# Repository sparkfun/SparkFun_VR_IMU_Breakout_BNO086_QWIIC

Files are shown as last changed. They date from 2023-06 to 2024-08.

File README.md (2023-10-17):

SparkFun VR IMU Breakout - BNO086 (Qwiic)
========================================

SparkFun VR IMU Breakout - BNO086 (Qwiic) (https://www.sparkfun.com/products/22857)

[*SparkFun VR IMU Breakout - BNO086 (Qwiic)(SEN-22857)*](https://www.sparkfun.com/products/22857)

The BNO086 IMU has a combination triple axis accelerometer/gyro/magnetometer packaged with an ARM Cortex M0+ running powerful algorithms.

Repository Contents
-------------------

* **/Documentation** - Datasheets, additional product information
* **/Hardware** - Eagle design files (.brd, .sch)
  * **/Production** - Production panel files (.brd)

Documentation
--------------
* **[Library](https://github.com/sparkfun/SparkFun_BNO08x_Arduino_Library)** - Arduino library for the BNO086 and variants BNO08X.
* **[Fritzing Part](https://github.com/sparkfun/Fritzing_Parts/blob/main/products/22857-sfe_vr_imu_breakout_bno086_9dof_accelerometer_gyro_magnetometer.fzpz)**
* **[Hookup Guide](https://docs.sparkfun.com/SparkFun_VR_IMU_Breakout_BNO086_QWIIC/introduction/)** - Basic hookup guide for the SparkFun VR IMU Breakout - BNO086.

Product Versions
----------------
* [SEN-22857](https://www.sparkfun.com/products/22857) - Initial release, v1.0

Version History
---------------
* v1.0 - Initial release

License Information
-------------------

This product is _**open source**_!

Please review the LICENSE.md file for license information.

If you have any questions or concerns on licensing, please contact technical support on our [SparkFun forums](https://forum.sparkfun.com/viewforum.php?f=152).

Distributed as-is; no warranty is given.

- Your friends at SparkFun.

_<COLLABORATION CREDIT>_

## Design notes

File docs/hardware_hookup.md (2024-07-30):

!!! note
    Unfortunately, users are not able to use an Arduino Uno or RedBoard with an ATmega328P due the demands of the BNO086 IC. We recommend using the ESP32.

    The Arduino Library was also tested to work with the SAMD51 as well! The pin connections between the microcontroller and sensor are the same, just make sure to reference the port name rather than the specific Arduino pin number. Make sure to also install the Arduino SAMD core and select the correct board definition.

### Connecting via Qwiic Port, Reset, & Interrupt Pins

!!! note
    As of v1.0.3, you will need to wire up the reset and interrupt pins. Using only the I<sup>2</sup>C port was not sufficient enough to get the BNO086 to work reliably with a microcontroller.  

    The I/O pins have also been changed for the reset and interrupt pins! Make sure to adjust your connections accordingly.

You will need a powerful microcontroller to process the data when using the BNO086. In this case, we used an ESP32 (we specifically tested the Arduino Library with the SparkFun IoT RedBoard - ESP32). Besides connecting a Qwiic cable, you also need to wire up the reset and interrupt pins. This is a more reliable connection and is recommended.

The table and image below shows the connections between the SparkFun IoT RedBoard - ESP32 and the BNO086. While you can use IC hooks for a temporary connection, we recommending soldering for a secure connection. You can choose between a combination of [header pins and jumper wires](https://learn.sparkfun.com/tutorials/how-to-solder-through-hole-soldering/all), or [stripping wire and soldering the wire](https://learn.sparkfun.com/tutorials/working-with-wire/all) directly to the board.

<div class="grid cards col-4" markdown>

-   <a href="https://learn.sparkfun.com/tutorials/how-to-solder-through-hole-soldering/all">
      <figure markdown>
        How to Solder: Through Hole Soldering
      </figure>
    </a>

    ---

    <a href="https://learn.sparkfun.com/tutorials/how-to-solder-through-hole-soldering/all">
      <b>How to Solder: Through Hole Soldering</b>
    </a>
<!-- ----------WHITE SPACE BETWEEN GRID CARDS---------- -->
-   <a href="https://learn.sparkfun.com/tutorials/working-with-wire/all">
      <figure markdown>
        Working with Wire
      </figure>
    </a>

    ---

    <a href="https://learn.sparkfun.com/tutorials/working-with-wire/all">
      <b>Working with Wire</b>
    </a>
<!-- ----------WHITE SPACE BETWEEN GRID CARDS---------- -->
</div>

<div style="text-align: center;">
    <table>
        <tr>
            <th style="text-align: center; border: solid 1px #cccccc;">RedBoard IoT - ESP32
            </th>
            <th style="text-align: center; border: solid 1px #cccccc;">VR IMU Breakout - BNO086
            </th>
        </tr>
        <tr>
            <td style="text-align: center; border: solid 1px #cccccc;" bgcolor="#f2dede"><font color="#000000">3.3V (3.3V, Qwiic Port)</font>
            </td>
            <td style="text-align: center; border: solid 1px #cccccc;" bgcolor="#f2dede"><font color="#000000">3.3V</font>
            </td>
        </tr>
        <tr>
            <td style="text-align: center; border: solid 1px #cccccc;" bgcolor="#DDDDDD"><font color="#000000">GND (GND, Qwiic Port)</font>
            </td>
            <td style="text-align: center; border: solid 1px #cccccc;" bgcolor="#DDDDDD"><font color="#000000">GND</font>
            </td>
        </tr>
        <tr>
            <td style="text-align: center; border: solid 1px #cccccc;" bgcolor="#fff3cd"><font color="#000000">SCL (D22, Qwiic Port)</font>
            </td>
            <td style="text-align: center; border: solid 1px #cccccc;" bgcolor="#fff3cd"><font color="#000000">SCL</font>
            </td>
        </tr>
        <tr>
            <td style="text-align: center; border: solid 1px #cccccc;" bgcolor="#cce5ff"><font color="#000000">SDA (D21, Qwiic Port)</font>
            </td>
            <td style="text-align: center; border: solid 1px #cccccc;" bgcolor="#cce5ff"><font color="#000000">SDA</font>
            </td>
        </tr>    
        <tr>
            <td style="text-align: center; border: solid 1px #cccccc;" bgcolor="#cce5ff"><font color="#000000">A4</font>
            </td>
            <td style="text-align: center; border: solid 1px #cccccc;" bgcolor="#cce5ff"><font color="#000000">INT</font>
            </td>
        </tr>
        <tr>
            <td style="text-align: center; border: solid 1px #cccccc;" bgcolor="#d4edda"><font color="#000000">A5</font>
            </td>
            <td style="text-align: center; border: solid 1px #cccccc;" bgcolor="#d4edda"><font color="#000000">RST</font>
            </td>
        </tr>
    </table>
</div>

<div style="text-align: center;">
  <table>
    <tr style="vertical-align:middle;">
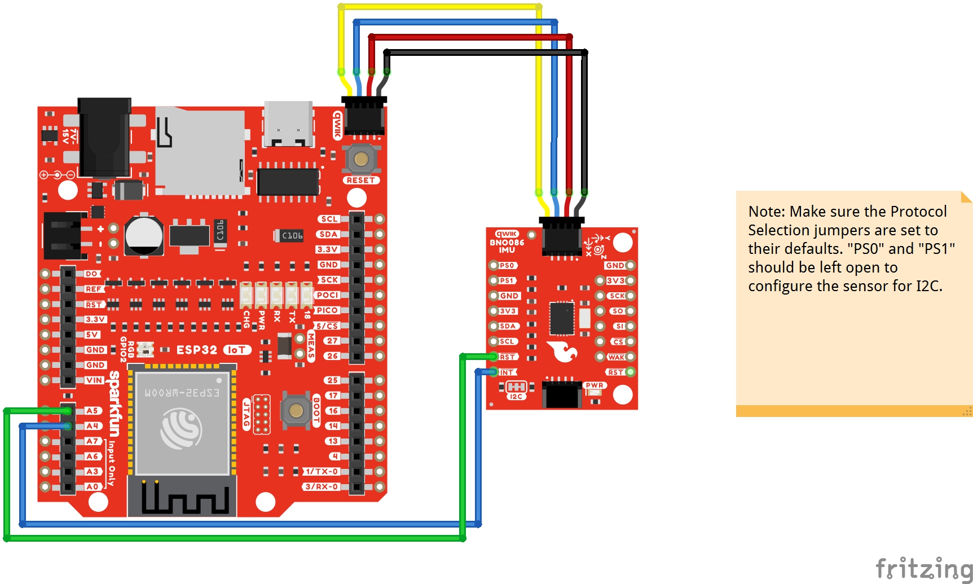
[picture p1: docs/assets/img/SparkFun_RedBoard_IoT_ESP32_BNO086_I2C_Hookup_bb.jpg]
Hookup with ESP32 between the BNO086 using the Qwiic Port, Interrupt, and Reset Pins
     <td style="text-align: center; vertical-align: middle;"></td>
    </tr>
  </table>
</div>

!!!note
    For users using a different communication protocol, make sure to adjust the solder joints for PS0 and PS1 before connecting to a UART or SPI port.

### Connecting via UART

For users interested in using the serial UART protocol to communicate with the sensor through a computer's USB port, you can connect a serial-to-USB connector directly to the board.

Before connecting, make sure to add a solder jumper on PS1 to configure the board for UART protocol as stated earlier in the Hardware Overview.

<div style="text-align: center;">
    <table>
        <tr>
            <th style="text-align: center; border: solid 1px #cccccc;">PS0
            </th>
            <th style="text-align: center; border: solid 1px #cccccc;">PS1
            </th>
            <th style="text-align: center; border: solid 1px #cccccc;">Interface
            </th>
            <th style="text-align: center; border: solid 1px #cccccc;">Note
            </th>
        </tr>
        <tr>
            <td style="text-align: center; border: solid 1px #cccccc;">0
            </td>
            <td style="text-align: center; border: solid 1px #cccccc;">0
            </td>
            <td style="text-align: center; border: solid 1px #cccccc;">I<sup>2</sup>C
            </td>
            <td style="text-align: center; border: solid 1px #cccccc;">
            </td>
        </tr>
        <tr>
            <td style="text-align: center; border: solid 1px #cccccc;">1
            </td>
            <td style="text-align: center; border: solid 1px #cccccc;">0
            </td>
            <td style="text-align: center; border: solid 1px #cccccc;">UART-RVC
            </td>
            <td style="text-align: center; border: solid 1px #cccccc;">
            </td>
        </tr>
        <tr>
            <td style="text-align: center; border: solid 1px #cccccc;" bgcolor="#f2dede"><font color="#000000">0</font>
            </td>
            <td style="text-align: center; border: solid 1px #cccccc;" bgcolor="#f2dede"><font color="#000000">1</font>
            </td>
            <td style="text-align: center; border: solid 1px #cccccc;" bgcolor="#f2dede"><font color="#000000">UART</font>
            </td>
            <td style="text-align: center; border: solid 1px #cccccc;" bgcolor="#f2dede"><font color="#000000">Add solder blob to the jumper to set to 1.</font>
            </td>
        </tr>
        <tr>
            <td style="text-align: center; border: solid 1px #cccccc;">1
            </td>
            <td style="text-align: center; border: solid 1px #cccccc;">1
            </td>
            <td style="text-align: center; border: solid 1px #cccccc;"">SPI
            </td>
            <td style="text-align: center; border: solid 1px #cccccc;">
            </td>
        </tr>
    </table>
</div>

The table below shows how to connect the VR IMU Breakout BNO086's UART port to a Serial Basic. You can angle header pins against the PTHs and hold the boards together with one hand for a temporary connection. However, we recommending soldering to the connection for a reliable and secure connection. You can choose between a combination of [header pins and jumper wires](https://learn.sparkfun.com/tutorials/how-to-solder-through-hole-soldering/all), or [stripping wire and soldering the wire](https://learn.sparkfun.com/tutorials/working-with-wire/all) directly to the board.

<div style="text-align: center;">
    <table>
        <tr>
            <th style="text-align: center; border: solid 1px #cccccc;">VR IMU Breakout - BNO086
            </th>
            <th style="text-align: center; border: solid 1px #cccccc;">3.3V Serial Basic
            </th>
            <th style="text-align: center; border: solid 1px #cccccc;">Wire Color
            </th>
        </tr>
        <tr>
            <td style="text-align: center; border: solid 1px #cccccc;" bgcolor="#DDDDDD"><font color="#000000">GND</font>
            </td>
            <td style="text-align: center; border: solid 1px #cccccc;" bgcolor="#DDDDDD"><font color="#000000">GND</font>
            </td>
            <td style="text-align: center; border: solid 1px #cccccc;" bgcolor="#DDDDDD"><font color="#000000">BLK</font>
            </td>
        </tr>
        <tr>
            <td style="text-align: center; border: solid 1px #cccccc;" bgcolor="#C4A484"><font color="#ffffff"></font>
            </td>
            <td style="text-align: center; border: solid 1px #cccccc;" bgcolor="#C4A484"><font color="#ffffff">CTS</font>
            </td>
            <td style="text-align: center; border: solid 1px #cccccc;" bgcolor="#C4A484"><font color="#ffffff"></font>
            </td>
        </tr>
        <tr>
            <td style="text-align: center; border: solid 1px #cccccc;" bgcolor="#f2dede"><font color="#000000">3V3</font>
            </td>
            <td style="text-align: center; border: solid 1px #cccccc;" bgcolor="#f2dede"><font color="#000000">3.3V</font>
            </td>
            <td style="text-align: center; border: solid 1px #cccccc;" bgcolor="#f2dede"><font color="#000000"></font>
            </td>
        </tr>
        <tr>
            <td style="text-align: center; border: solid 1px #cccccc;" bgcolor="#ffdaaf"><font color="#000000">RXI</font>
            </td>
            <td style="text-align: center; border: solid 1px #cccccc;" bgcolor="#ffdaaf"><font color="#000000">TXO</font>
            </td>
            <td style="text-align: center; border: solid 1px #cccccc;" bgcolor="#ffdaaf"><font color="#000000"></font>
            </td>
        </tr>
        <tr>
            <td style="text-align: center; border: solid 1px #cccccc;" bgcolor="#fff3cd"><font color="#000000">TXO</font>
            </td>
            <td style="text-align: center; border: solid 1px #cccccc;" bgcolor="#fff3cd"><font color="#000000">RXI</font>
            </td>
            <td style="text-align: center; border: solid 1px #cccccc;" bgcolor="#fff3cd"><font color="#000000"></font>
            </td>
        </tr><tr>
            <td style="text-align: center; border: solid 1px #cccccc;" bgcolor="#d4edda"><font color="#000000"></font>
            </td>
            <td style="text-align: center; border: solid 1px #cccccc;" bgcolor="#d4edda"><font color="#000000">DTR</font>
            </td>
            <td style="text-align: center; border: solid 1px #cccccc;" bgcolor="#d4edda"><font color="#000000">GRN</font>
            </td>
        </tr>
    </table>
</div>

!!!note
    You will need to be careful when soldering header pins to the edge pins and the UART located at the center of the board. For users that solder header pins to the edge of the board to mate with a breadboard, you will need to solder header pins facing the other way for the UART header so that the center pins do not connect to the same rails. The same goes with users that are using right angle header pins as well.

    Of course, you can cut a [six wire jumper wire cable](https://www.sparkfun.com/products/10371) and wire strip them before connecting to the 1x6 header as well.

The UART interface is in the middle of the board, with the black and green pins labeled as BLK and GRN. As stated earlier, these serial pins have been arranged to work with our [Serial Basic](https://www.sparkfun.com/products/15096) board to make interfacing to a computer simple and fast. Once the header pins are soldered, align the GRN and BLK labels so that the serial connection is properly connected and slide the male header pins into the female header sockets.

<div style="text-align: center;">
  <table>
    <tr style="vertical-align:middle;">
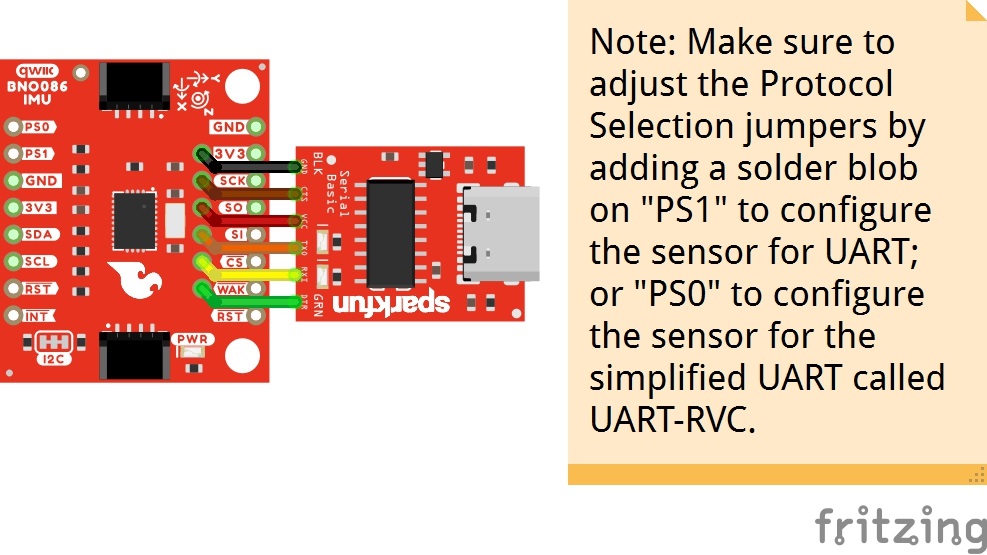
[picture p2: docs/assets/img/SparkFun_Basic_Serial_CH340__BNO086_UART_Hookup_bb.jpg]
Fritzing Diagram with FTDI Connected to BNO086 Breakout via UART Port
     <td style="text-align: center; vertical-align: middle;"></td>
    </tr>
  </table>
</div>

### Connecting via SPI

For users interested in using the [SPI protocol](https://learn.sparkfun.com/tutorials/serial-peripheral-interface-spi) to communicate with the sensor, there are few examples in the Arduino Library. You can use those examples as a basis to adjust the I<sup>2</sup>C examples to use it with SPI.

Before connecting, make sure to add a solder jumper on PS0 and PS1 to configure the board for SPI protocol as stated earlier in the Hardware Overview.

!!! note
    As of v1.0.3, the I/O pins have also been changed for the CS, reset, interrupt pins! Make sure to adjust your connections accordingly.

<div style="text-align: center;">
    <table>
        <tr>
            <th style="text-align: center; border: solid 1px #cccccc;">PS0
            </th>
            <th style="text-align: center; border: solid 1px #cccccc;">PS1
            </th>
            <th style="text-align: center; border: solid 1px #cccccc;">Interface
            </th>
            <th style="text-align: center; border: solid 1px #cccccc;">Note
            </th>
        </tr>
        <tr>
            <td style="text-align: center; border: solid 1px #cccccc;">0
            </td>
            <td style="text-align: center; border: solid 1px #cccccc;">0
            </td>
            <td style="text-align: center; border: solid 1px #cccccc;">I<sup>2</sup>C
            </td>
            <td style="text-align: center; border: solid 1px #cccccc;">
            </td>
        </tr>
        <tr>
            <td style="text-align: center; border: solid 1px #cccccc;">1
            </td>
            <td style="text-align: center; border: solid 1px #cccccc;">0
            </td>
            <td style="text-align: center; border: solid 1px #cccccc;">UART-RVC
            </td>
            <td style="text-align: center; border: solid 1px #cccccc;">
            </td>
        </tr>
        <tr>
            <td style="text-align: center; border: solid 1px #cccccc;">0
            </td>
            <td style="text-align: center; border: solid 1px #cccccc;">1
            </td>
            <td style="text-align: center; border: solid 1px #cccccc;">UART
            </td>
            <td style="text-align: center; border: solid 1px #cccccc;">
            </td>
        </tr>
        <tr>
            <td style="text-align: center; border: solid 1px #cccccc;" bgcolor="#f2dede"><font color="#000000">1</font>
            </td>
            <td style="text-align: center; border: solid 1px #cccccc;" bgcolor="#f2dede"><font color="#000000">1</font>
            </td>
            <td style="text-align: center; border: solid 1px #cccccc; "bgcolor="#f2dede"><font color="#000000">SPI</font>
            </td>
            <td style="text-align: center; border: solid 1px #cccccc;" bgcolor="#f2dede"><font color="#000000">Add solder blob to the jumpers to set to 1.</font>
            </td>
        </tr>
    </table>
</div>

The table below shows how to connect the SparkFun IoT RedBoard - ESP32 to the VR IMU Breakout BNO086's SPI port. As stated earlier for the I<sup>2</sup>C, you could use IC hooks for initial testing. However, we recommending soldering to the connection for a reliable and secure connection. You can choose between a combination of [header pins and jumper wires](https://learn.sparkfun.com/tutorials/how-to-solder-through-hole-soldering/all), or [stripping wire and soldering the wire](https://learn.sparkfun.com/tutorials/working-with-wire/all) directly to the board.

<div style="text-align: center;">
    <table>
        <tr>
            <th style="text-align: center; border: solid 1px #cccccc;">RedBoard IoT - ESP32
            </th>
            <th style="text-align: center; border: solid 1px #cccccc;">VR IMU Breakout - BNO086
            </th>
        </tr>
        <tr>
            <td style="text-align: center; border: solid 1px #cccccc;" bgcolor="#f2dede"><font color="#000000">3.3V</font>
            </td>
            <td style="text-align: center; border: solid 1px #cccccc;" bgcolor="#f2dede"><font color="#000000">3.3V</font>
            </td>
        </tr>
        <tr>
            <td style="text-align: center; border: solid 1px #cccccc;" bgcolor="#DDDDDD"><font color="#000000">GND</font>
            </td>
            <td style="text-align: center; border: solid 1px #cccccc;" bgcolor="#DDDDDD"><font color="#000000">GND</font>
            </td>
        </tr>
        <tr>
            <td style="text-align: center; border: solid 1px #cccccc;" bgcolor="#cce5ff"><font color="#000000">D5</font>
            </td>
            <td style="text-align: center; border: solid 1px #cccccc;" bgcolor="#cce5ff"><font color="#000000">CS</font>
            </td>
        </tr>
        <tr>
            <td style="text-align: center; border: solid 1px #cccccc;" bgcolor="#ffdaaf"><font color="#000000">PICO (D23)</font>
            </td>
            <td style="text-align: center; border: solid 1px #cccccc;" bgcolor="#ffdaaf"><font color="#000000">SI</font>
            </td>
        </tr>
        <tr>
            <td style="text-align: center; border: solid 1px #cccccc;" bgcolor="#ffffff"><font color="#000000">POCI (D19)</font>
            </td>
            <td style="text-align: center; border: solid 1px #cccccc;" bgcolor="#ffffff"><font color="#000000">SO</font>
            </td>
        </tr>
        <tr>
            <td style="text-align: center; border: solid 1px #cccccc;" bgcolor="#fff3cd"><font color="#000000">SCK (D18)</font>
            </td>
            <td style="text-align: center; border: solid 1px #cccccc;" bgcolor="#fff3cd"><font color="#000000">SCK</font>
            </td>
        </tr>    
        <tr>
            <td style="text-align: center; border: solid 1px #cccccc;" bgcolor="#cce5ff"><font color="#000000">A4</font>
            </td>
            <td style="text-align: center; border: solid 1px #cccccc;" bgcolor="#cce5ff"><font color="#000000">INT</font>
            </td>
        </tr>
        <tr>
            <td style="text-align: center; border: solid 1px #cccccc;" bgcolor="#d4edda"><font color="#000000">A5</font>
            </td>
            <td style="text-align: center; border: solid 1px #cccccc;" bgcolor="#d4edda"><font color="#000000">RST</font>
            </td>
        </tr>
    </table>
</div>

<div style="text-align: center;">
  <table>
    <tr style="vertical-align:middle;">
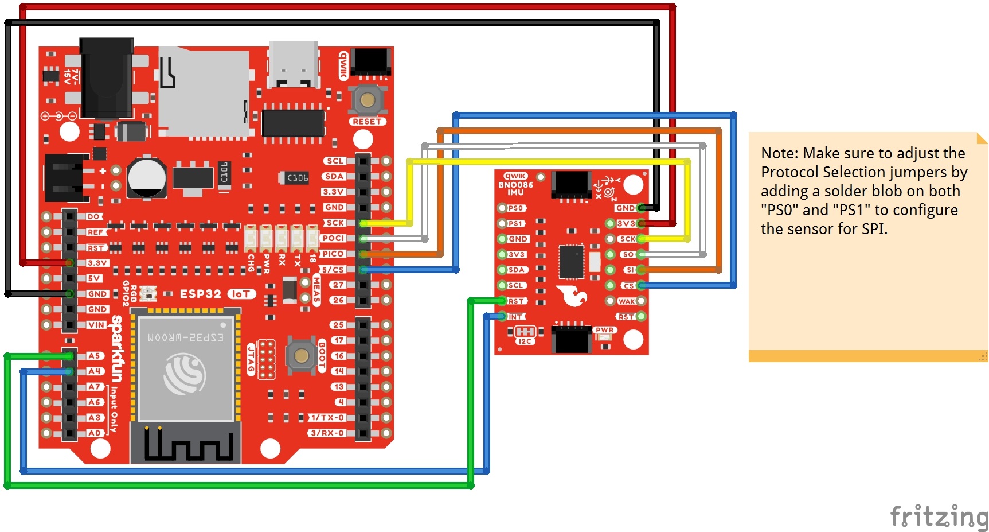
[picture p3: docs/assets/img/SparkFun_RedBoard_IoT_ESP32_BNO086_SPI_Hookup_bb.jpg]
Fritzing Diagram with ESP32 Connected to BNO086 Breakout via SPI Port
     <td style="text-align: center; vertical-align: middle;"></td>
    </tr>
  </table>
</div>

!!! note
    For users that are connecting the BNO086 to a MicroMod Machine Learning Board and MicroMod Artemis Processor, you will need to redefine a few pins. We recommend redefining the following pins in the example code.

    ``` c++
    #define BNO08X_CS   PWM0
    #define BNO08X_INT  D0
    #define BNO08X_RST  D1
    ```

    Note that SPI_CS on the MicroMod Machine Learning Board is only routed to the CS pin for the microSD card. D0 is also used as the CS pin for the on-board camera via SPI. D0 will work but if you are using a camera, then this would cause a conflict. A good alternative pin to use in this case would be PWM1.

    ``` c++
    #define BNO08X_CS   PWM0
    #define BNO08X_INT  PWM1
    #define BNO08X_RST  D1
    ```

    Additionally, A0 and A1 are meant to be only used as input pins and for ADC. The MicroMod Artemis Processor has op amps and scaling from 3.3V to 3V on both of those analog pins.

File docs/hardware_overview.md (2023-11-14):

Let's look over a few characteristics of the BNO086 sensor so we know a bit more about how it behaves. These characteristics were taken from the datasheet. For more information, make sure to check out the datasheet that is linked in the Resources section.

<div style="text-align: center;">
  <table>
    <tr style="vertical-align:middle;">
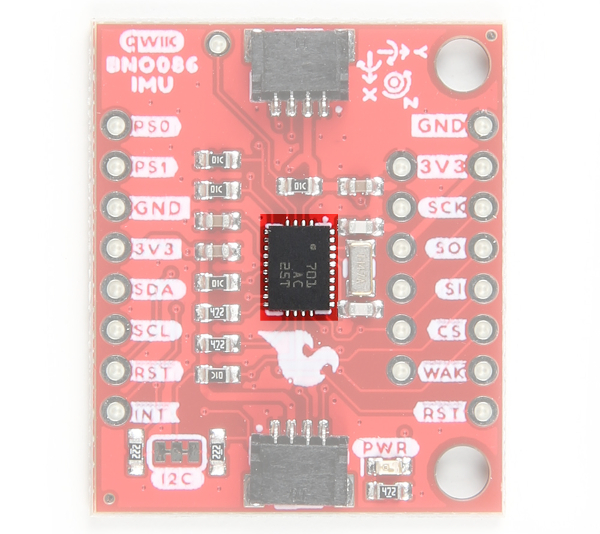
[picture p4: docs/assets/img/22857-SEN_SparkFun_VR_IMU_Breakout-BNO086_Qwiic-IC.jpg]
BNO086 Highlighted
     <td style="text-align: center; vertical-align: middle;"></td>
    </tr>
  </table>
</div>

* I<sup>2</sup>C (Default): Up to 400kHz
* SPI: Up to 3MHz
* UART: 3Mbps
* Rotation Vector
    * Dynamic Error: 3.5°
    * Static Error: 2.0°
* Gaming Rotation Vector
    * Dynamic Error: 2.5°
    * Static Error: 1.5°
    * Dynamic Heading Drift: 0.5° / min
* Geomagnetic Rotation Vector
    * Dynamic Rotation Error: 4.5°
    * Static Rotation Error: 3.0°
* Gravity Angle Error: 1.5°
* Linear Acceleration Accuracy: 0.35m/s<sup>2</sup>
* Accelerometer Accuracy: 0.3m/s<sup>2</sup>
* Gyroscope Accuracy: 3.1° / sec
* Magnetometer Accuracy: 1.4µT

!!!note
    Keep in mind the location of the labels on the top and bottom of the board. When rotating the board about the x-axis to view the bottom labels, you will notice that the letters are not right side up. You will need to rotate the board about the y-axis to view the letters.
    <div style="text-align: center;">
      <table>
        <tr style="vertical-align:middle;">
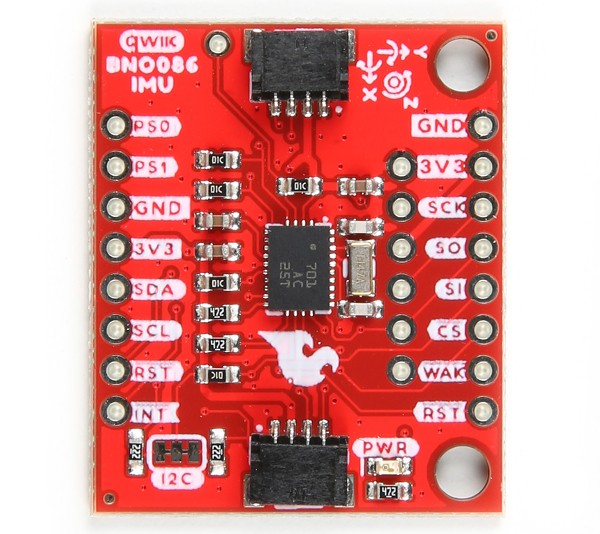
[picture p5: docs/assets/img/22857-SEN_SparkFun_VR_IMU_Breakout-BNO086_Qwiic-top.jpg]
         <td style="text-align: center; vertical-align: middle;"></td>
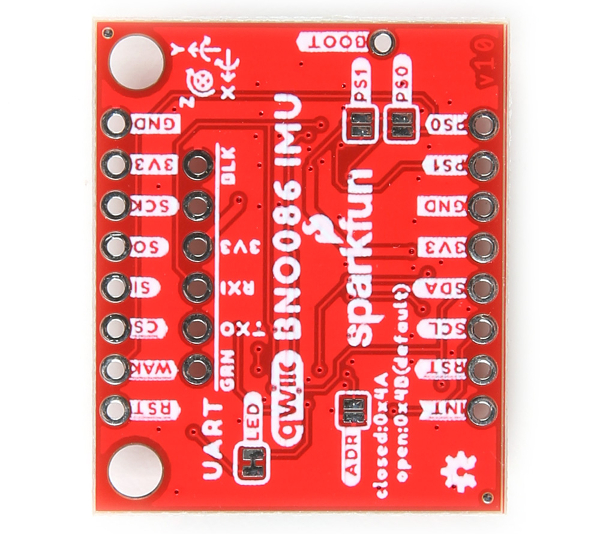
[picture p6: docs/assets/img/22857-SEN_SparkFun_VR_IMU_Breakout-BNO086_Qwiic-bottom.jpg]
         <td style="text-align: center; vertical-align: middle;"></td>
        </tr>
      </table>
    </div>

### Power

The operating voltage is between 2.4V-3.6V (note that V<sub>DDIO</sub> and V<sub>DD</sub> are tied together on the breakout board). We will assume that users will be using this with the Qwiic Connect System and a 3.3V microcontroller, which is typically **3.3V**. We recommend matching the logic levels so that they are the same as the operating voltage (e.g. _3.3V_).  You can apply 3.3V to the board from the 3V3 pin on either edge of the board, in the middle of the board, or either of the Qwiic connectors. There are also a few GND pins located throughout the board and via the Qwiic connectors.

<div style="text-align: center;">
  <table>
    <tr style="vertical-align:middle;">
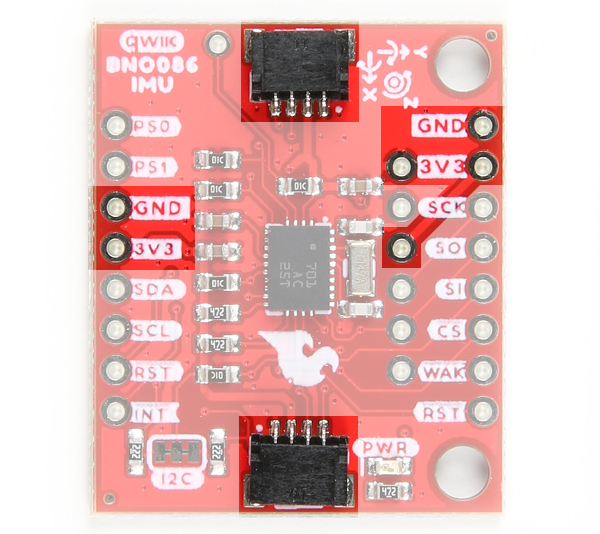
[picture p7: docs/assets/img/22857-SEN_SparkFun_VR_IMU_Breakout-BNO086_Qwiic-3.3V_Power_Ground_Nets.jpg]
3.3V Power and Ground Nets
     <td style="text-align: center; vertical-align: middle;"></td>
    </tr>
  </table>
</div>

### I<sup>2</sup>C and Qwiic Connectors

The board includes two Qwiic connectors on each side of the board. For users that need to solder directly to the board, the pins are also broken out on the edge PTH. The I<sup>2</sup>C data and clock lines are also tied to 2.2k&ohm; pull-up resistors. The BNO086 supports standard fast mode and can communicate over this interface at up to 400kHz.

<div style="text-align: center;">
  <table>
    <tr style="vertical-align:middle;">
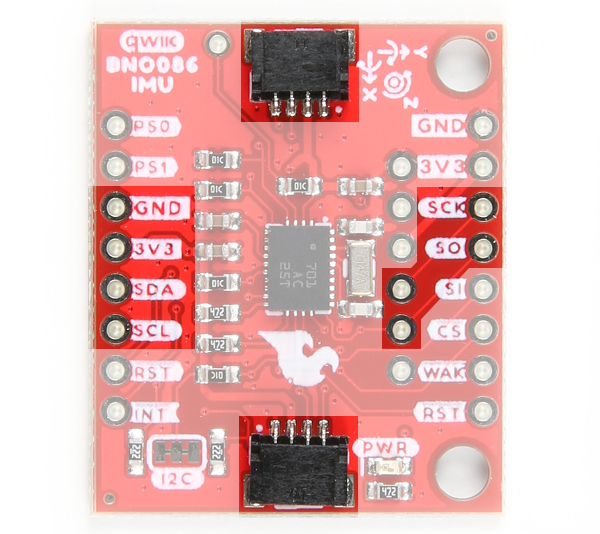
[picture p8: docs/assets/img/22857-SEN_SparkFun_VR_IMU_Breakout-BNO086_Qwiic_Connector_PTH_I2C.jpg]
I2C Qwiic Connectors and PTH
     <td style="text-align: center; vertical-align: middle;"></td>
    </tr>
  </table>
</div>

The default address of the board is set to **0x4B**. The alternative address is _0x4A_. The protocol selection is also set for I<sup>2</sup>C by default. These can be adjusted based on the jumpers on the back of the board. For more information, check out the section about the jumpers.

!!!note
    The timing for the BNO086 is finicky on the I<sup>2</sup>C port and the Arduino Library v1.0 does not currently support more than one BNO086 on the same line. We also do not recommend using a Qwiic Mux between the microcontroller and BNO086 to ensure that the packets are sent reliably.

### SPI

A few of the SPI pins have more than one function. We'll focus on the four SPI pins below. The image will also highlight the pins that are tied together.

* **SO** &mdash; This is an output pin for POCI (Peripheral Out, Controller In). The device sends data to the controller on this line. This is also connected to the I<sup>2</sup>C's SDA and UART's TXO pin.
* **SI** &mdash; This is an input pin for the PICO (Peripheral In, Controller Out). Device receives data from the microcontroller on this line. This is also connected to the address jumper. Tie to 3.3V to change I<sup>2</sup>C address from **0x4A** to _0x4B_.
* **SCK** &mdash; This is an input for the SPI clock. This is also connected to the I<sup>2</sup>C's SCL and UART's RXI pin.
* <b><span style="text-decoration:overline">CS</span></b> &mdash; This is an input for the SPI chip select pin and active low. It is used to as a clock signal to synchronize controller and peripheral.

<div style="text-align: center;">
  <table>
    <tr style="vertical-align:middle;">
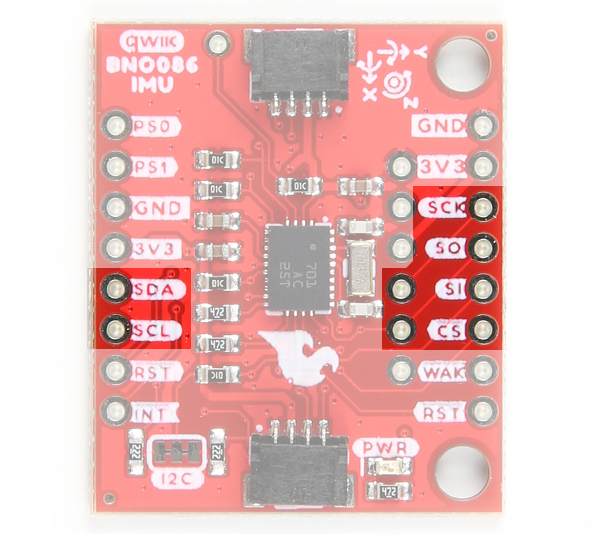
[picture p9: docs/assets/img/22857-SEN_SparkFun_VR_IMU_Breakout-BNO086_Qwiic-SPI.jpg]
SPI
     <td style="text-align: center; vertical-align: middle;"></td>
    </tr>
  </table>
</div>

The protocol selection is set for I<sup>2</sup>C by default. You will need to adjust the jumpers on the back of the board for SPI. For more information, check out the section about the jumpers.

!!!note
    You may not recognize the PICO/POCI labels for SPI pins. SparkFun has joined with other members of OSHWA in a resolution to move away from using "Master" and "Slave" to describe signals between the controller and the peripheral. Check out [this page](https://www.sparkfun.com/spi_signal_names)for more on our reasoning behind this change. You can also see OSHWA's resolution [here](https://www.oshwa.org/a-resolution-to-redefine-spi-signal-names).

!!!note
    The Arduino Library is focused more on I<sup>2</sup>C compared to the SPI protocol. To browse a few of the examples that are available, make sure to [check out the SPI folder](https://github.com/sparkfun/SparkFun_BNO08x_Arduino_Library/tree/main/examples/SPI) after installing the Arduino Library.

### UART

In the middle of the board, are the serial UART pins. You can also use the UART interface at up to 3 Mbps or a simplified UART called UART-RVC (Used for Robotic Vacuum Cleaners) which can run at a data rate of 115200 kbps. These serial pins have been arranged to work with our Serial Basic board to make interfacing to a computer simple and fast.  This is for users that want to connect to a 3.3V UART-to-Serial converter (such as the [Serial Basic Breakouts](https://www.sparkfun.com/products/15096)). The GRN and BLK labels help align the serial connection properly. The UART pins have more than one function. We'll focus on the two UART pins below. The image will also highlight the pins that are tied together.

* **TXO** &mdash; This is an output pin for serial UART transmit pin. Data is sent out to the microcontroller to this pin. This is also connected to the I<sup>2</sup>C's SDA and SPI's POCI pin.
* **RXI** &mdash; This is an input pin for the serial UART receive pin. Data is received from the microcontroller to this pin. This is also connected to the I<sup>2</sup>C's SCL and SPI's SCK pin.

<div style="text-align: center;">
  <table>
    <tr style="vertical-align:middle;">
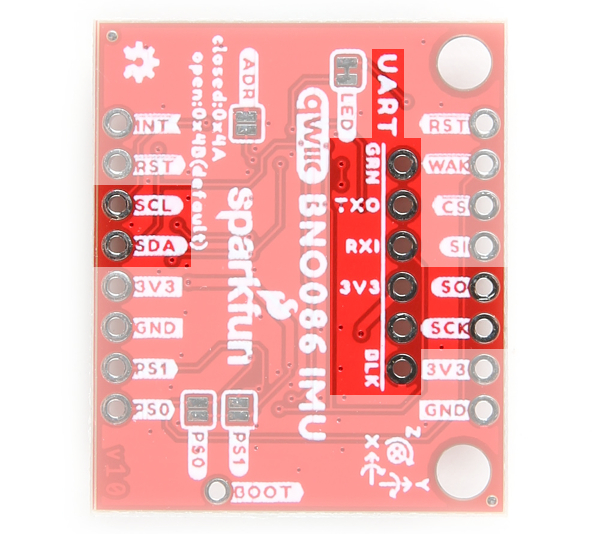
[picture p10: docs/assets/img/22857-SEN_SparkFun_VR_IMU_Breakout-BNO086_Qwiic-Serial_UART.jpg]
Serial UART
     <td style="text-align: center; vertical-align: middle;"></td>
    </tr>
  </table>
</div>

The protocol selection is set for I<sup>2</sup>C by default. You will need to adjust the jumpers on the back of the board for the serial UART. For more information, check out the section about the jumpers.

### Reference Axis

For easy reference, we've documented the IMU's vectors with 3D Cartesian coordinate axes on the top and bottom side of the board. Make sure to orient and mount the board correctly so you know which way the BNO086's data is pointing. Remember, it's all relative.

<div style="text-align: center;">
  <table>
    <tr style="vertical-align:middle;">
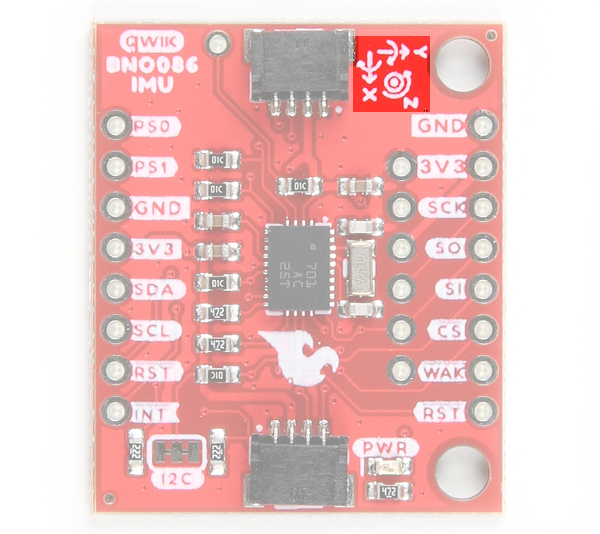
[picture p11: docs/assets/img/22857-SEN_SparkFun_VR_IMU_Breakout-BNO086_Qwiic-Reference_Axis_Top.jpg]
Reference Axis on the Top Side
     <td style="text-align: center; vertical-align: middle;"></td>
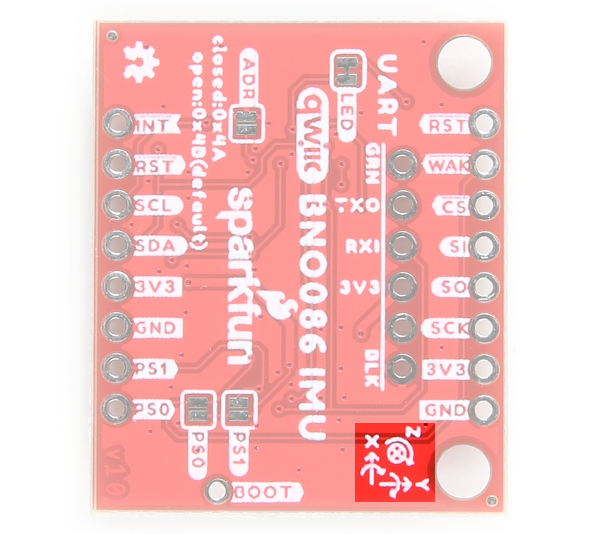
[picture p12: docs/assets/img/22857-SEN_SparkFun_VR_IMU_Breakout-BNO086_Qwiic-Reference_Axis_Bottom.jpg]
Reference Axis on the Bottom Side
     <td style="text-align: center; vertical-align: middle;"></td>
    </tr>
  </table>
</div>

### LED

There is one LED on the board. The LED lights up when the board is powered with 3.3V. There is a jumper on the back if you decide to disable the LED.

<div style="text-align: center;">
  <table>
    <tr style="vertical-align:middle;">
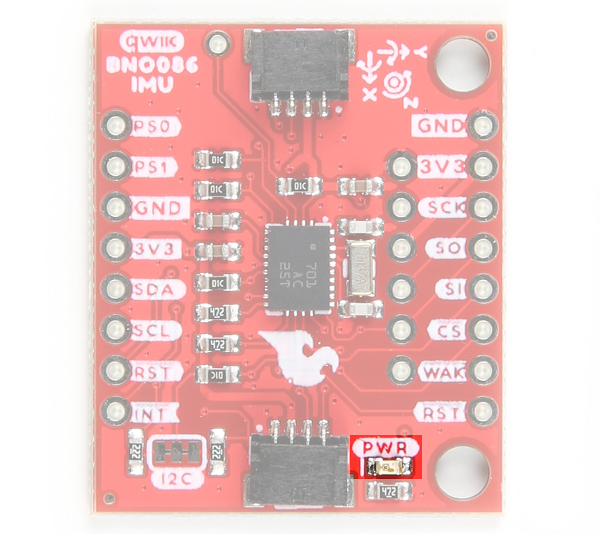
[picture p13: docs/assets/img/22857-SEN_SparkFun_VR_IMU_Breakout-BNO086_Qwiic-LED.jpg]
LED
     <td style="text-align: center; vertical-align: middle;"></td>
    </tr>
  </table>
</div>

### Miscellaneous Pins

Below are some additional pins that are broken out for the BNO086.

* <b><span style="text-decoration:overline">RST</span></b> &mdash; The reset signal pin is an input pin and it is active low. Pull it low to reset the IC. You can find this on both sides of the board.
* <b><span style="text-decoration:overline">INT</span></b> &mdash; The interrupt pin is an output pin and active low. When BNO080 is ready for communication, it will pull this pin low.
* <b><span style="text-decoration:overline">WAK</span></b> &mdash; The wake signal pin is an input pin and it is active low. Pull it low to wake the BNO086's processor from sleep mode.
* **BOOT** &mdash; The BOOT pin next to the Qwiic connector is necessary for configuration of the communication mode. If the BOOT pin is low upon reset or power up, the chip will go into bootloader mode to allow for programming of new firmware.

<div style="text-align: center;">
  <table>
    <tr style="vertical-align:middle;">
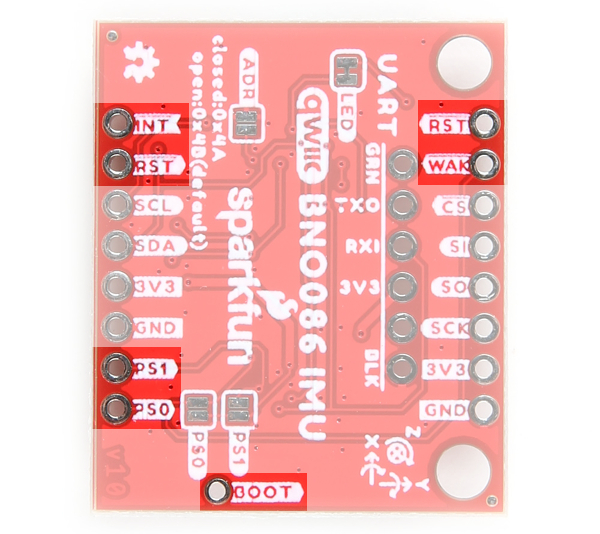
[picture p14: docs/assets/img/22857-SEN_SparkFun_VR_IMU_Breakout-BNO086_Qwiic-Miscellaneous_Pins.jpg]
Miscellaneous Pins
     <td style="text-align: center; vertical-align: middle;"></td>
    </tr>
  </table>
</div>

### Jumpers

There are a few jumper pads available on the top and bottom of the board. Most of the jumpers are on the bottom. For more information on modifying the jumpers, check out our [tutorial on working with jumper pads and PCB traces](https://learn.sparkfun.com/tutorials/how-to-work-with-jumper-pads-and-pcb-traces).

* **I2C** &mdash; On the top side of the board, the I<sup>2</sup>C jumpers are closed by default. By cutting the traces between the jumper pads, it will disconnect to the 2.2kΩ pull-up resistors for the I<sup>2</sup>C bus. Most of the time you can leave these alone unless your project requires you to [connect the pull-up resistors](https://learn.sparkfun.com/tutorials/i2c/all#i2c-at-the-hardware-level).
* **LED** &mdash; On the bottom side of the board, the LED jumper is closed by default. Cut this trace to disable the power LED that is connected to 3.3V.
* **ADR** &mdash; On the bottom side of the board, the address pin selects the I<sup>2</sup>C address of the BNO086 and it is open by default. As indicated by the silkscreen, the address is currently `0x48`. To change the address to the alternative value of `0x4A`, simply add a solder blob between the two pads. Make sure to also modify your code to adjust for the alternative address.
* **PS0** &mdash; On the bottom side of the board, the PS0 is used with PS1. The acronym stands for Protocol Selection and it is used for the configuration of the communication interface. It is open by default (i.e. 0). Adding a solder blob on either will change the configuration from I<sup>2</sup>C to UART-RVC, UART, or SPI. Check out the table below to configure the jumpers.
* **PS1** &mdash; On the bottom side of the board, the PS is used with PS0. The acronym stands for Protocol Selection and it is used for the configuration of the communication interface. It is open by default (i.e. 0). Adding a solder blob on either will change the configuration from I<sup>2</sup>C to UART-RVC, UART, or SPI. Check out the table below to configure the jumpers.

<div style="text-align: center;">
  <table>
    <tr style="vertical-align:middle;">
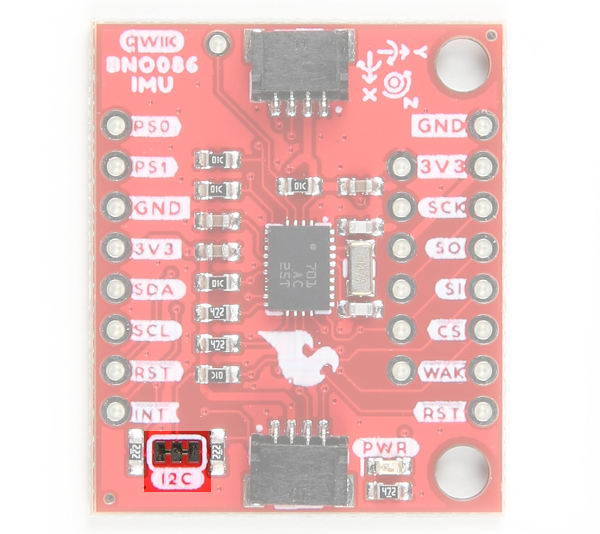
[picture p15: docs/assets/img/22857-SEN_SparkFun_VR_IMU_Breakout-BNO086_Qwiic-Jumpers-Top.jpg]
Jumpers on Top Side
     <td style="text-align: center; vertical-align: middle;"></td>
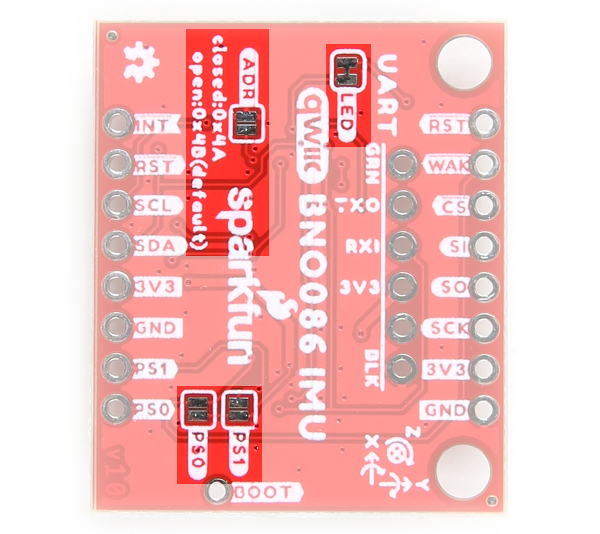
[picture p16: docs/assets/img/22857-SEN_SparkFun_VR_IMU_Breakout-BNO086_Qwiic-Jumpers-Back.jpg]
Jumpers on Bottom Side
     <td style="text-align: center; vertical-align: middle;"></td>
    </tr>
  </table>
</div>

You can use the **PS0** and **PS1** jumpers to change the communication protocol that the BNO080 is using. The jumpers are left open (0) by default, and the following configurations will allow for their corresponding communications protocols.

<div style="text-align: center;">
    <table>
        <tr>
            <th style="text-align: center; border: solid 1px #cccccc;">PS0
            </th>
            <th style="text-align: center; border: solid 1px #cccccc;">PS1
            </th>
            <th style="text-align: center; border: solid 1px #cccccc;">Interface
            </th>
        </tr>
        <tr>
            <td style="text-align: center; border: solid 1px #cccccc;">0
            </td>
            <td style="text-align: center; border: solid 1px #cccccc;">0
            </td>
            <td style="text-align: center; border: solid 1px #cccccc;">I<sup>2</sup>C

            </td>
        </tr>
        <tr>
            <td style="text-align: center; border: solid 1px #cccccc;">1
            </td>
            <td style="text-align: center; border: solid 1px #cccccc;">0
            </td>
            <td style="text-align: center; border: solid 1px #cccccc;">UART-RVC
            </td>
        </tr>
        <tr>
            <td style="text-align: center; border: solid 1px #cccccc;">0
            </td>
            <td style="text-align: center; border: solid 1px #cccccc;">1
            </td>
            <td style="text-align: center; border: solid 1px #cccccc;">UART
            </td>
        </tr>
        <tr>
            <td style="text-align: center; border: solid 1px #cccccc;">1
            </td>
            <td style="text-align: center; border: solid 1px #cccccc;">1
            </td>
            <td style="text-align: center; border: solid 1px #cccccc;">SPI
            </td>
        </tr>
    </table>
</div>

### Board Dimensions

The board is 1.0" x 1.2" (25.4mm x 30.48mm), which is slightly longer than a typical 1.0"x1.0" Qwiic sized board. There are 2x mounting holes on one side of the board.

<div style="text-align: center;">
  <table>
    <tr style="vertical-align:middle;">
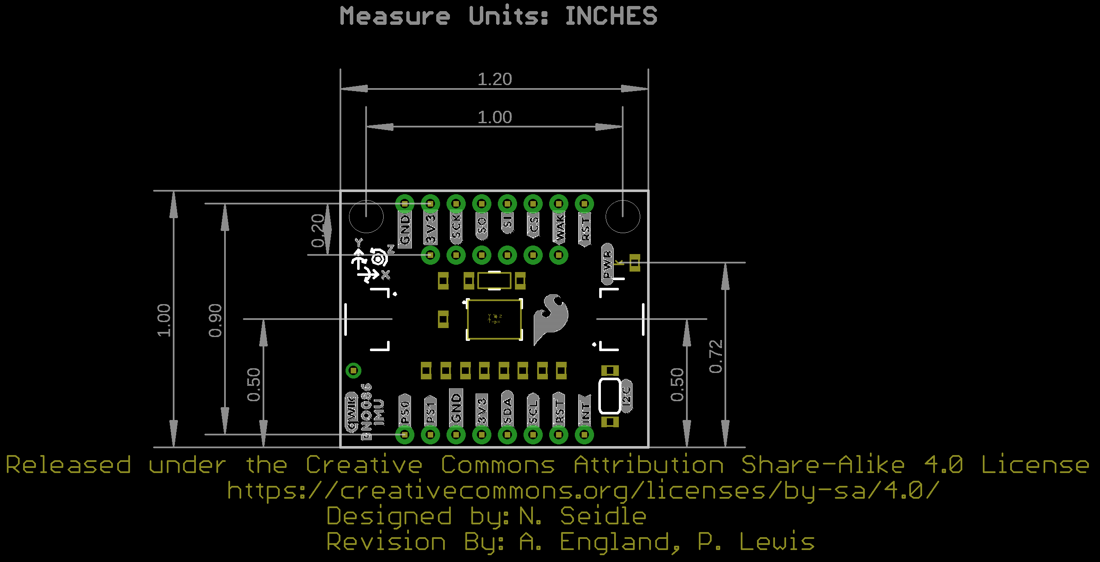
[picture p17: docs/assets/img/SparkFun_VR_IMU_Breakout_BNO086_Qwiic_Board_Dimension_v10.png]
Board Dimensions
     <td style="text-align: center; vertical-align: middle;"></td>
    </tr>
  </table>
</div>

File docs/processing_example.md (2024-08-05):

This section is a fun bonus example that rotates a cube in Processing based on the BNO086's sensor rotation vector's readings. This extra example is not included in the SparkFun VR IMU BNO08X Arduino Library as it requires Processing. To grab it, go ahead and download or clone the [SparkFun VR IMU Breakout BNO086 QWIIC hardware repo](https://github.com/sparkfun/SparkFun_VR_IMU_Breakout_BNO086_QWIIC).

<div style="text-align: center"><a href="https://github.com/sparkfun/SparkFun_VR_IMU_Breakout_BNO086_QWIIC/archive/refs/heads/main.zip" target="download_BNO086_hardware_repo" class="md-button">Download SparkFun VR IMU Breakout - BNO086 Qwiic GitHub Hardware Repo (ZIP)</a></div>

!!! note
    The modified Arduino example has been updated to reflect the changes in Arduino Library v1.0.3.

### Upload Modified Arduino Example 1's Rotation Vector

Processing listens for serial data, so we'll need to get our Arduino (i.e. RedBoard IoT - ESP32) to produce serial data that makes sense to Processing. For this case, we will be using the example 1's rotation vector. However, we will be modifying it by sending only the comma separated values to the serial port.

After unzipping the compressed files, navigate to the hardware repo's folder and open the example: ... **SparkFun_VR_IMU_Breakout_BNO086_QWIIC** > **Software** > **Arduino** > **Example_01_RotationVector_MOD** > **Example_01_RotationVector_MOD.ino**. This modified sketch simply prints a list of our quaternions separated by a comma over serial for Processing to listen to. You will also notice that the sequence of values is adjusted slightly for the Processing by moving the Real before the real value before i, j, and k. We also adjusted the baud rate to allow Processing some time to process the data.

Select your board in the Tools menu (in our case **SparkFun ESP32 IoT RedBoard**) and the correct Port it enumerated on. Then click "Upload". After uploading the code, open the [Serial Monitor](https://learn.sparkfun.com/tutorials/terminal-basics) or terminal emulator of your choice with the baud rate set to **9600**.

<div style="text-align: center;">
  <table>
    <tr style="vertical-align:middle;">
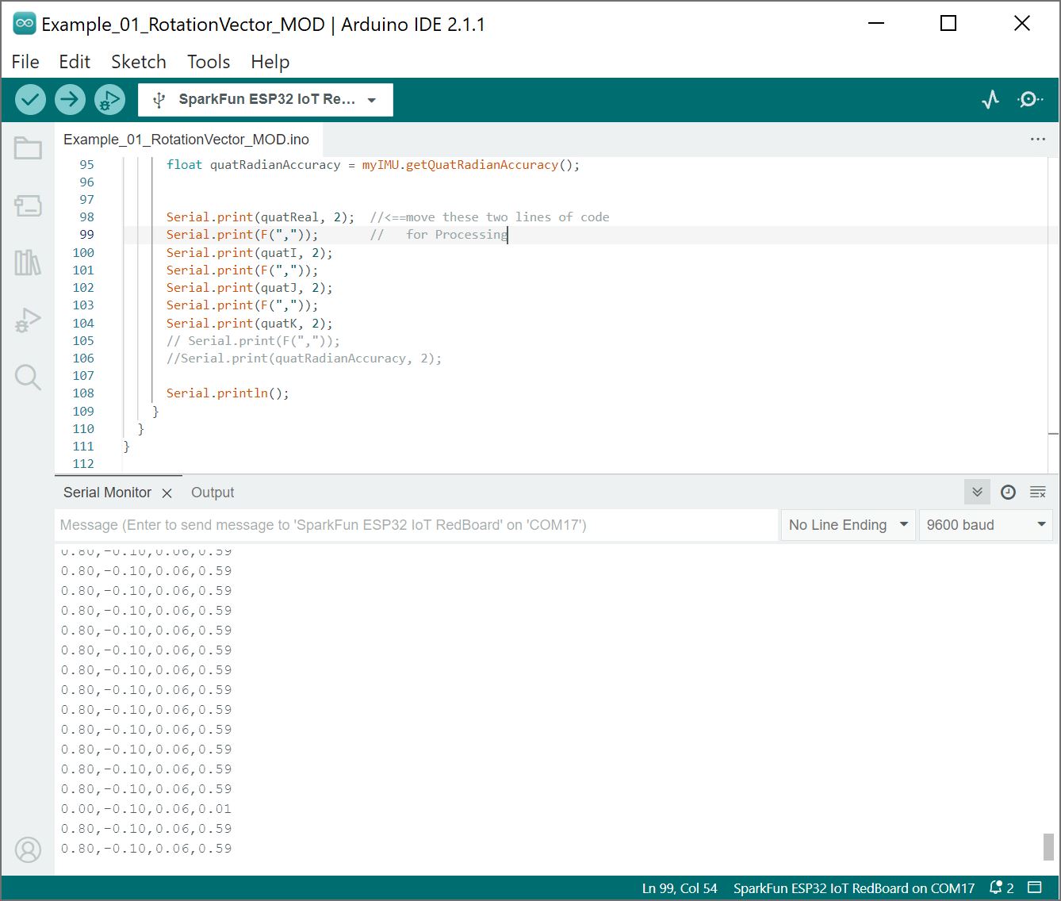
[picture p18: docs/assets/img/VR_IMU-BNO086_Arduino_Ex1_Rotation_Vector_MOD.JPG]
Output Modified Example 1 - Rotation Vector for Processing Example
     <td style="text-align: center; vertical-align: middle;"></td>
    </tr>
  </table>
</div>

### Run the "Serial Cube Rotate" Processing Demo

Once this sketch is uploaded, we need to tell Processing how to turn this data into a visualization. The Processing sketch to do this is located one folder above the Arduino sketch: ... **SparkFun_VR_IMU_Breakout_BNO086_QWIIC** > **Software** > **Processing** > **Serial_Cube_Rotate.pde**. Open the **Serial_Cube_Rotate.pde** file in Processing.

Attempting to run the Processing sketch will show us available serial ports in the debug window from this line of code:

```bash
myPort = new Serial(this, Serial.list()[0], 9600);
```

Identify which serial port your Arduino is on. For instance, my RedBoard IoT - ESP32 is on COM17, which corresponds to `[6]` in the image below, so I will need to change `0` to `6` in the following line to ensure Processing is listening to the correct serial port.

<div style="text-align: center;">
  <table>
    <tr style="vertical-align:middle;">
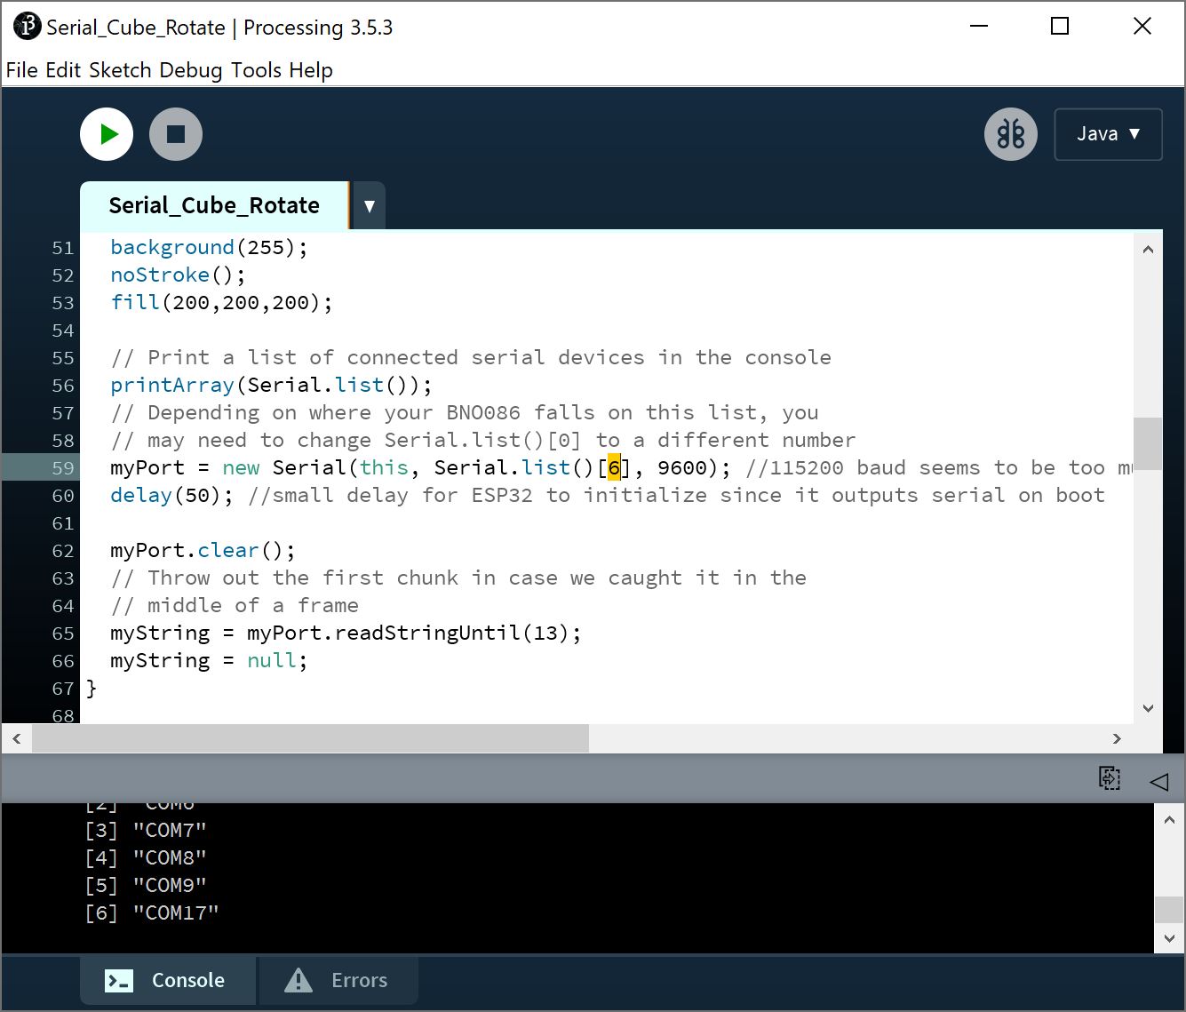
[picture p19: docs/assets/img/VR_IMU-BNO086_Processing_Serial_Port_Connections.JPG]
Adjusting Processing Example's Serial Port
     <td style="text-align: center; vertical-align: middle;"></td>
    </tr>
  </table>
</div>

Once we've done this, we should be able to run the Processing sketch and it will give us a nice visualization of how our IMU is oriented in 3D space as a cube. Try rotating the IMU to see how it responds. You should get a neat little output like the one in the below GIF with Nick Poole's hand.

<div style="text-align: center;">
  <table>
    <tr style="vertical-align:middle;">
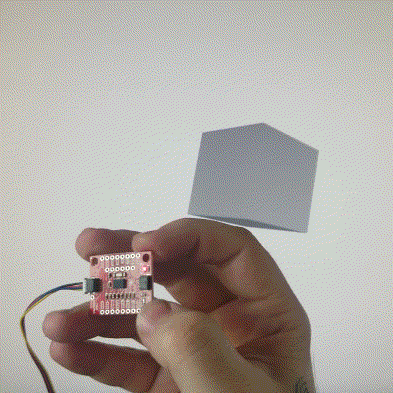
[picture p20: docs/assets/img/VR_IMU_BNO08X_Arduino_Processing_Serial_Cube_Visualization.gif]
Processing Example with Nick Poole Rotating the VR IMU
     <td style="text-align: center; vertical-align: middle;"></td>
    </tr>
  </table>
</div>

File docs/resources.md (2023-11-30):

Now that you've successfully got your SparkFun Qwiic VR IMU Breakout (BNO086) up and running, it's time to incorporate it into your own project! For more information, check out the resources below:

* [Schematic (PDF)](../assets/board_files/SparkFun_VR_IMU_Breakout_BNO086_QWIIC_Schematic_v10.pdf)
* [Eagle Files (ZIP)](../assets/board_files/SparkFun_VR_IMU_Breakout_BNO086_QWIIC_v10.zip)
* [Board Dimensions (PNG)](../assets/img/SparkFun_VR_IMU_Breakout_BNO086_Qwiic_Board_Dimension_v10.png)
* BNO086
    * [Datasheet (PDF)](../assets/component_documentation/BNO080_085-Datasheet_v1.16.pdf)
    * [Migration Guide (PDF)](../assets/component_documentation/BNO080-BNO085-Migration-Guide.pdf)
    * [Tare Function Usage Guide (PDF)](../assets/component_documentation/BNO080-BNO085-Tare-Function-Usage-Guide.pdf)
    * [Sensor Hub Transport Protocol (PDF)](../assets/component_documentation/Sensor-Hub-Transport-Protocol.pdf)
    * [Sensor Calibration Procedure (PDF)](../assets/component_documentation/BNO080-BNO085-Sesnor-Calibration-Procedure.pdf)
* [Fritzing Part](https://github.com/sparkfun/Fritzing_Parts/blob/main/products/22857-sfe_vr_imu_breakout_bno086_9dof_accelerometer_gyro_magnetometer.fzpz)
* [Arduino Library](https://github.com/sparkfun/SparkFun_BNO08x_Arduino_Library) - SparkFun's Arduino Library for the BNO08X
* [Processing Library](https://github.com/postspectacular/toxiclibs/releases/tag/0021) - ToxicLibs v0021
* [GitHub Hardware Repo](https://github.com/sparkfun/SparkFun_VR_IMU_Breakout_BNO086_QWIIC)
* [SFE Product Showcase](https://www.youtube.com/embed/30WDbm8smP8)

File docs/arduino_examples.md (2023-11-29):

Now that we have our library installed, we can get started playing around with our examples to learn more about how the IMU behaves. From there we'll be able to build our own custom code to integrate the sensor into a project.

!!! note
    As of Arduino Library v1.0.3, the following line of code has been included for microcontrollers with built-in native USB (i.e. the SAMD51). This can be commented out when using the BNO086 in projects that are not using a Serial Terminal.

    <pre><code class="language-c">while(!Serial) delay(10); // Wait for Serial to become available.
    // Necessary for boards with native USB (like the SAMD51 Thing+).
    // For a final version of a project that does not need serial debug (or a USB cable plugged in),
    // Comment out this while loop, or it will prevent the remaining code from running.</code></pre>

### Example 1 - Rotation Vector

This first example gets us started taking a reading of our [complex valued rotation vector, or quaternion,](https://en.wikipedia.org/wiki/Quaternions_and_spatial_rotation) which tells us how we are oriented. Open the example by navigating to **File** > **Examples** > **SparkFun BNO08X Cortex Based IMU** > **Example_01_RotationVector**.

Select your board in the Tools menu (in our case **SparkFun ESP32 IoT RedBoard**) and the correct Port it enumerated on and click "Upload". After uploading the code, open the [Serial Monitor](https://learn.sparkfun.com/tutorials/terminal-basics) or terminal emulator of your choice with the baud rate set to **115200**.

You should see an output of the quaternion values (i.e. i, j, k, and real) and the accuracy in radians.

<div style="text-align: center;">
  <table>
    <tr style="vertical-align:middle;">
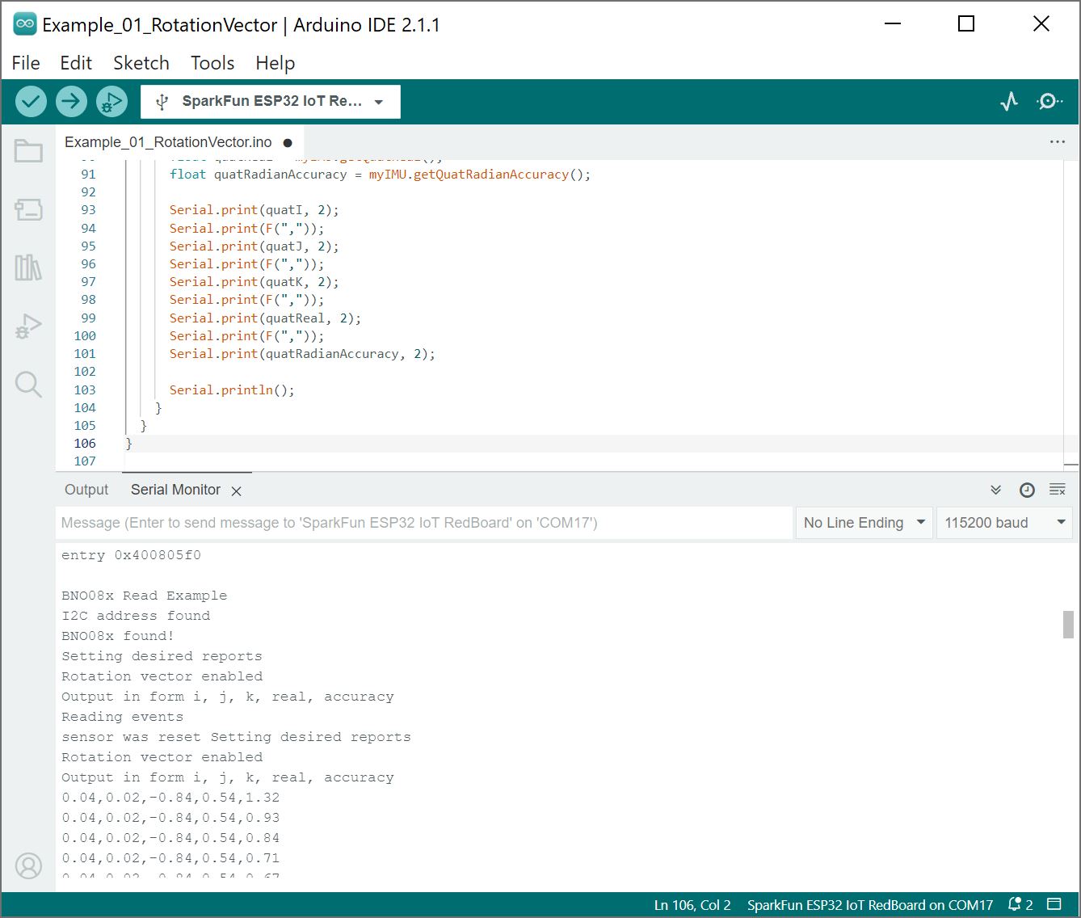
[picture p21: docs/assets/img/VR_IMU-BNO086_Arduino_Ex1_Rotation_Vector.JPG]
Output Example 1 - Rotation Vector
     <td style="text-align: center; vertical-align: middle;"></td>
    </tr>
  </table>
</div>

<div style="text-align: center;">
  <i>Having a hard time seeing output? Click on the image for a closer look.</i>
</div>

### Example 2 - Accelerometer

Examples 2 deals with pulling the accelerometer values from our sensor to figure out how it is moving. Open the example by navigating to **File** > **Examples** > **SparkFun BNO08X Cortex Based IMU** > **Example_02_Accelerometer**.

Select your board in the Tools menu (in our case **SparkFun ESP32 IoT RedBoard**) and the correct Port it enumerated on and click "Upload". After uploading the code, open the [Serial Monitor](https://learn.sparkfun.com/tutorials/terminal-basics) or terminal emulator of your choice with the baud rate set to **115200**.

You should see an output of the accelerometer values for x, y, and z in m/s<sup>2</sup>. If the breakout board is on the table with the z-axis pointed up to the ceiling, you should see a value close to the value of about +9.81 m/s. Of course, that value can vary depending on where you are on Earth](https://en.wikipedia.org/wiki/Gravity_of_Earth) or if the board is not fully rested on a flat table.

<div style="text-align: center;">
  <table>
    <tr style="vertical-align:middle;">
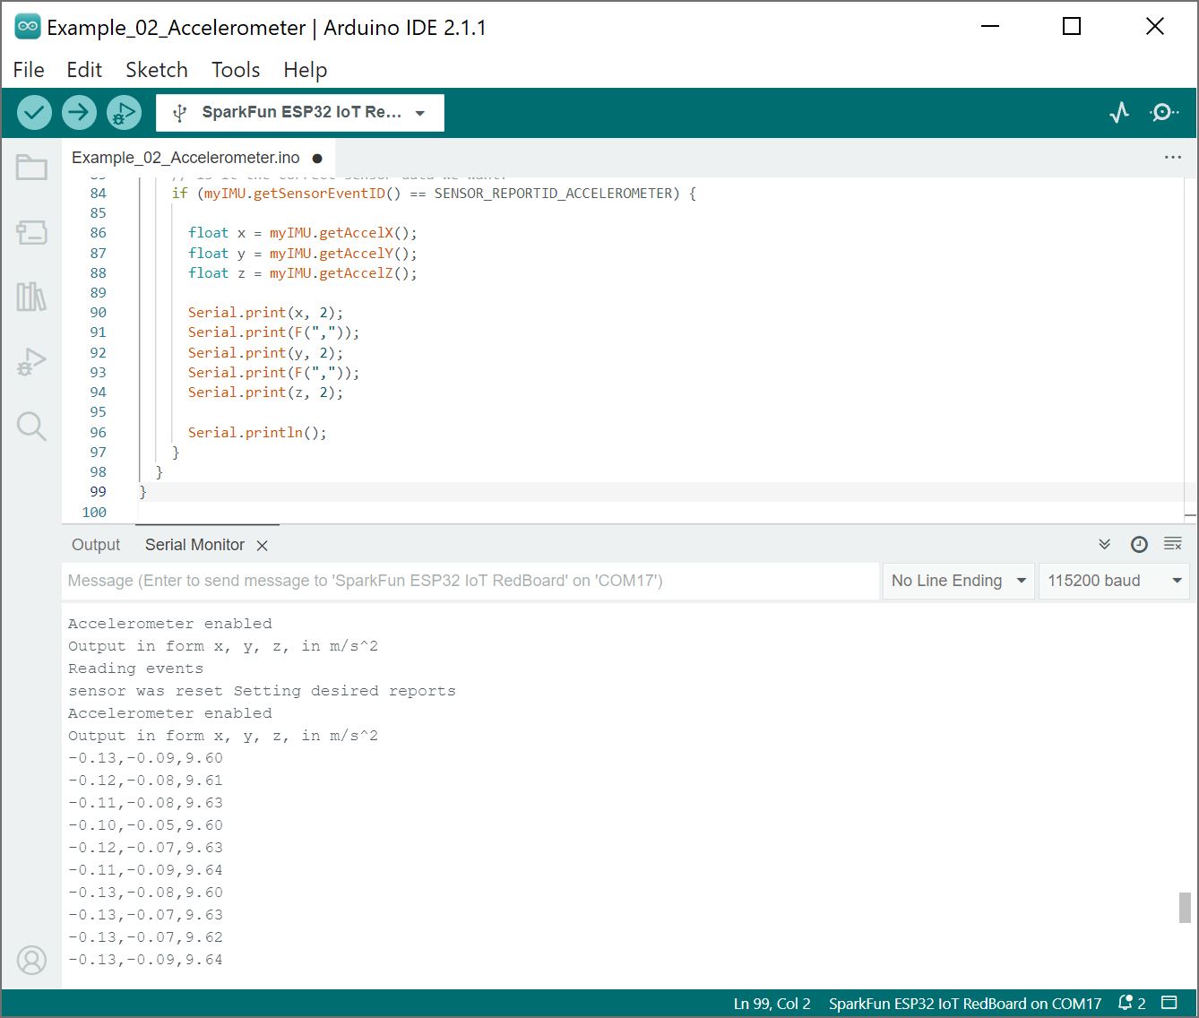
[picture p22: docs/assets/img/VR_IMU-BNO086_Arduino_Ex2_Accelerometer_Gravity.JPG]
Output Example 2 - Accelerometer
     <td style="text-align: center; vertical-align: middle;"></td>
    </tr>
  </table>
</div>

<div style="text-align: center;">
  <i>Having a hard time seeing output? Click on the image for a closer look.</i>
</div>

### Example 3 - Gyro

In example 3, we'll pull values from the IMU's gyroscope to get a vector for our angular velocity. Open the example by navigating to **File** > **Examples** > **SparkFun BNO08X Cortex Based IMU** > **Example_03_Gyro**.

Select your board in the Tools menu (in our case **SparkFun ESP32 IoT RedBoard**) and the correct Port it enumerated on and click "Upload". After uploading the code, open the [Serial Monitor](https://learn.sparkfun.com/tutorials/terminal-basics) or terminal emulator of your choice with the baud rate set to **115200**.

You should see the angular velocity for x, y, and z in radians/s. Try rotating the board about each axis. You should see the values change depending on the direction that you rotate the board.

<div style="text-align: center;">
  <table>
    <tr style="vertical-align:middle;">
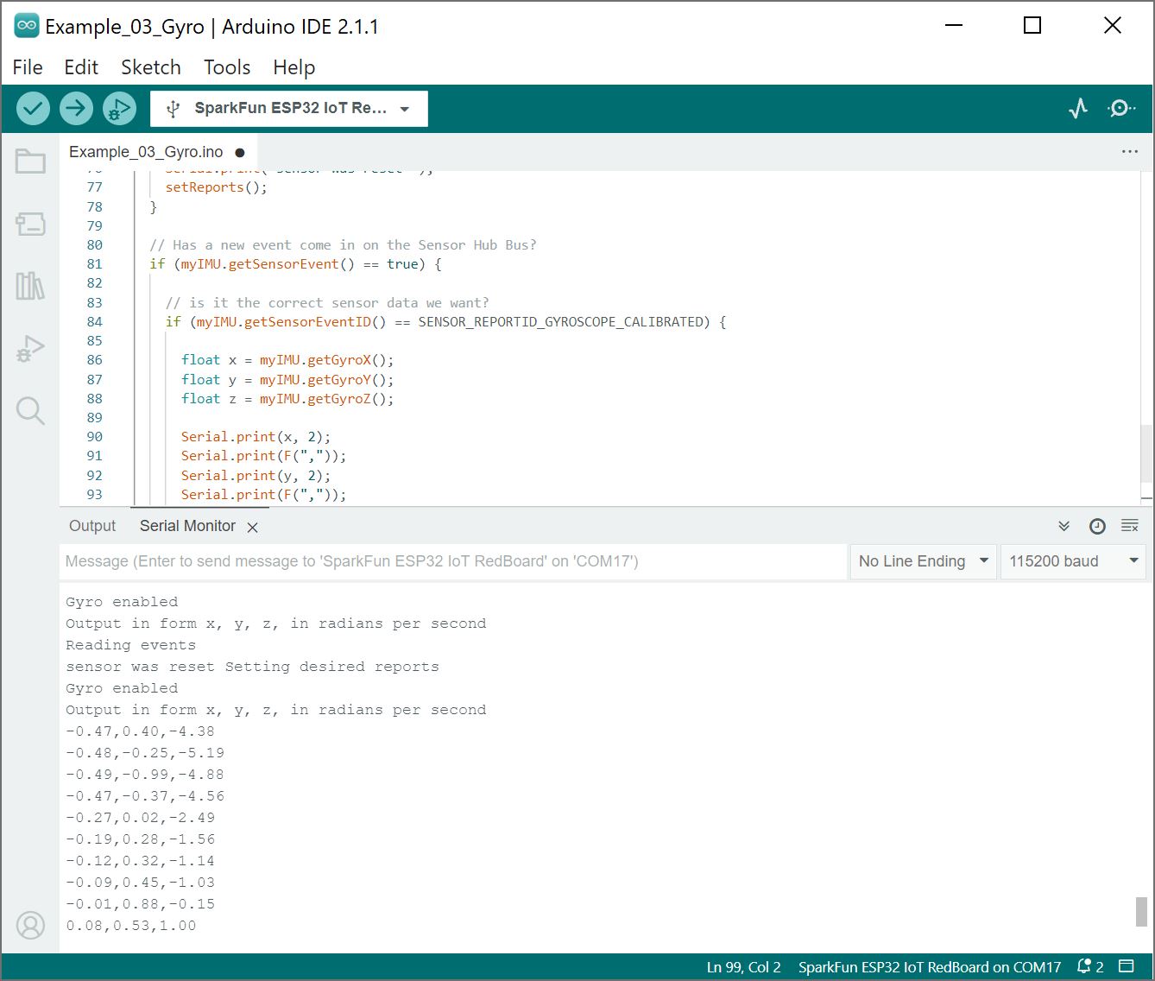
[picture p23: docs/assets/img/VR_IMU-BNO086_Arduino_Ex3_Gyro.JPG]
Output Example 3 - Gyro
     <td style="text-align: center; vertical-align: middle;"></td>
    </tr>
  </table>
</div>

Also, check out the values in a graph by opening the Serial Plotter to the same baud rate to see the readings from each gyroscope channel plotted against each other. Rotate the IMU and see how the values respond, I got the following output just letting the IMU swing on its cable.

<div style="text-align: center;">
  <table>
    <tr style="vertical-align:middle;">
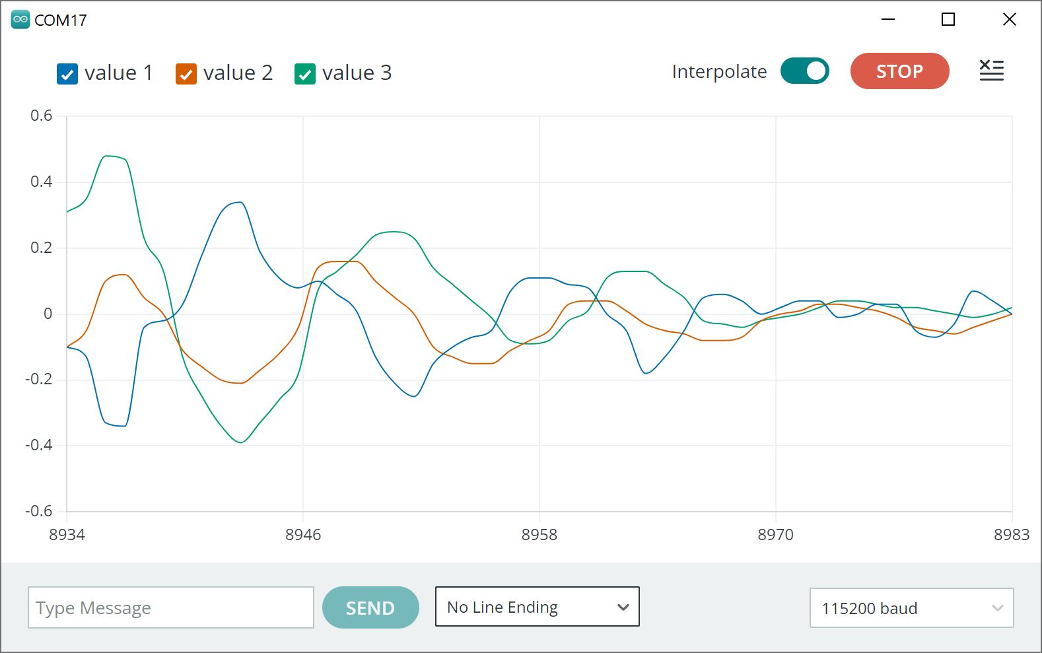
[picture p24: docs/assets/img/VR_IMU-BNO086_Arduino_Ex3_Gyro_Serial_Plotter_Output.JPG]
Output Example 3 - Gyro through Serial Plotter
     <td style="text-align: center; vertical-align: middle;"></td>
    </tr>
  </table>
</div>

!!!note
    The range for the Arduino Serial Plotter along x-axis is a bit limited in Arduino IDE v2+ as opposed to previous versions like Arduino v1.8.19. There is a [feature request relating to the Arduino Serial Plotter in the GitHub repo for the Arduino IDE](https://github.com/arduino/arduino-ide/issues/803). If you would like a bigger range, try opening the Arduino Serial Plotter in an older Arduino IDE like Arduino v1.8.19. Just make sure to adjust the baud rate to 115200.

    <div style="text-align: center;">
      <table>
        <tr style="vertical-align:middle;">
         <td style="text-align: center; vertical-align: middle;"><a href="../assets/img/VR_IMU-BNO086_Arduino_Ex3_Gyro_Serial_Plotter_Output_Older_Arduino_IDE_v1p8p19.JPG">Output Example 3 - Gyro through Serial Plotter using old Arduino IDE v1.8.3</a></td>
        </tr>
      </table>
    </div>

### Example 4 - Magnetometer

The following example will get us reading the component vectors for the magnetic field. Open the example by navigating to **File** > **Examples** > **SparkFun BNO08X Cortex Based IMU** > **Example_04_Magnetometer**.

Select your board in the Tools menu (in our case **SparkFun ESP32 IoT RedBoard**) and the correct Port it enumerated on and click "Upload". After uploading the code, open the [Serial Monitor](https://learn.sparkfun.com/tutorials/terminal-basics) or terminal emulator of your choice with the baud rate set to **115200**.

You should see the magnetometer values for x, y, and z in &micro;Tesla and the accuracy. Try moving the magnetometer around aligning the sensor with the North Pole. You can also try placing a weak magnet near the sensor to see the values increase. In this case, I placed a weak magnet which increased the magnitude of the field along the z-axis.

<div style="text-align: center;">
  <table>
    <tr style="vertical-align:middle;">
     <td style="text-align: center; vertical-align: middle;"><a href="../assets/img/VR_IMU-BNO086_Arduino_Ex4_Magnetometer.JPG">Output Example 4 - Magnetometer</a></td>
    </tr>
  </table>
</div>

<div style="text-align: center;">
  <i>Having a hard time seeing output? Click on the image for a closer look.</i>
</div>

!!!warning
    Note that you will want to be careful about placing the sensor too close to a magnet (especially a strong magnet) as this can potentially damage the sensor.

### Example 5 - Step Counter

The BNO080 has some really neat built-in features due to its built in Cortex. One of these is a built in step counter. Open the example by navigating to **File** > **Examples** > **SparkFun BNO08X Cortex Based IMU** > **Example_05_StepCounter**.

Select your board in the Tools menu (in our case **SparkFun ESP32 IoT RedBoard**) and the correct Port it enumerated on and click "Upload". After uploading the code, open the [Serial Monitor](https://learn.sparkfun.com/tutorials/terminal-basics) or terminal emulator of your choice with the baud rate set to **115200**.

Try holding the sensor or attaching to your body while connect to a laptop and walk around. You should see a value close to the number of steps that you have taken. In this case, I just walked away from my table and back.

<div style="text-align: center;">
  <table>
    <tr style="vertical-align:middle;">
     <td style="text-align: center; vertical-align: middle;"><a href="../assets/img/VR_IMU-BNO086_Arduino_Ex5_StepCounter.JPG">Output Example 5 - Step Counter</a></td>
    </tr>
  </table>
</div>

<div style="text-align: center;">
  <i>Having a hard time seeing output? Click on the image for a closer look.</i>
</div>

### Example 6 - Stability Classifier

This example sketch allows us to use the built-in stability classifier to figure out how stable the IMU is. Open the example by navigating to **File** > **Examples** > **SparkFun BNO08X Cortex Based IMU** > **Example_06-StabilityClassifier**.

Select your board in the Tools menu (in our case **SparkFun ESP32 IoT RedBoard**) and the correct Port it enumerated on and click "Upload". After uploading the code, open the [Serial Monitor](https://learn.sparkfun.com/tutorials/terminal-basics) or terminal emulator of your choice with the baud rate set to **115200**.

Give the BNO086 a second to measure and process the sensor values. The sensor will provide an output classifying an activity. In the output below, the sensor determined that the board was resting on a table... which it was! Amazing!

<div style="text-align: center;">
  <table>
    <tr style="vertical-align:middle;">
     <td style="text-align: center; vertical-align: middle;"><a href="../assets/img/VR_IMU-BNO086_Arduino_Ex6_StabilityClassifier.JPG">Output Example 6 - Stability Classifier</a></td>
    </tr>
  </table>
</div>

<div style="text-align: center;">
  <i>Having a hard time seeing output? Click on the image for a closer look.</i>
</div>

As stated in the datasheet, the sensor uses both the accelerometer and gyroscope to determine the sensor's stability: on table, stationary, stable, motion. If the sensor does not know what is happening, the output will tell you that it was an "unknown classification."

### Example 7 - Activity Classifier

The activity classifier is somewhat similar to the stability classifier in that it uses the on-board Cortex to determine what activity the IMU is doing. Open the example by navigating to **File** > **Examples** > **SparkFun BNO08X Cortex Based IMU** > **Example_07_ActivityClassifier**.

Select your board in the Tools menu (in our case **SparkFun ESP32 IoT RedBoard**) and the correct Port it enumerated on and click "Upload". After uploading the code, open the [Serial Monitor](https://learn.sparkfun.com/tutorials/terminal-basics) or terminal emulator of your choice with the baud rate set to **115200**.

Give the BNO086 a second to measure and process the sensor values. The sensor will provide an output classifying an activity and how confident it was. In the output below, the sensor determined that I was on the move and walking around my desk, which I was!

<div style="text-align: center;">
  <table>
    <tr style="vertical-align:middle;">
     <td style="text-align: center; vertical-align: middle;"><a href="../assets/img/VR_IMU-BNO086_Arduino_Ex7_ActivityClassifier.JPG">Output Example 7 - Activity Classifier</a></td>
    </tr>
  </table>
</div>

<div style="text-align: center;">
  <i>Having a hard time seeing output? Click on the image for a closer look.</i>
</div>

The BNO086 can determine the following activities:

  * In vehicle
  * On bicycle
  * On foot
  * Still
  * Tilting
  * Walking
  * Running
  * On stairs

If the sensor is not able to determine what is happening, the output will tell you that it was an "Unknown."

### Example 8 - Advanced Configuration

This example shows us how to configure the sensor on different addresses and I<sup>2</sup>C buses. Make sure to close the ADR jumper by adding a solder blob. You will also need to manually connect the I<sup>2</sup>C data and clock pins to the alternative port. For a quick test, you could use the [Qwiic cable with breadboard jumpers](https://www.sparkfun.com/products/14425) to connect the breakout board to the RedBoard IoT - ESP32's header sockets. Of course, soldering wire directly to the PTH is better for a more secure connection.

<div style="text-align: center;">
    <table>
        <tr>
            <th style="text-align: center; border: solid 1px #cccccc;">RedBoard IoT - ESP32
            </th>
            <th style="text-align: center; border: solid 1px #cccccc;">VR IMU Breakout - BNO086
            </th>
        </tr>
        <tr>
            <td style="text-align: center; border: solid 1px #cccccc;" bgcolor="#f2dede"><font color="#000000">3.3V</font>
            </td>
            <td style="text-align: center; border: solid 1px #cccccc;" bgcolor="#f2dede"><font color="#000000">3.3V</font>
            </td>
        </tr>
        <tr>
            <td style="text-align: center; border: solid 1px #cccccc;" bgcolor="#DDDDDD"><font color="#000000">GND</font>
            </td>
            <td style="text-align: center; border: solid 1px #cccccc;" bgcolor="#DDDDDD"><font color="#000000">GND</font>
            </td>
        </tr>
        <tr>
            <td style="text-align: center; border: solid 1px #cccccc;" bgcolor="#fff3cd"><font color="#000000">SCL1 (D17)</font>
            </td>
            <td style="text-align: center; border: solid 1px #cccccc;" bgcolor="#fff3cd"><font color="#000000">SCL</font>
            </td>
        </tr>
        <tr>
            <td style="text-align: center; border: solid 1px #cccccc;" bgcolor="#cce5ff"><font color="#000000">SDA1 (D25)</font>
            </td>
            <td style="text-align: center; border: solid 1px #cccccc;" bgcolor="#cce5ff"><font color="#000000">SDA</font>
            </td>
        </tr>    
        <tr>
            <td style="text-align: center; border: solid 1px #cccccc;" bgcolor="#cce5ff"><font color="#000000">A4</font>
            </td>
            <td style="text-align: center; border: solid 1px #cccccc;" bgcolor="#cce5ff"><font color="#000000">INT</font>
            </td>
        </tr>
        <tr>
            <td style="text-align: center; border: solid 1px #cccccc;" bgcolor="#d4edda"><font color="#000000">A5</font>
            </td>
            <td style="text-align: center; border: solid 1px #cccccc;" bgcolor="#d4edda"><font color="#000000">RST</font>
            </td>
        </tr>    
    </table>
</div>

<div style="text-align: center;">
  <table>
    <tr style="vertical-align:middle;">
     <td style="text-align: center; vertical-align: middle;"><a href="../assets/img/SparkFun_RedBoard_IoT_ESP32_BNO086_ALT_I2C_Hookup_bb.jpg">Hookup with ESP32 between the BNO086 using the Alternative I2C Port, Interrupt, and Reset Pins</a></td>
    </tr>
  </table>
</div>

Open the example by navigating to **File** > **Examples** > **SparkFun BNO08X Cortex Based IMU** > **Example_08_AdvancedConfig**.

Select your board in the Tools menu (in our case **SparkFun ESP32 IoT RedBoard**) and the correct Port it enumerated on and click "Upload". After uploading the code, open the [Serial Monitor](https://learn.sparkfun.com/tutorials/terminal-basics) or terminal emulator of your choice with the baud rate set to **115200**.

<div style="text-align: center;">
  <table>
    <tr style="vertical-align:middle;">
     <td style="text-align: center; vertical-align: middle;"><a href="../assets/img/VR_IMU-BNO086_Arduino_Ex8_AdvancedConfiguration.JPG">Output Example 8 - Advanced Configuration with Rotation Vector</a></td>
    </tr>
  </table>
</div>

<div style="text-align: center;">
  <i>Having a hard time seeing output? Click on the image for a closer look.</i>
</div>

### Example 9 - Linear Accelerometer

The following example is similar to example 2, however we are reading the linear acceleration. What does this mean? Well, it's acceleration with gravity (~9.8m/s<sup>2</sup>) removed from the data! Open the example by navigating to **File** > **Examples** > **SparkFun BNO08X Cortex Based IMU** > **Example_09_LinearAccelerometer**.

Select your board in the Tools menu (in our case **SparkFun ESP32 IoT RedBoard**) and the correct Port it enumerated on and click "Upload". After uploading the code, open the [Serial Monitor](https://learn.sparkfun.com/tutorials/terminal-basics) or terminal emulator of your choice with the baud rate set to **115200**.

<div style="text-align: center;">
  <table>
    <tr style="vertical-align:middle;">
     <td style="text-align: center; vertical-align: middle;"><a href="../assets/img/VR_IMU-BNO086_Arduino_Ex9_LinearAccelerometer.JPG">Output Example 9 - Linear Accelerometer</a></td>
    </tr>
  </table>
</div>

<div style="text-align: center;">
  <i>Having a hard time seeing output? Click on the image for a closer look.</i>
</div>

### Example 10 - Timestamp

This example is pretty much like example 1. The difference is that we add a timestamp for each rotation vector. Open the example by navigating to **File** > **Examples** > **SparkFun BNO08X Cortex Based IMU** > **Example_10_TimeStamp**.

Select your board in the Tools menu (in our case **SparkFun ESP32 IoT RedBoard**) and the correct Port it enumerated on and click "Upload". After uploading the code, open the [Serial Monitor](https://learn.sparkfun.com/tutorials/terminal-basics) or terminal emulator of your choice with the baud rate set to **115200**.

<div style="text-align: center;">
  <table>
    <tr style="vertical-align:middle;">
     <td style="text-align: center; vertical-align: middle;"><a href="../assets/img/VR_IMU-BNO086_Arduino_Ex10_Timestamp_and_Rotation_Vector.JPG">Output Example 10 - Timestamp</a></td>
    </tr>
  </table>
</div>

<div style="text-align: center;">
  <i>Having a hard time seeing output? Click on the image for a closer look.</i>
</div>

### Example 11 - Raw Readings

This example shows how to output the raw acceleration, gyroscope, and magnetometer values. Open the example by navigating to **File** > **Examples** > **SparkFun BNO08X Cortex Based IMU** > **Example_11_RawReadings**.

Select your board in the Tools menu (in our case **SparkFun ESP32 IoT RedBoard**) and the correct Port it enumerated on and click "Upload". After uploading the code, open the [Serial Monitor](https://learn.sparkfun.com/tutorials/terminal-basics) or terminal emulator of your choice with the baud rate set to **115200**.

<div style="text-align: center;">
  <table>
    <tr style="vertical-align:middle;">
     <td style="text-align: center; vertical-align: middle;"><a href="../assets/img/VR_IMU-BNO086_Arduino_Ex11_Raw_Readings_v2.png">Output Example 11 - Raw Readings</a></td>
    </tr>
  </table>
</div>

<div style="text-align: center;">
  <i>Having a hard time seeing output? Click on the image for a closer look.</i>
</div>

### Example 12 - Gyro Integrated Rotation Vector

This example shows how to use the gyro integrated rotation vector. Open the example by navigating to **File** > **Examples** > **SparkFun BNO08X Cortex Based IMU** > **Example_12-GyroIntegratedRotationVector**.

Select your board in the Tools menu (in our case **SparkFun ESP32 IoT RedBoard**) and the correct Port it enumerated on and click "Upload". After uploading the code, open the [Serial Monitor](https://learn.sparkfun.com/tutorials/terminal-basics) or terminal emulator of your choice with the baud rate set to **115200**.

<div style="text-align: center;">
  <table>
    <tr style="vertical-align:middle;">
     <td style="text-align: center; vertical-align: middle;"><a href="../assets/img/VR_IMU-BNO086_Arduino_Ex12_Gyro_Integrated_Rotation_Vector.JPG">Output Example 12 - Gyro Integrated Rotation Vector</a></td>
    </tr>
  </table>
</div>

<div style="text-align: center;">
  <i>Having a hard time seeing output? Click on the image for a closer look.</i>
</div>

### Example 13 - Euler Angles

Open the example by navigating to **File** > **Examples** > **SparkFun BNO08X Cortex Based IMU** > **Example_13_EulerAngles**.

Select your board in the Tools menu (in our case **SparkFun ESP32 IoT RedBoard**) and the correct Port it enumerated on and click "Upload". After uploading the code, open the [Serial Monitor](https://learn.sparkfun.com/tutorials/terminal-basics) or terminal emulator of your choice with the baud rate set to **115200**.

<div style="text-align: center;">
 <table>
   <tr style="vertical-align:middle;">
    <td style="text-align: center; vertical-align: middle;"><a href="../assets/img/VR_IMU-BNO086_Arduino_Ex13_Euler_Angles_Pitch_Roll_Yaw.JPG">Output Example 13 - Euler Angles</a></td>
   </tr>
 </table>
</div>

<div style="text-align: center;">
  <i>Having a hard time seeing output? Click on the image for a closer look.</i>
</div>

### Example 14 - Tare

Open the example by navigating to **File** > **Examples** > **SparkFun BNO08X Cortex Based IMU** > **Example_14_Tare**.

Select your board in the Tools menu (in our case **SparkFun ESP32 IoT RedBoard**) and the correct Port it enumerated on and click "Upload". After uploading the code, open the [Serial Monitor](https://learn.sparkfun.com/tutorials/terminal-basics) or terminal emulator of your choice with the baud rate set to **115200**.

<div style="text-align: center;">
 <table>
   <tr style="vertical-align:middle;">
    <td style="text-align: center; vertical-align: middle;"><a href="../assets/img/VR_IMU-BNO086_Arduino_Ex14_Tare.JPG">Output Example 14 - Tare</a></td>
   </tr>
 </table>
</div>

<div style="text-align: center;">
  <i>Having a hard time seeing output? Click on the image for a closer look.</i>
</div>

### Example 15 - Gravity

Open the example by navigating to **File** > **Examples** > **SparkFun BNO08X Cortex Based IMU** > **Example_15_Gravity**.

Select your board in the Tools menu (in our case **SparkFun ESP32 IoT RedBoard**) and the correct Port it enumerated on and click "Upload". After uploading the code, open the [Serial Monitor](https://learn.sparkfun.com/tutorials/terminal-basics) or terminal emulator of your choice with the baud rate set to **115200**.

<div style="text-align: center;">
 <table>
   <tr style="vertical-align:middle;">
    <td style="text-align: center; vertical-align: middle;"><a href="../assets/img/VR_IMU-BNO086_Arduino_Ex15_Gravity.JPG">Output Example 15 - Gravity</a></td>
   </tr>
 </table>
</div>

<div style="text-align: center;">
  <i>Having a hard time seeing output? Click on the image for a closer look.</i>
</div>

### Example 16 - Uncalibrated Gyro

Open the example by navigating to **File** > **Examples** > **SparkFun BNO08X Cortex Based IMU** > **Example_16_UncalibratedGyro**.

Select your board in the Tools menu (in our case **SparkFun ESP32 IoT RedBoard**) and the correct Port it enumerated on and click "Upload". After uploading the code, open the [Serial Monitor](https://learn.sparkfun.com/tutorials/terminal-basics) or terminal emulator of your choice with the baud rate set to **115200**.

<div style="text-align: center;">
 <table>
   <tr style="vertical-align:middle;">
    <td style="text-align: center; vertical-align: middle;"><a href="../assets/img/VR_IMU-BNO086_Arduino_Ex16_Uncalibrated_Gyro.JPG">Output Example 16 - Uncalibrated Gyro</a></td>
   </tr>
 </table>
</div>

<div style="text-align: center;">
  <i>Having a hard time seeing output? Click on the image for a closer look.</i>
</div>

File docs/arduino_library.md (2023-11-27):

!!! arduino

    ### Arduino IDE

    This example assumes you are using the latest version of the Arduino IDE on your desktop. If this is your first time using Arduino IDE and an library, please review the following tutorials.

    - [Installing the Arduino IDE](https://learn.sparkfun.com/tutorials/installing-arduino-ide)
    - [Installing an Arduino Library](https://learn.sparkfun.com/tutorials/installing-an-arduino-library)

    ### Board Definitions

    For the scope of this tutorial, we will be using the [SparkFun IoT RedBoard - ESP32 Development Board](https://learn.sparkfun.com/tutorials/iot-redboard-esp32-development-board-hookup-guide). This Library also works with the SAMD51. For users that decide to use the SAMD51, make sure to use the [Arduino SAMD Core and SparkFun SAMD boards](https://learn.sparkfun.com/tutorials/samd51-thing-plus-hookup-guide/setting-up-the-arduino-ide) before selecting the SAMD51 board definition.

    If you have not installed a board definition before, please review the following tutorial as well.

    - [Installing Board Definitions in the Arduino IDE](https://learn.sparkfun.com/tutorials/installing-board-definitions-in-the-arduino-ide)

    ### USB-to-Serial Drivers

    If you've never connected an CH340 device to your computer before, you may need to install drivers for the USB-to-serial converter. Check out our section on "[How to Install CH340 Drivers](https://learn.sparkfun.com/tutorials/sparkfun-serial-basic-ch340c-hookup-guide#drivers-if-you-need-them)" for help with the installation.

The SparkFun VR IMU BNO08X Arduino Library provides a quick way to interact with the interfaces on the SparkFun VR IMU Breakout - BNO086 (Qwiic). Install the library through the Arduino Library Manager tool by searching for "**SparkFun BNO08X**". Users who prefer to manually install the library can get it from the [GitHub Repository](https://github.com/sparkfun/SparkFun_BNO08x_Arduino_Library) or download the .ZIP by clicking the button below:

<div style="text-align: center"><a href="https://github.com/sparkfun/SparkFun_BNO08x_Arduino_Library/archive/refs/heads/main.zip" class="md-button">SparkFun VR IMU BNO08X Arduino Library (ZIP)</a></div>

!!!note
    This library is different from the original [BNO080 Arduino Library](https://github.com/sparkfun/SparkFun_BNO080_Arduino_Library). Most of the examples from the old Arduino Library were ported to the BNO08X Arduino Library. We recommend using this library for the BNO08X as it processes the data better.

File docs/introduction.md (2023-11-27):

!!!info
    This tutorial is an update to the BNO080. If you are looking for the original tutorial for the BNO080, make sure to head to the [Qwiic VR IMU (BNO080) Hookup Guide](https://learn.sparkfun.com/tutorials/qwiic-vr-imu-bno080-hookup-guide). Note that the BNO080 is EOL. Additionally, this tutorial uses a different Arduino Library.

CEVA's [BNO086](https://www.sparkfun.com/products/22857), a combination triple-axis accelerometer/gyro/magnetometer System in Package (SiP), packaged with a 32-bit ARM&copy; Cortex&trade; M0+. The BNO086 Inertial Measurement Unit (IMU) produces accurate rotation vector headings, excellently suited for VR and other heading applications, with a static rotation error of two degrees or less. The VR IMU is exactly what we’ve been waiting for: all the sensor data is combined and drift-corrected into meaningful, accurate IMU information. It’s perfect for any project that needs to sense orientation or motion. We've taken this IMU and stuck it on a Qwiic enabled breakout board, in order to make interfacing with the tiny, QFN package a bit easier to connect.

<center>
<div class="grid cards" style="width:500px;" markdown>

-   <a href="https://www.sparkfun.com/products/22857">
      <figure markdown>
        SparkFun VR IMU Breakout - BNO086 (Qwiic)
      </figure>
    </a>

    ---

    <a href="https://www.sparkfun.com/products/22857">
      <b>SparkFun VR IMU Breakout - BNO086 (Qwiic)</b>
      <br />
      SEN-22857
      <br />
      <center>[Purchase from SparkFun :fontawesome-solid-cart-plus:](https://www.sparkfun.com/products/22857){ .md-button .md-button--primary }</center>
    </a>

</div>
</center>

<div style="text-align: center;">
  <iframe width="560" height="315" src="https://www.youtube.com/embed/30WDbm8smP8" title="YouTube video player" frameborder="0" allow="accelerometer; autoplay; clipboard-write; encrypted-media; gyroscope; picture-in-picture; web-share" allowfullscreen></iframe>
</div>

In this hookup guide, we'll connect our sensor up to our microcontroller of choice and separately read the rotation vectors (which is what we will mainly want), acceleration vectors, gyro values, and magnetometer vectors. We'll check out how to implement the step counter on the BNO086 in order to use it as a pedometer. We'll also read Q values from the sensor. Knowing what activity you're performing is important so we'll learn how to classify what activity the IMU is performing (i.e. Sitting still, moving, biking, walking, running, etc...) and how confident the IMU is that each activity is being performed. Printing out raw packets will also be examined for debugging purposes. Finally, we'll examine how to configure the sensor on different I<sup>2</sup>C ports and addresses. A bonus example is provided in Processing to show us how to use quaternion data to orient a cube.

### Required Materials

To follow along with this tutorial, you will need the following materials. You may not need everything though depending on what you have. Add it to your cart, read through the guide, and adjust the cart as necessary.

* 1x [SparkFun IoT RedBoard - ESP32 Development Board [WRL-19177]](https://www.sparkfun.com/products/19177)
* 1x USB-C cable
    * Our [USB 2.0 A to C Cable [CAB-15092]](https://www.sparkfun.com/products/15092) will do nicely
    * Our [USB 3.1 A to C Cable [CAB-14743]](https://www.sparkfun.com/products/14743) is a good choice too
* 1x [SparkFun VR IMU Breakout - BNO086 (Qwiic) [SEN-22857]](https://www.sparkfun.com/products/22857)
* 1x Qwiic Cable
    * [Flexible Qwiic Cable - 100mm [PRT-17259]](https://www.sparkfun.com/products/17259)
    * [Flexible Qwiic Cable - 500mm [PRT-17257]](https://www.sparkfun.com/products/17257)
* 2x IC Hooks (_optional for advanced configuration_)
    * The pack of 5x [IC Hook with Pigtail [CAB-09741]](https://www.sparkfun.com/products/9741) for a temporary connection

<div class="grid cards col-4" markdown>

-   <a href="https://www.sparkfun.com/products/19177">
      <figure markdown>
        SparkFun IoT RedBoard - ESP32 Development Board
      </figure>
    </a>

    ---

    <a href="https://www.sparkfun.com/products/19177">
      <b>SparkFun IoT RedBoard - ESP32 Development Board</b>
      <br />
      WRL-19177
    </a>
<!-- ----------WHITE SPACE BETWEEN PRODUCTS---------- -->
-   <a href="https://www.sparkfun.com/products/15092">
      <figure markdown>
        Reversible USB A to C Cable - 0.8m
      </figure>
    </a>

    ---

    <a href="https://www.sparkfun.com/products/15092">
      <b>Reversible USB A to C Cable - 0.8m</b>
      <br />
      CAB-15092
    </a>
<!-- ----------WHITE SPACE BETWEEN PRODUCTS---------- -->
-   <a href="https://www.sparkfun.com/products/22857">
      <figure markdown>
        SparkFun VR IMU Breakout - BNO086 (Qwiic)
      </figure>
    </a>

    ---

    <a href="https://www.sparkfun.com/products/22857">
      <b>SparkFun VR IMU Breakout - BNO086 (Qwiic)</b>
      <br />
      SEN-22857
    </a>
<!-- ----------WHITE SPACE BETWEEN PRODUCTS---------- -->
-   <a href="https://www.sparkfun.com/products/17259">
      <figure markdown>
        Flexible Qwiic Cable - 100mm
      </figure>
    </a>

    ---

    <a href="https://www.sparkfun.com/products/17259">
      <b>Flexible Qwiic Cable - 100mm</b>
      <br>
      PRT-17259
    </a>
<!-- ----------WHITE SPACE BETWEEN PRODUCTS---------- -->
-   <a href="https://www.sparkfun.com/products/9741">
      <figure markdown>
       IC Hook with Pigtail
      </figure>
    </a>

    ---

    <a href="https://www.sparkfun.com/products/9741">
      <b>IC Hook with Pigtail</b>
      <br>
      CAB-09741
    </a>
<!-- ----------WHITE SPACE BETWEEN PRODUCTS---------- -->

</div>

!!! note
    As of Arduino Library v1.0.3, the BNO086 has also been tested to work with a SAMD51 (i.e. [SparkFun Thing Plus - SAMD51](https://www.sparkfun.com/products/14713)) as well!

### Tools

For a secure connection when connecting to the reset and interrupt pins, you will need to solder two wires between your microcontroller and the breakout board. This requires some assembly and soldering. You may already have a few of these items but if not, the tools and hardware below help with that assembly.

* [Hook-Up Wire - Assortment (Stranded, 22 AWG) [PRT-11375]](https://www.sparkfun.com/products/11375)
* [Wire Stripper - 20-30 AWG Solid (22-32 AWG Stranded) [TOL-22263]](https://www.sparkfun.com/products/22263)
* [Soldering Iron [TOL-14456]](https://www.sparkfun.com/products/14456)
* [Solder Lead Free - 15-gram Tube [TOL-9163]](https://www.sparkfun.com/products/9163)

<div class="grid cards col-4" markdown>

-   <a href="https://www.sparkfun.com/products/11375">
      <figure markdown>
        Hook-Up Wire - Assortment (Stranded, 22 AWG)
      </figure>
    </a>

    ---

    <a href="https://www.sparkfun.com/products/11375">
      <b>Hook-Up Wire - Assortment (Stranded, 22 AWG)</b>
      <br />
      PRT-11375
    </a>
<!-- ----------WHITE SPACE BETWEEN PRODUCTS---------- -->
-   <a href="https://www.sparkfun.com/products/22263">
      <figure markdown>
        Wire Stripper - 20-30 AWG Solid (22-32 AWG Stranded)
      </figure>
    </a>

    ---

    <a href="https://www.sparkfun.com/products/22263">
      <b>Wire Stripper - 20-30 AWG Solid (22-32 AWG Stranded)</b>
      <br />
      TOL-22263
    </a>
<!-- ----------WHITE SPACE BETWEEN PRODUCTS---------- -->
-   <a href="https://www.sparkfun.com/products/14456">
      <figure markdown>
        Soldering Iron - 60W (Adjustable Temperature)
      </figure>
    </a>

    ---

    <a href="https://www.sparkfun.com/products/14456">
      <b>Soldering Iron - 60W (Adjustable Temperature)</b>
      <br />
      TOL-14456
    </a>
<!-- ----------WHITE SPACE BETWEEN PRODUCTS---------- -->
-   <a href="https://www.sparkfun.com/products/9163">
      <figure markdown>
        Solder Lead Free - 15-gram Tube
      </figure>
    </a>

    ---

    <a href="https://www.sparkfun.com/products/9163">
      <b>Solder Lead Free - 15-gram Tube</b>
      <br>
      TOL-09163
    </a>
<!-- ----------WHITE SPACE BETWEEN PRODUCTS---------- -->
</div>

### Suggested Reading

If you aren't familiar with the Qwiic Connection System, we recommend reading [here for an overview](https://www.sparkfun.com/qwiic).

<div style="text-align: center">
  <table style="border-style:none">
    <tr>
     <td style="text-align: center; vertical-align: middle;">
     <div style="text-align: center"><a href="https://www.sparkfun.com/qwiic">Qwiic Connection System Click to learn more about the Qwiic Connection System!</a>
     </div>
    </td>
    </tr>
    <tr>
      <td style="text-align: center; vertical-align: middle;"><div style="text-align: center"><i><a href="https://www.sparkfun.com/qwiic">Qwiic Connection System</a></i></div></td>
    </tr>
  </table>
</div>

If you aren’t familiar with the following concepts, we also recommend checking out a few of these tutorials before continuing.

<div class="grid cards col-4" markdown>

-   <a href="https://learn.sparkfun.com/tutorials/gyroscope">
      <figure markdown>
        Gyroscope
      </figure>
    </a>

    ---

    <a href="https://learn.sparkfun.com/tutorials/gyroscope">
      <b>Gyroscope</b>
    </a>
<!-- ----------WHITE SPACE BETWEEN GRID CARDS---------- -->
-   <a href="https://learn.sparkfun.com/tutorials/accelerometer-basics">
      <figure markdown>
        Accelerometer Basics
      </figure>
    </a>

    ---

    <a href="https://learn.sparkfun.com/tutorials/accelerometer-basics">
      <b>Accelerometer Basics</b>
    </a>
<!-- ----------WHITE SPACE BETWEEN GRID CARDS---------- -->
-   <a href="https://learn.sparkfun.com/tutorials/serial-communication">
      <figure markdown>
        Serial Communication
      </figure>
    </a>

    ---

    <a href="https://learn.sparkfun.com/tutorials/serial-communication">
      <b>Serial Communication</b>
    </a>
<!-- ----------WHITE SPACE BETWEEN GRID CARDS---------- -->
-   <a href="https://learn.sparkfun.com/tutorials/i2c">
      <figure markdown>
        I2C
      </figure>
    </a>

    ---

    <a href="https://learn.sparkfun.com/tutorials/i2c">
      <b>I2C</b>
    </a>
<!-- ----------WHITE SPACE BETWEEN GRID CARDS---------- -->
-   <a href="https://learn.sparkfun.com/tutorials/terminal-basics">
      <figure markdown>
        Serial Terminal Basics
      </figure>
    </a>

    ---

    <a href="https://learn.sparkfun.com/tutorials/terminal-basics">
      <b>Serial Terminal Basics</b>
    </a>
<!-- ----------WHITE SPACE BETWEEN GRID CARDS---------- -->
-   <a href="https://learn.sparkfun.com/tutorials/installing-an-arduino-library">
      <figure markdown>
        Installing an Arduino Library
      </figure>
    </a>

    ---

    <a href="https://learn.sparkfun.com/tutorials/installing-an-arduino-library">
      <b>Installing an Arduino Library</b>
    </a>
<!-- ----------WHITE SPACE BETWEEN GRID CARDS---------- -->
-   <a href="https://learn.sparkfun.com/tutorials/connecting-arduino-to-processing">
      <figure markdown>
        Connecting Arduino to Processing
      </figure>
    </a>

    ---

    <a href="https://learn.sparkfun.com/tutorials/connecting-arduino-to-processing">
      <b>Connecting Arduino to Processing</b>
    </a>
<!-- ----------WHITE SPACE BETWEEN GRID CARDS---------- -->
-   <a href="https://learn.sparkfun.com/tutorials/how-to-solder-through-hole-soldering/all">
      <figure markdown>
        How to Solder: Through Hole Soldering
      </figure>
    </a>

    ---

    <a href="https://learn.sparkfun.com/tutorials/how-to-solder-through-hole-soldering/all">
      <b>How to Solder: Through Hole Soldering</b>
    </a>
<!-- ----------WHITE SPACE BETWEEN GRID CARDS---------- -->
</div>

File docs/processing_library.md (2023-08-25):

!!!note
    Processing is a software that enables visual representation of data, among other things. If you've never dealt with Processing before, we recommend you also check out the [Arduino to Processing](https://learn.sparkfun.com/tutorials/connecting-arduino-to-processing) tutorial. Follow the below button to download and install Processing.

    <div style="text-align: center"><a href="https://processing.org/download/" target="download_processing_ide" class="md-button">Download Processing IDE</a></div>

!!!note
    At the time of writing this tutorial, we used Arduino IDE v2.1.1 and SparkFun VR IMU BNO08X Arduino Library v1.0. We also used Processing IDE v3.5.3 and toxiclibs Processing Library v0021. We also tested the demo and verified that it works with Processing v4.3.

### Manually Install the toxiclibs Processing Library v0021

!!!note
    We were unable to search for the **toxiclibs** in Processing's Contribution Manager in order to automatically install the library. Instead, we manually installed the Processing Library.

Before running the "Serial Cube Rotate" processing demo, you will also need to manually install the [ToxicLibs Processing Library v0021](https://github.com/postspectacular/toxiclibs/releases/tag/0021) by "Karsten Schmidt". This is a library used for computational design. Head to the v0021 release and download "**toxiclibs-complete-0021.zip**".

<div style="text-align: center"><a href="https://github.com/postspectacular/toxiclibs/releases/tag/0021" target="download_toxiclibs" class="md-button">Download Toxiclibs Processing Library v0021</a></div>

Similar to an Arduino Library, there is a [certain file structure that Processing requires](https://github.com/processing/processing/wiki/How-to-Install-a-Contributed-Library#manual-install) to properly install a Processing Library. After downloading, unzip the files and open the **toxiclibs-complete-0021** folder. For Windows, copy all the contents of the folder (except for _MACOSX) into the Processing's libraries folder (in this case, **C:\Users\...\Documents\Processing\libraries**). Again, we'll assume that you are using Processing IDE v3.5.3.

<div style="text-align: center;">
  <table>
    <tr style="vertical-align:middle;">
     <td style="text-align: center; vertical-align: middle;"><a href="../assets/img/Manual_Install_Processing_Library_toxiclibs.JPG">Manual Install of the toxiclibs Processing Library</a></td>
    </tr>
  </table>
</div>

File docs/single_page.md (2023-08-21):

---
hide:
  - navigation
  - toc
icon: fontawesome/solid/scroll
---

# Introduction
--8<-- "./docs/introduction.md"

# Hardware Overview
--8<-- "./docs/hardware_overview.md"

# Hardware Hookup
--8<-- "./docs/hardware_hookup.md"

# Installing the Arduino Library
--8<-- "./docs/arduino_library.md"

# Arduino Examples
--8<-- "./docs/arduino_examples.md"

# Installing the Processing Library
--8<-- "./docs/processing_library.md"

# Processing Example
--8<-- "./docs/processing_example.md"

# Troubleshooting
--8<-- "./docs/troubleshooting.md"

# Resources
--8<-- "./docs/resources.md"

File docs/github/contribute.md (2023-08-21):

# Contribute: Help Fix our Mistake!
Spot something wrong? Feel free to contribute our open-source design and documentation. 

## Improve our Documentation
All of this documentation can be modified by you! Please help us make it better.

* These pages are contained in the [`docs` folder of the SparkFun VR IMU Breakout - BNO086 (Qwiic) repository](https://github.com/sparkfun/SparkFun_VR_IMU_Breakout_BNO086_QWIIC/tree/main/docs).

### Submit a Correction
1. Fork this repo
2. Add your corrections or improvements to the markdown file
3. File a pull request with your changes, and enjoy making the ~~words~~ ~~worlds~~ world a better place.
    * Once received, the documentation specialist will automatically be notified.
    * We will review your suggested improvements to make sure they are correct and fit within our documentation standards.

## Improve our Hardware Design
All of our designs are open-source! Please help us make it better.

* Our board design files are contained in the [`Hardware` folder of the SparkFun VR IMU Breakout - BNO086 (Qwiic) repository](https://github.com/sparkfun/SparkFun_VR_IMU_Breakout_BNO086_QWIIC/tree/main/Hardware).

### Submit a Design Improvement
1. Fork this repo
2. Add your design improvements
3. File a pull request with your changes, and enjoy making the ~~words~~ ~~worlds~~ world a better place.
    * Once received, the engineer in charge of the original design will automatically be notified.
    * We will review your suggested improvements, if they are within our board design standards and meet our product design requirements, we will flag these changes for our next board revision. *(Please note, that even if your suggestion is accepted, these changes may not be immediate. We may have to cycle through our current product inventory first.)*

## Contributors
Let's provided some recognition to the contributors for this project!

GitHub Contributors Image
<br>


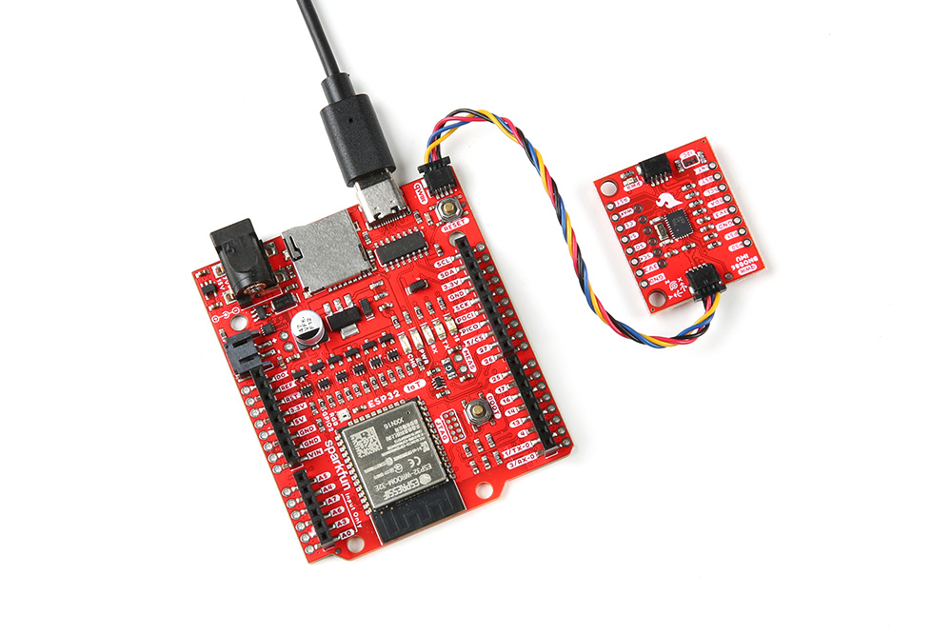
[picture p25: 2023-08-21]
docs/assets/img/22857-SEN_SparkFun_VR_IMU_Breakout-BNO086_Qwiic- 05.jpg

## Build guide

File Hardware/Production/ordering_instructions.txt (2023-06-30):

panel size, 138x169mm
PCB thickness, 1.6mm
number of layers, 2
soldermask color, Red
silkscreen color, White
oz copper, 1oz
finish, HASL lead free
stencils, top
pcs per panel, 24
min trace width, 0.1524mm / 0.0060in
min drill size, 0.3048mm / 0.0120in

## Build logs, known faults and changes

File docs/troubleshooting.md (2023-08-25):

### General Troubleshooting Help

!!! note
    <span class="glyphicon glyphicon-question-sign" aria-hidden="true"></span>
        <strong> Not working as expected and need help? </strong> <br /><br />

    If you need technical assistance and more information on a product that is not working as you expected, we recommend heading on over to the <a href="https://www.sparkfun.com/technical_assistance">SparkFun Technical Assistance</a> page for some initial troubleshooting. <br /><br />

    <div style="text-align: center"><a href="https://www.sparkfun.com/technical_assistance" target="sfe_technical_assistance" class="md-button">SparkFun Technical Assistance Page</a></div>

    If you don't find what you need there, the <a href="https://forum.sparkfun.com/">SparkFun Forums</a> are a great place to find and ask for help. If this is your first visit, you'll need to <a href="https://forum.sparkfun.com/ucp.php?mode=register">create a Forum Account</a> to search product forums and post questions.<br /><br />

    <div style="text-align: center"><a href="https://forum.sparkfun.com/ucp.php?mode=register" class="md-button">Create New Forum Account</a>&nbsp;&nbsp;&nbsp;<a href="https://forum.sparkfun.com/viewforum.php?f=180" class="md-button md-button--primary">Log Into SparkFun Forums</a></div>

If you are having problems connecting to the BNO086 and you see the following output after resetting the RedBoard IoT - ESP32 in the Serial Monitor, there could be a few reasons why.

<div style="text-align: center;">
  <table>
    <tr style="vertical-align:middle;">
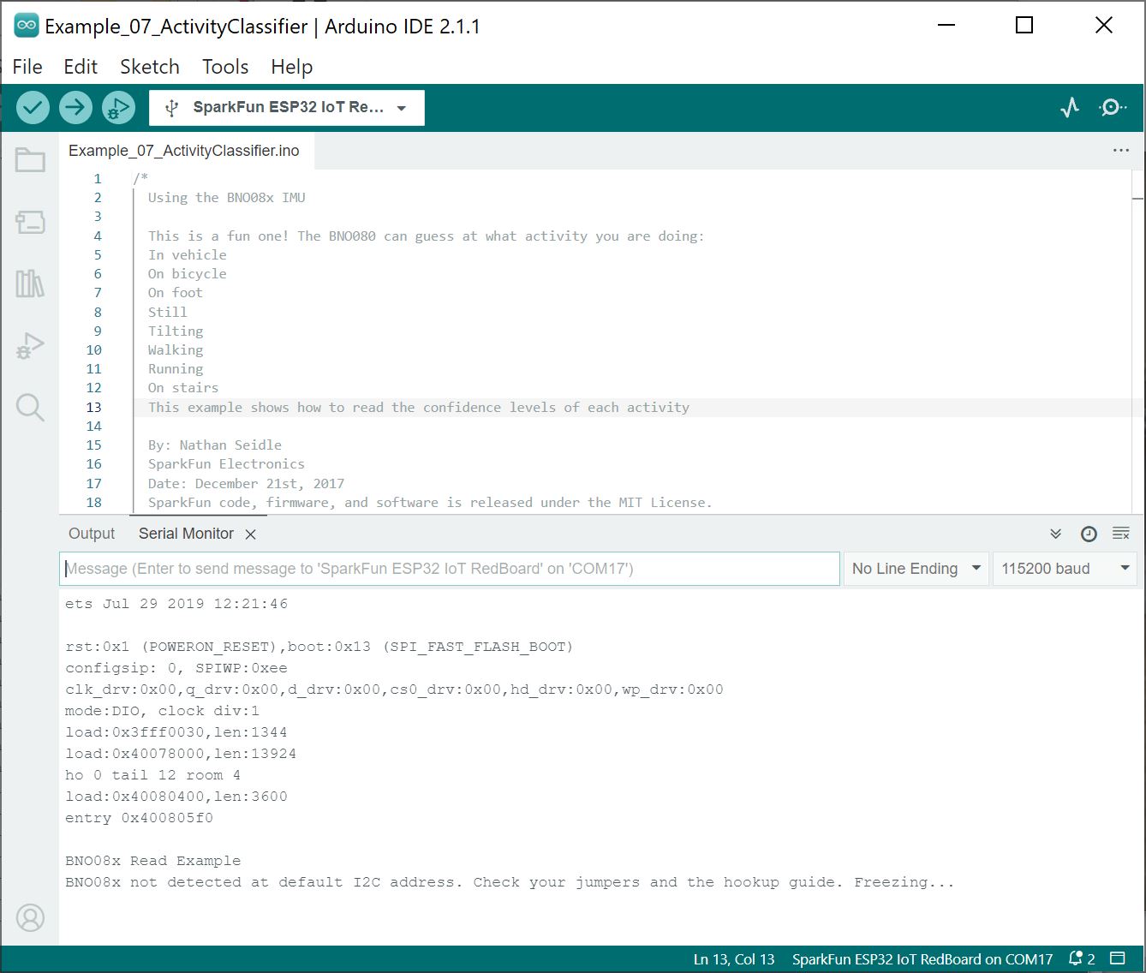
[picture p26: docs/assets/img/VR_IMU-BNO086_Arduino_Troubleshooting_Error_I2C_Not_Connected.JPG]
Error Not Connected
     <td style="text-align: center; vertical-align: middle;"></td>
    </tr>
  </table>
</div>

If you are using the I<sup>2</sup>C examples, try checking your connections and the Qwiic cable for loose connections. Also, ensure that the correct I<sup>2</sup>C's address jumper is selected as well as the jumpers for the protocol selection. The communication may also be out of sync with the BNO086. You may need to power cycle the board by removing the cable from the connector and reconnecting it.

You may also want to try connecting the interrupt and reset pins to the board for a hardware reset. Make sure to check example 17 for more information about modifying the example to include the hardware reset.

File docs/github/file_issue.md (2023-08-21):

# Did we make a mistake?

Spot something wrong? Please let us know. 

!!! attention
    This is not where customers should seek assistance on a product. If you require technical assistance or have questions about a product that is not working as expected, please head over to the [SparkFun Technical Assistance](https://www.sparkfun.com/technical_assistance) page for some initial troubleshooting.
    <center>
    [SparkFun Technical Assistance Page](https://www.sparkfun.com/technical_assistance){ .md-button .md-button--primary }
    </center>

    If you can't find what you need there, you'll need a [Forum Account](https://forum.sparkfun.com/ucp.php?mode=register) to search product forums and post questions.

## Discrepancies in the Documentation

All of this documentation can be modified by you! Please help us make it better.

* The documentation files for these pages are contained in the [`docs` folder of the SparkFun VR IMU Breakout - BNO086 (Qwiic) repository](https://github.com/sparkfun/SparkFun_VR_IMU_Breakout_BNO086_QWIIC/tree/main/docs).

### Spot something wrong?
If a section of the documentation is incorrect, please [open an issue](https://github.com/sparkfun/SparkFun_VR_IMU_Breakout_BNO086_QWIIC/issues) and let us know.

### Do you have a suggested correction?
1. With a GitHub account, fork this repo
2. Add your correction(s) or improvement(s) to the markdown file(s)
3. File a pull request with your changes, and enjoy making the ~~words~~ ~~worlds~~ world a better place.
    * Once received, the documentation specialist will automatically be notified.
    * We will review your suggested improvement(s) to make sure they are correct and fit within our documentation standards.

## Problems in the Hardware Design

All of our designs are open-source! Please help us make it better.

* Our board design files are contained in the [`Hardware` folder of the SparkFun VR IMU Breakout - BNO086 (Qwiic) repository](https://github.com/sparkfun/SparkFun_VR_IMU_Breakout_BNO086_QWIIC/tree/main/Hardware).

### Does something not make sense?
If part of the design is confusing, please [open an issue](https://github.com/sparkfun/SparkFun_VR_IMU_Breakout_BNO086_QWIIC/issues) and let us know.

### Did we forget to include an important function of the board?
* Please keep in mind that we may intentionally exclude certain functions of the board to meet our product design requirements. *(For example, our Qwiic Micro boards are intended to fit on a small board layout and only use I<sup>2</sup>C communication; therefore, we may not have the SPI and interrupt pins available for users.)*
* If part of the board's functionality is missing, please [open an issue](https://github.com/sparkfun/SparkFun_VR_IMU_Breakout_BNO086_QWIIC/issues) and file a feature request.

### Do you wish to contribute directly to improving the board design?
1. With a GitHub account, Fork this repo
2. Add your design improvement(s)
3. File a pull request with your changes, and enjoy making the ~~words~~ ~~worlds~~ world a better place.
    * Once received, the engineer in charge of the original design will automatically be notified.
    * We will review your suggested improvement(s), if they are within our board design standards and meet our product design requirements, we will flag these changes for our next board revision. *(Please note, that even if your suggestion is accepted, these changes may not be immediate. We may have to cycle through our current product inventory first.)*

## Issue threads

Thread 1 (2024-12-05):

Example 13

AlanTJohnstone, 2024-12-05:
Because the axis of the sensor are Z up and Y facing north
( see Figure 4-2: BNO08X mounted in a device in the datasheet) Example 13 Euler Angles gives the wrong output. So pitch and roll have to be swapped and yaw (or heading) is 360 - yaw.

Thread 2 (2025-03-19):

Numerous build warnings with compiler warnings to All

PhiJu5, 2025-03-19:
Hello
Usually it's good to have a look...
Regards

`
:\Arduino\libraries\SparkFun_BNO08x_Arduino_Library-main\src\shtp.c: In function 'shtpAdvertHdlr':
e:\Arduino\libraries\SparkFun_BNO08x_Arduino_Library-main\src\shtp.c:331:63: warning: unused parameter 'len' [-Wunused-parameter]
 static void shtpAdvertHdlr(void *cookie, uint8_t tag, uint8_t len, uint8_t *val)
                                                               ^~~
e:\Arduino\libraries\SparkFun_BNO08x_Arduino_Library-main\src\shtp.c: In function 'shtpCmdListener':
e:\Arduino\libraries\SparkFun_BNO08x_Arduino_Library-main\src\shtp.c:526:84: warning: unused parameter 'timestamp' [-Wunused-parameter]
 static void shtpCmdListener(void *cookie, uint8_t *payload, uint16_t len, uint32_t timestamp)
                                                                                    ^~~~~~~~~
e:\Arduino\libraries\SparkFun_BNO08x_Arduino_Library-main\src\sh2.c: In function 'sensorhubControlHdlr':
e:\Arduino\libraries\SparkFun_BNO08x_Arduino_Library-main\src\sh2.c:398:89: warning: unused parameter 'timestamp' [-Wunused-parameter]
 static void sensorhubControlHdlr(void *cookie, uint8_t *payload, uint16_t len, uint32_t timestamp)
                                                                                         ^~~~~~~~~
e:\Arduino\libraries\SparkFun_BNO08x_Arduino_Library-main\src\sh2.c: In function 'executableAdvertHdlr':
e:\Arduino\libraries\SparkFun_BNO08x_Arduino_Library-main\src\sh2.c:631:40: warning: unused parameter 'cookie' [-Wunused-parameter]
 static void executableAdvertHdlr(void *cookie, uint8_t tag, uint8_t len, uint8_t *value)
                                        ^~~~~~
e:\Arduino\libraries\SparkFun_BNO08x_Arduino_Library-main\src\sh2.c:631:56: warning: unused parameter 'tag' [-Wunused-parameter]
 static void executableAdvertHdlr(void *cookie, uint8_t tag, uint8_t len, uint8_t *value)
                                                        ^~~
e:\Arduino\libraries\SparkFun_BNO08x_Arduino_Library-main\src\sh2.c:631:69: warning: unused parameter 'len' [-Wunused-parameter]
 static void executableAdvertHdlr(void *cookie, uint8_t tag, uint8_t len, uint8_t *value)
                                                                     ^~~
e:\Arduino\libraries\SparkFun_BNO08x_Arduino_Library-main\src\sh2.c:631:83: warning: unused parameter 'value' [-Wunused-parameter]
 static void executableAdvertHdlr(void *cookie, uint8_t tag, uint8_t len, uint8_t *value)
                                                                                   ^~~~~
e:\Arduino\libraries\SparkFun_BNO08x_Arduino_Library-main\src\sh2.c: In function 'executableDeviceHdlr':
e:\Arduino\libraries\SparkFun_BNO08x_Arduino_Library-main\src\sh2.c:636:89: warning: unused parameter 'timestamp' [-Wunused-parameter]
 static void executableDeviceHdlr(void *cookie, uint8_t *payload, uint16_t len, uint32_t timestamp)
                                                                                         ^~~~~~~~~
e:\Arduino\libraries\SparkFun_BNO08x_Arduino_Library-main\src\sh2.c: In function 'getProdIdRx':
e:\Arduino\libraries\SparkFun_BNO08x_Arduino_Library-main\src\sh2.c:702:71: warning: unused parameter 'len' [-Wunused-parameter]
 static void getProdIdRx(sh2_t *pSh2, const uint8_t *payload, uint16_t len)
                                                                       ^~~
e:\Arduino\libraries\SparkFun_BNO08x_Arduino_Library-main\src\sh2.c: In function 'getSensorConfigRx':
e:\Arduino\libraries\SparkFun_BNO08x_Arduino_Library-main\src\sh2.c:769:77: warning: unused parameter 'len' [-Wunused-parameter]
 static void getSensorConfigRx(sh2_t *pSh2, const uint8_t *payload, uint16_t len)
                                                                             ^~~
e:\Arduino\libraries\SparkFun_BNO08x_Arduino_Library-main\src\sh2.c: In function 'getFrsRx':
e:\Arduino\libraries\SparkFun_BNO08x_Arduino_Library-main\src\sh2.c:951:68: warning: unused parameter 'len' [-Wunused-parameter]
 static void getFrsRx(sh2_t *pSh2, const uint8_t *payload, uint16_t len)
                                                                    ^~~
e:\Arduino\libraries\SparkFun_BNO08x_Arduino_Library-main\src\sh2.c: At top level:
e:\Arduino\libraries\SparkFun_BNO08x_Arduino_Library-main\src\sh2.c:1022:1: warning: 'static' is not at beginning of declaration [-Wold-style-declaration]
 const static struct {
 ^~~~~
e:\Arduino\libraries\SparkFun_BNO08x_Arduino_Library-main\src\sh2.c: In function 'setFrsRx':
e:\Arduino\libraries\SparkFun_BNO08x_Arduino_Library-main\src\sh2.c:1148:68: warning: unused parameter 'len' [-Wunused-parameter]
 static void setFrsRx(sh2_t *pSh2, const uint8_t *payload, uint16_t len)
                                                                    ^~~
e:\Arduino\libraries\SparkFun_BNO08x_Arduino_Library-main\src\sh2.c: In function 'getErrorsRx':
e:\Arduino\libraries\SparkFun_BNO08x_Arduino_Library-main\src\sh2.c:1302:71: warning: unused parameter 'len' [-Wunused-parameter]
 static void getErrorsRx(sh2_t *pSh2, const uint8_t *payload, uint16_t len)
                                                                       ^~~
e:\Arduino\libraries\SparkFun_BNO08x_Arduino_Library-main\src\sh2.c: In function 'getCountsRx':
e:\Arduino\libraries\SparkFun_BNO08x_Arduino_Library-main\src\sh2.c:1345:71: warning: unused parameter 'len' [-Wunused-parameter]
 static void getCountsRx(sh2_t *pSh2, const uint8_t *payload, uint16_t len)
                                                                       ^~~
e:\Arduino\libraries\SparkFun_BNO08x_Arduino_Library-main\src\sh2.c: In function 'reinitRx':
e:\Arduino\libraries\SparkFun_BNO08x_Arduino_Library-main\src\sh2.c:1401:68: warning: unused parameter 'len' [-Wunused-parameter]
 static void reinitRx(sh2_t *pSh2, const uint8_t *payload, uint16_t len)
                                                                    ^~~
e:\Arduino\libraries\SparkFun_BNO08x_Arduino_Library-main\src\sh2.c: In function 'saveDcdNowRx':
e:\Arduino\libraries\SparkFun_BNO08x_Arduino_Library-main\src\sh2.c:1432:72: warning: unused parameter 'len' [-Wunused-parameter]
 static void saveDcdNowRx(sh2_t *pSh2, const uint8_t *payload, uint16_t len)
                                                                        ^~~
e:\Arduino\libraries\SparkFun_BNO08x_Arduino_Library-main\src\sh2.c: In function 'getOscTypeRx':
e:\Arduino\libraries\SparkFun_BNO08x_Arduino_Library-main\src\sh2.c:1461:72: warning: unused parameter 'len' [-Wunused-parameter]
 static void getOscTypeRx(sh2_t *pSh2, const uint8_t *payload, uint16_t len)
                                                                        ^~~
e:\Arduino\libraries\SparkFun_BNO08x_Arduino_Library-main\src\sh2.c: In function 'setCalConfigRx':
e:\Arduino\libraries\SparkFun_BNO08x_Arduino_Library-main\src\sh2.c:1501:74: warning: unused parameter 'len' [-Wunused-parameter]
 static void setCalConfigRx(sh2_t *pSh2, const uint8_t *payload, uint16_t len)
                                                                          ^~~
e:\Arduino\libraries\SparkFun_BNO08x_Arduino_Library-main\src\sh2.c: In function 'getCalConfigRx':
e:\Arduino\libraries\SparkFun_BNO08x_Arduino_Library-main\src\sh2.c:1539:74: warning: unused parameter 'len' [-Wunused-parameter]
 static void getCalConfigRx(sh2_t *pSh2, const uint8_t *payload, uint16_t len)
                                                                          ^~~
e:\Arduino\libraries\SparkFun_BNO08x_Arduino_Library-main\src\sh2.c: In function 'forceFlushRx':
e:\Arduino\libraries\SparkFun_BNO08x_Arduino_Library-main\src\sh2.c:1585:72: warning: unused parameter 'len' [-Wunused-parameter]
 static void forceFlushRx(sh2_t *pSh2, const uint8_t *payload, uint16_t len)
                                                                        ^~~
e:\Arduino\libraries\SparkFun_BNO08x_Arduino_Library-main\src\sh2.c: In function 'startCalRx':
e:\Arduino\libraries\SparkFun_BNO08x_Arduino_Library-main\src\sh2.c:1622:70: warning: unused parameter 'len' [-Wunused-parameter]
 static void startCalRx(sh2_t *pSh2, const uint8_t *payload, uint16_t len)
                                                                      ^~~
e:\Arduino\libraries\SparkFun_BNO08x_Arduino_Library-main\src\sh2.c: In function 'finishCalRx':
e:\Arduino\libraries\SparkFun_BNO08x_Arduino_Library-main\src\sh2.c:1646:71: warning: unused parameter 'len' [-Wunused-parameter]
 static void finishCalRx(sh2_t *pSh2, const uint8_t *payload, uint16_t len)
                                                                       ^~~
e:\Arduino\libraries\SparkFun_BNO08x_Arduino_Library-main\src\sh2.c: In function 'shtpEventCallback':
e:\Arduino\libraries\SparkFun_BNO08x_Arduino_Library-main\src\sh2.c:1673:37: warning: unused parameter 'cookie' [-Wunused-parameter]
 static void shtpEventCallback(void *cookie, shtp_Event_t shtpEvent) {
                                     ^~~~~~
e:\Arduino\libraries\SparkFun_BNO08x_Arduino_Library-main\src\sh2.c: In function 'sh2_getMetadata':
e:\Arduino\libraries\SparkFun_BNO08x_Arduino_Library-main\src\sh2.c:1916:19: warning: comparison between signed and unsigned integer expressions [-Wsign-compare]
     for (i = 0; i < ARRAY_LEN(sensorToRecordMap); i++) {
                   ^
e:\Arduino\libraries\SparkFun_BNO08x_Arduino_Library-main\src\sh2.c:1921:11: warning: comparison between signed and unsigned integer expressions [-Wsign-compare]
     if (i >= ARRAY_LEN(sensorToRecordMap)) {
           ^~
e:\Arduino\libraries\SparkFun_BNO08x_Arduino_Library-main\src\sh2.c: In function 'sh2_finishCal':
e:\Arduino\libraries\SparkFun_BNO08x_Arduino_Library-main\src\sh2.c:2302:36: warning: unused parameter 'status' [-Wunused-parameter]
 int sh2_finishCal(sh2_CalStatus_t *status)
                                    ^~~~~~
Compiling library "SPI"
e:\Arduino\libraries\SparkFun_BNO08x_Arduino_Library-main\src\SparkFun_BNO08x_Arduino_Library.cpp: In member function 'virtual bool BNO08x::_init(int32_t)':
e:\Arduino\libraries\SparkFun_BNO08x_Arduino_Library-main\src\SparkFun_BNO08x_Arduino_Library.cpp:1079:28: warning: unused parameter 'sensor_id' [-Wunused-parameter]
 bool BNO08x::_init(int32_t sensor_id) {
                            ^~~~~~~~~
e:\Arduino\libraries\SparkFun_BNO08x_Arduino_Library-main\src\SparkFun_BNO08x_Arduino_Library.cpp: In function 'int i2chal_open(sh2_Hal_t*)':
e:\Arduino\libraries\SparkFun_BNO08x_Arduino_Library-main\src\SparkFun_BNO08x_Arduino_Library.cpp:1182:35: warning: unused parameter 'self' [-Wunused-parameter]
 static int i2chal_open(sh2_Hal_t *self) {
                                   ^~~~
e:\Arduino\libraries\SparkFun_BNO08x_Arduino_Library-main\src\SparkFun_BNO08x_Arduino_Library.cpp: In function 'void i2chal_close(sh2_Hal_t*)':
e:\Arduino\libraries\SparkFun_BNO08x_Arduino_Library-main\src\SparkFun_BNO08x_Arduino_Library.cpp:1202:37: warning: unused parameter 'self' [-Wunused-parameter]
 static void i2chal_close(sh2_Hal_t *self) {
                                     ^~~~
e:\Arduino\libraries\SparkFun_BNO08x_Arduino_Library-main\src\SparkFun_BNO08x_Arduino_Library.cpp: In function 'int i2chal_read(sh2_Hal_t*, uint8_t*, unsigned int, uint32_t*)':
e:\Arduino\libraries\SparkFun_BNO08x_Arduino_Library-main\src\SparkFun_BNO08x_Arduino_Library.cpp:1206:35: warning: unused parameter 'self' [-Wunused-parameter]
 static int i2chal_read(sh2_Hal_t *self, uint8_t *pBuffer, unsigned len,
                                   ^~~~
e:\Arduino\libraries\SparkFun_BNO08x_Arduino_Library-main\src\SparkFun_BNO08x_Arduino_Library.cpp:1207:34: warning: unused parameter 't_us' [-Wunused-parameter]
                        uint32_t *t_us) {
                                  ^~~~
e:\Arduino\libraries\SparkFun_BNO08x_Arduino_Library-main\src\SparkFun_BNO08x_Arduino_Library.cpp: In function 'int i2chal_write(sh2_Hal_t*, uint8_t*, unsigned int)':
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
PhiJu5, 2025-03-19:
Please ignore, as can't be delete.

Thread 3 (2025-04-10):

This sensor not getting detected while interfacing it with ESP32 Dev module

cloud-tentosoft, 2025-04-10:
Hi,

I have connected Esp32 Dev module with Sparkfun BNO086 sensor. But i2c scanning itself not working. i tried many ways, i shorted ADR on board and set 0x4A as address. and then tried connecting with and without INT and RST pins and also tried with different i2c frequency. Nothing works out.

Please help me to resolve this connection issue with ESP32 Dev module.

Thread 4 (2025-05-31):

Feature request: allow begin() to accept software wire, to allow clock stretching on MCUs with hardware limits (e.g esp32)

MickTheMechanic, 2025-05-31:
Feature request:

At the moment the library only accepts hardware i2c, which is a problem on devices that have limited clock stretching capability.

It would be really cool to allow the possibility to use software i2c libraries, allowing longer clock stretching.

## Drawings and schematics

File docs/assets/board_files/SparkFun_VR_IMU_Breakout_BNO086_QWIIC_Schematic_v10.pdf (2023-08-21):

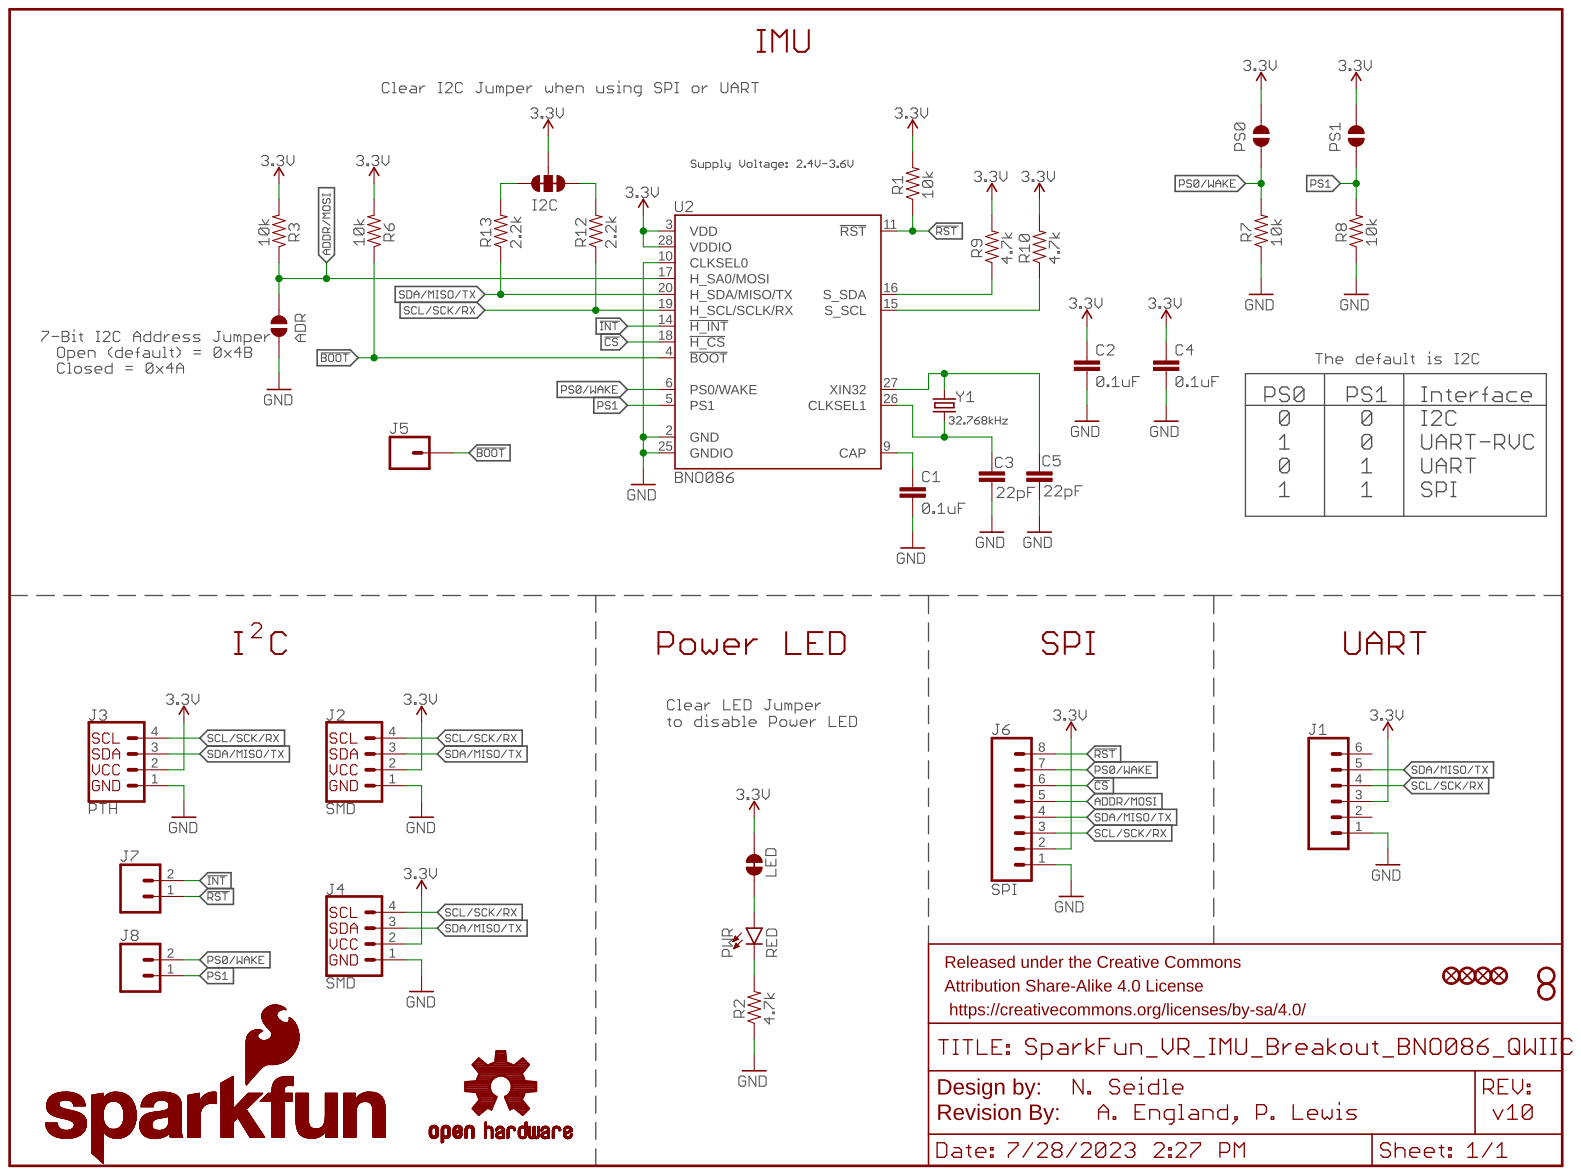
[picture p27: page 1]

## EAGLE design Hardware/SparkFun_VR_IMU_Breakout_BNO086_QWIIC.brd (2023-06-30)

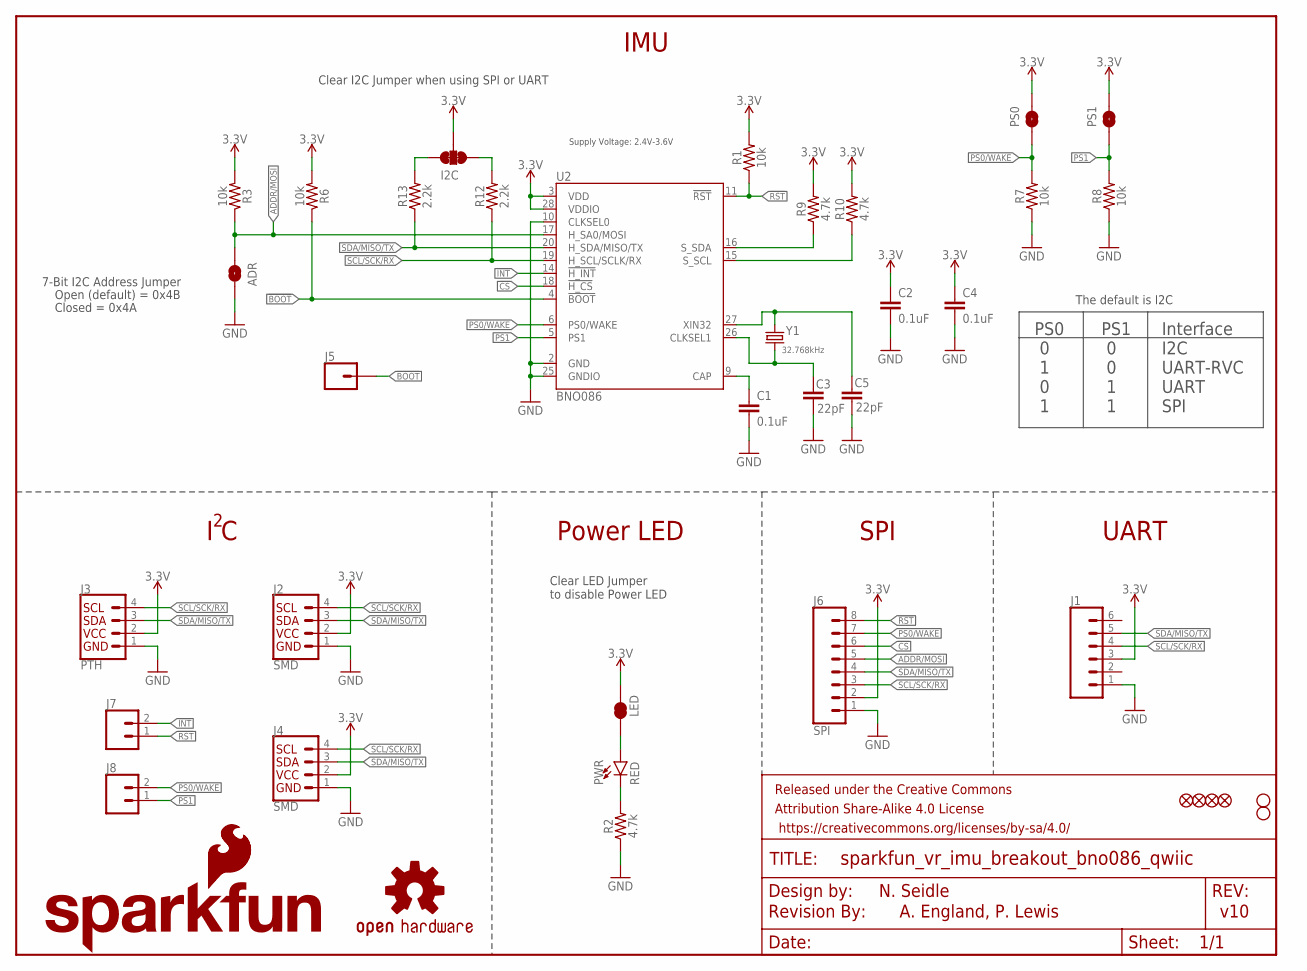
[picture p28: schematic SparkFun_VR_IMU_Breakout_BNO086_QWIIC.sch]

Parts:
ADR: JUMPER-SMT_2_NO_SILK; SMT-JUMPER_2_NO_SILK
C1, C2, C4: 0.1uF; 0603
C3, C5: 22pF; 0603
FRAME1: FRAME-LETTER; CREATIVE_COMMONS
I2C: JUMPER-SMT_3_2-NC_TRACE_SILK; SMT-JUMPER_3_2-NC_TRACE_SILK
J1: CONN_06NO_SILK_FEMALE_PTH; 1X06_NO_SILK
J2, J4: SMD; JST04_1MM_RA
J3: PTH; 1X04_NO_SILK
J5: CONN_01PTH_NO_SILK_YES_STOP; 1X01_NO_SILK
J6: SPI; 1X08_NO_SILK
J7, J8: CONN_021X02_NO_SILK; 1X02_NO_SILK
JP1, JP2, JP5, JP6: FIDUCIALUFIDUCIAL; FIDUCIAL-MICRO
JP3, JP4: STAND-OFF
LED: JUMPER-SMT_2_NC_TRACE_SILK; SMT-JUMPER_2_NC_TRACE_SILK
LOGO1: OSHW-LOGOMINI; OSHW-LOGO-MINI
LOGO2: REVISION
LOGO4: SFE_LOGO_FLAME.2_INCH; SFE_LOGO_FLAME_.2
LOGO5: SFE_LOGO_NAME_FLAME.1_INCH; SFE_LOGO_NAME_FLAME_.1
PS0, PS1: JUMPER-SMT_2_NO_SILK; SMT-JUMPER_2_NO_SILK
PWR: RED; LED-0603
R1, R3, R6, R7, R8: 10k; 0603
R2, R9, R10: 4.7k; 0603
R12, R13: 2.2k; 0603
U2: BNO086; LGA-28
Y1: 32.768kHz; CRYSTAL-SMD-3.2X1.5MM

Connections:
3.3V: C2.1, C4.1, I2C.2, J1.3, J2.2, J3.2, J4.2, J6.2, LED.1, PS0.1, PS1.1, R1.2, R3.2, R6.2, R9.2, R10.2, U2.3 (VDD), U2.28 (VDDIO)
!BOOT: J5.1, R6.1, U2.4 (!BOOT)
!CS: J6.6, U2.18 (!H_CS)
!INT: J7.2, U2.14 (!H_INT)
!RST: J6.8, J7.1, R1.1, U2.11 (!RST)
ADDR/MOSI: ADR.2, J6.5, R3.1, U2.17 (H_SA0/MOSI)
CAP: C1.1, U2.9 (CAP)
GND: ADR.1, C1.2, C2.2, C3.2, C4.2, C5.2, J1.1, J2.1, J3.1, J4.1, J6.1, R2.1, R7.1, R8.1, U2.2 (GND), U2.10 (CLKSEL0), U2.25 (GNDIO)
unnamed: C5.1, U2.27 (XIN32), Y1.P$2 (2)
unnamed: C3.1, U2.26 (CLKSEL1), Y1.P$1 (1)
unnamed: PWR.C, R2.2
unnamed: LED.2, PWR.A
PS0/WAKE: J6.7, J8.2, PS0.2, R7.2, U2.6 (PS0/WAKE)
PS1: J8.1, PS1.2, R8.2, U2.5 (PS1)
SCL/SCK/RX: J1.4, J2.4, J3.4, J4.4, J6.3, R12.1, U2.19 (H_SCL/SCLK/RX)
SCL_PU: I2C.1, R12.2
SDA/MISO/TX: J1.5, J2.3, J3.3, J4.3, J6.4, R13.1, U2.20 (H_SDA/MISO/TX)
SDA_PU: I2C.3, R13.2
S_SCL: R10.1, U2.15 (S_SCL)
S_SDA: R9.1, U2.16 (S_SDA)

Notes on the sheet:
N. Seidle
v10
7-Bit I2C Address Jumper
Closed = 0x4A
Open (default) = 0x4B
PS0 0 1 0 1
PS1 0 0 1 1
Interface I2C UART-RVC UART SPI
The default is I2C
Clear I2C Jumper when using SPI or UART
I C
UART
SPI
A. England, P. Lewis
Supply Voltage: 2.4V-3.6V
IMU
Clear LED Jumper to disable Power LED
Power LED

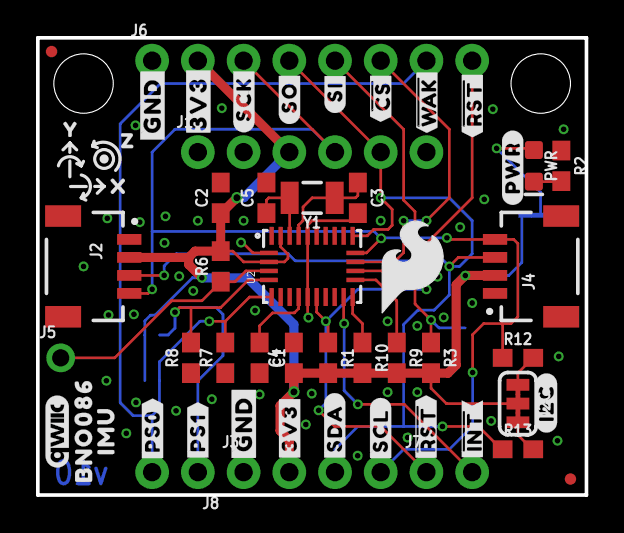
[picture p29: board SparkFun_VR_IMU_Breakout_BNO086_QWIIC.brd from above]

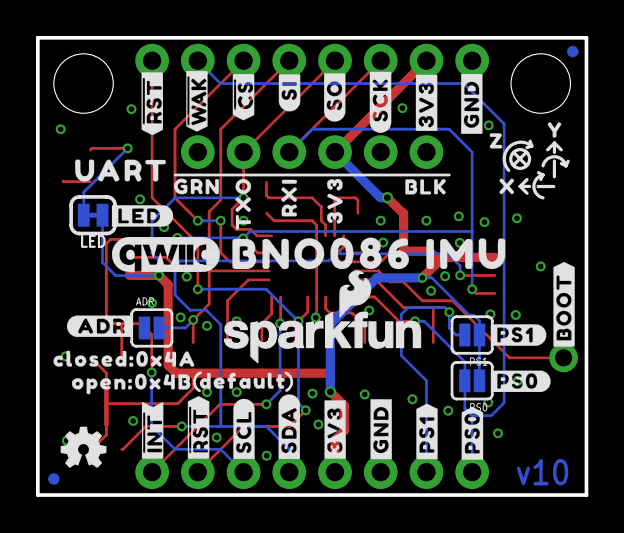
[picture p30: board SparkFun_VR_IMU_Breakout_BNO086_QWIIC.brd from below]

Board: 2 copper layers, 30.5 x 25.4 mm, 102 parts (43 on the bottom side), 20 nets.

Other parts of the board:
U$1: #I2C#874
U$2: BLK889
U$3, U$25: X878
U$4: ##INT##6
U$5: ##RST##5
U$6, U$10: Y879
U$7, U$15: Z880
U$8: #SCL#4
U$9, U$16: #GND#2
U$11: #SCK#882
U$12: #SO#867
U$13: #SI#868
U$14: #SDA#3
U$17: ##CS##870
U$18: ##CS##885
U$19: ##RST##872
U$20: ##RST##887
U$21: RXI891
U$22: TXO892
U$23: #PS0#874
U$24: BNO0861
U$26: #LED#0
U$27, U$46: #3V3#874
U$28: OPEN#0X4B0
U$29: QWIIC_4MM
U$30: #ADR#894
U$31: IMU862
U$32, U$45: #GND#864
U$33: #PS1#1
U$34: #PS0#2
U$35: #PS1#895
U$36: #3V3#865
U$37: #SCK#866
U$38: ##WAK##871
U$39: #3V3#882
U$40: 3V3891
U$41: GRN890
U$42: #PWR#873
U$43: #PS1#874
U$44: UART881
U$47: #SDA#874
U$48: #SCL#875
U$49: #BOOT#888
U$50: ##RST##876
U$51: ##INT##877
U$52: QWIIC_6MM
U$53: ##WAK##886
U$54: BNO086_IMU881
U$55: #SO#883
U$56: #SI#884
U$57: #PS0#895
U$58: CLOSED#0X4A0
U$59: ORDERING_INSTRUCTIONS
U$61: DEFAULT0

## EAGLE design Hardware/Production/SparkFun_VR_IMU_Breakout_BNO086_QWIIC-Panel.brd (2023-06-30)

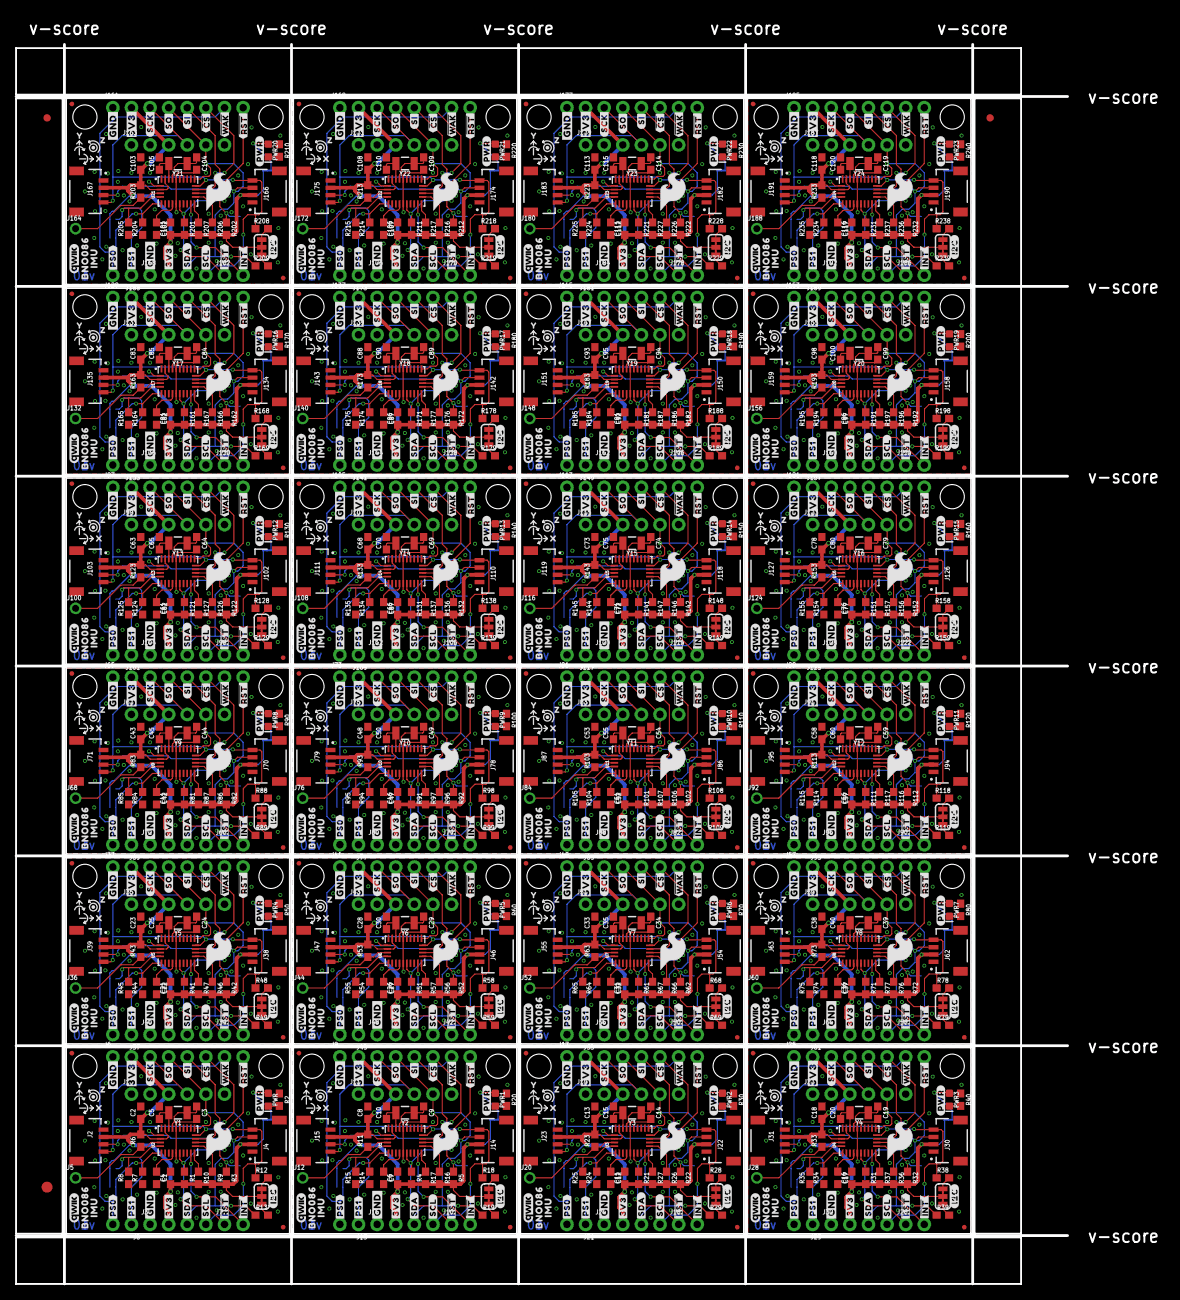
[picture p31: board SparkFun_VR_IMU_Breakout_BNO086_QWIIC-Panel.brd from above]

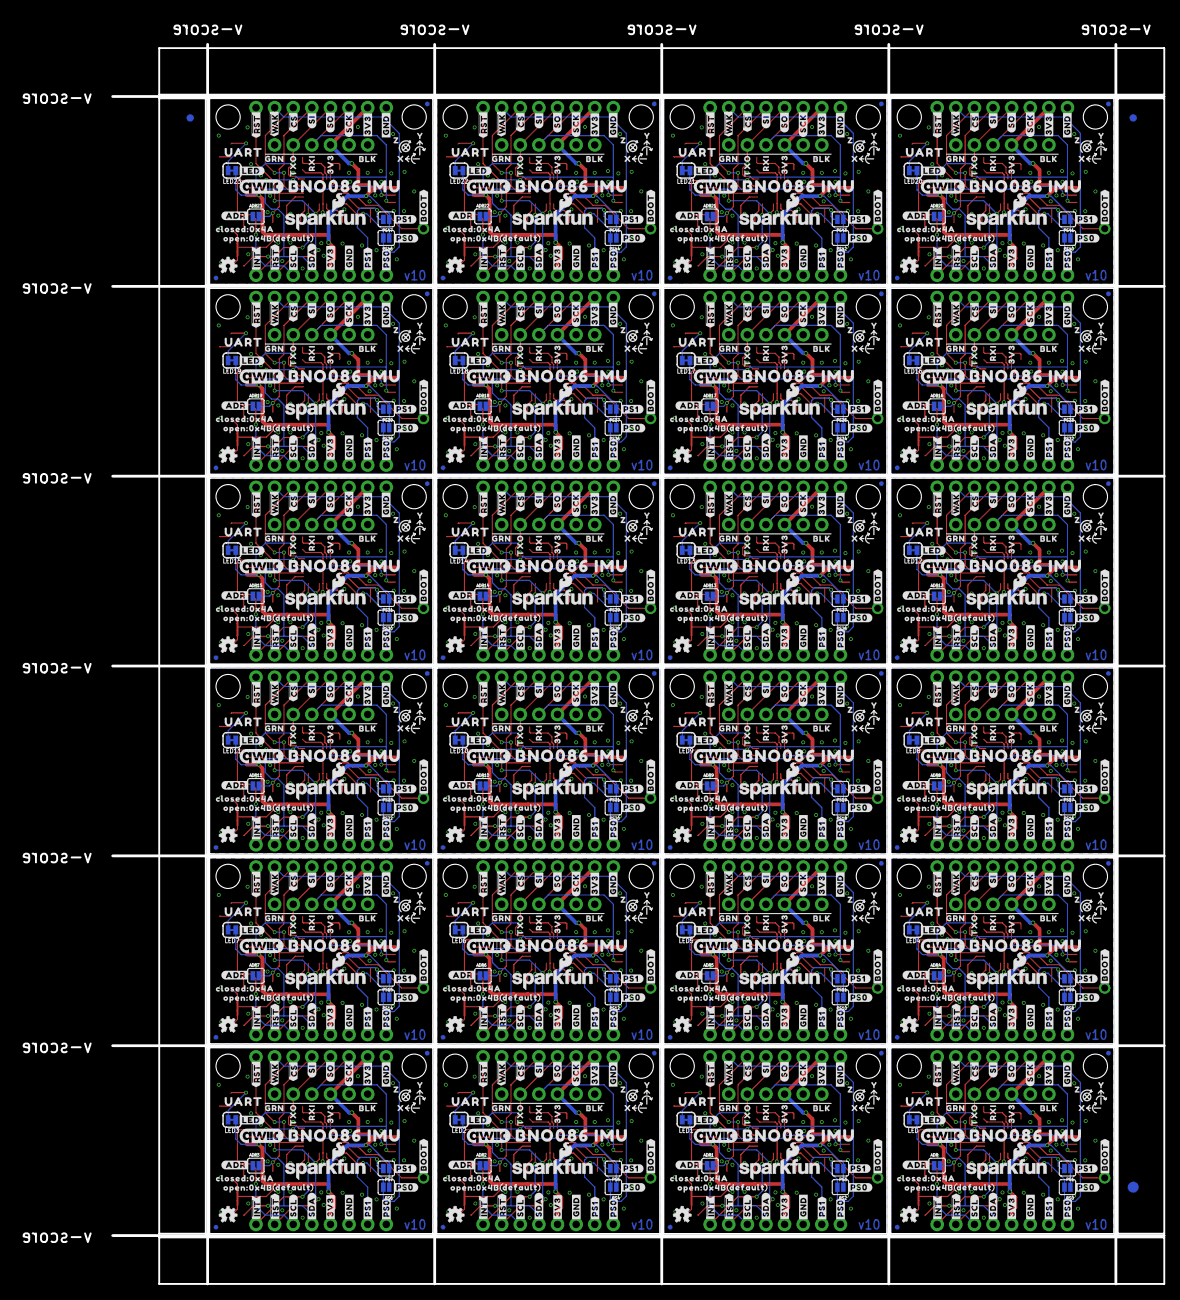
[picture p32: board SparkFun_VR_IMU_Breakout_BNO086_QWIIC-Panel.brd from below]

Board: 2 copper layers, 143.5 x 169.2 mm, 2406 parts (1035 on the bottom side), 480 nets.

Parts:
ADR, ADR1, ADR2, ADR3, ADR4, ADR5, ADR6, ADR7, ADR8, ADR9, ADR10, ADR11, ADR12, ADR13, ADR14, ADR15, ADR16, ADR17, ADR18, ADR19, ADR20, ADR21, ADR22, ADR23: SMT-JUMPER_2_NO_SILK
C1, C2, C4, C6, C7, C8, C11, C12, C13, C16, C17, C18, C21, C22, C23, C26, C27, C28, C31, C32, C33, C36, C37, C38, C41, C42, C43, C46, C47, C48, C51, C52, C53, C56, C57, C58, C61, C62, C63, C66, C67, C68, C71, C72, C73, C76, C77, C78, C81, C82, C83, C86, C87, C88, C91, C92, C93, C96, C97, C98, C101, C102, C103, C106, C107, C108, C111, C112, C113, C116, C117, C118: 0.1uF; 0603
C3, C5, C9, C10, C14, C15, C19, C20, C24, C25, C29, C30, C34, C35, C39, C40, C44, C45, C49, C50, C54, C55, C59, C60, C64, C65, C69, C70, C74, C75, C79, C80, C84, C85, C89, C90, C94, C95, C99, C100, C104, C105, C109, C110, C114, C115, C119, C120: 22pF; 0603
E$1, E$2, E$3, E$4: FIDUCIAL-1X2
E$5, E$6: FIDUCIAL-1.5X3
I2C, I2C1, I2C2, I2C3, I2C4, I2C5, I2C6, I2C7, I2C8, I2C9, I2C10, I2C11, I2C12, I2C13, I2C14, I2C15, I2C16, I2C17, I2C18, I2C19, I2C20, I2C21, I2C22, I2C23: SMT-JUMPER_3_2-NC_TRACE_SILK
J1, J11, J19, J27, J35, J43, J51, J59, J67, J75, J83, J91, J99, J107, J115, J123, J131, J139, J147, J155, J163, J171, J179, J187: 1X06_NO_SILK
J2, J4, J14, J15, J22, J23, J30, J31, J38, J39, J46, J47, J54, J55, J62, J63, J70, J71, J78, J79, J86, J87, J94, J95, J102, J103, J110, J111, J118, J119, J126, J127, J134, J135, J142, J143, J150, J151, J158, J159, J166, J167, J174, J175, J182, J183, J190, J191: SMD; JST04_1MM_RA
J3, J16, J24, J32, J40, J48, J56, J64, J72, J80, J88, J96, J104, J112, J120, J128, J136, J144, J152, J160, J168, J176, J184, J192: PTH; 1X04_NO_SILK
J5, J12, J20, J28, J36, J44, J52, J60, J68, J76, J84, J92, J100, J108, J116, J124, J132, J140, J148, J156, J164, J172, J180, J188: 1X01_NO_SILK
J6, J9, J17, J25, J33, J41, J49, J57, J65, J73, J81, J89, J97, J105, J113, J121, J129, J137, J145, J153, J161, J169, J177, J185: SPI; 1X08_NO_SILK
J7, J8, J10, J13, J18, J21, J26, J29, J34, J37, J42, J45, J50, J53, J58, J61, J66, J69, J74, J77, J82, J85, J90, J93, J98, J101, J106, J109, J114, J117, J122, J125, J130, J133, J138, J141, J146, J149, J154, J157, J162, J165, J170, J173, J178, J181, J186, J189: 1X02_NO_SILK
JP1, JP2, JP5, JP6, JP9, JP10, JP11, JP12, JP15, JP16, JP17, JP18, JP21, JP22, JP23, JP24, JP27, JP28, JP29, JP30, JP33, JP34, JP35, JP36, JP39, JP40, JP41, JP42, JP45, JP46, JP47, JP48, JP51, JP52, JP53, JP54, JP57, JP58, JP59, JP60, JP63, JP64, JP65, JP66, JP69, JP70, JP71, JP72, JP75, JP76, JP77, JP78, JP81, JP82, JP83, JP84, JP87, JP88, JP89, JP90, JP93, JP94, JP95, JP96, JP99, JP100, JP101, JP102, JP105, JP106, JP107, JP108, JP111, JP112, JP113, JP114, JP117, JP118, JP119, JP120, JP123, JP124, JP125, JP126, JP129, JP130, JP131, JP132, JP135, JP136, JP137, JP138, JP141, JP142, JP143, JP144: FIDUCIALUFIDUCIAL; FIDUCIAL-MICRO
JP3, JP4, JP7, JP8, JP13, JP14, JP19, JP20, JP25, JP26, JP31, JP32, JP37, JP38, JP43, JP44, JP49, JP50, JP55, JP56, JP61, JP62, JP67, JP68, JP73, JP74, JP79, JP80, JP85, JP86, JP91, JP92, JP97, JP98, JP103, JP104, JP109, JP110, JP115, JP116, JP121, JP122, JP127, JP128, JP133, JP134, JP139, JP140: STAND-OFF
LED, LED1, LED2, LED3, LED4, LED5, LED6, LED7, LED8, LED9, LED10, LED11, LED12, LED13, LED14, LED15, LED16, LED17, LED18, LED19, LED20, LED21, LED22, LED23: SMT-JUMPER_2_NC_TRACE_SILK
LOGO1, LOGO3, LOGO9, LOGO13, LOGO17, LOGO21, LOGO25, LOGO29, LOGO33, LOGO37, LOGO41, LOGO45, LOGO49, LOGO53, LOGO57, LOGO61, LOGO65, LOGO69, LOGO73, LOGO77, LOGO81, LOGO85, LOGO89, LOGO93: OSHW-LOGOMINI; OSHW-LOGO-MINI
LOGO2, LOGO8, LOGO12, LOGO16, LOGO20, LOGO24, LOGO28, LOGO32, LOGO36, LOGO40, LOGO44, LOGO48, LOGO52, LOGO56, LOGO60, LOGO64, LOGO68, LOGO72, LOGO76, LOGO80, LOGO84, LOGO88, LOGO92, LOGO96: REVISION
LOGO4, LOGO6, LOGO10, LOGO14, LOGO18, LOGO22, LOGO26, LOGO30, LOGO34, LOGO38, LOGO42, LOGO46, LOGO50, LOGO54, LOGO58, LOGO62, LOGO66, LOGO70, LOGO74, LOGO78, LOGO82, LOGO86, LOGO90, LOGO94: SFE_LOGO_FLAME.2_INCH; SFE_LOGO_FLAME_.2
LOGO5, LOGO7, LOGO11, LOGO15, LOGO19, LOGO23, LOGO27, LOGO31, LOGO35, LOGO39, LOGO43, LOGO47, LOGO51, LOGO55, LOGO59, LOGO63, LOGO67, LOGO71, LOGO75, LOGO79, LOGO83, LOGO87, LOGO91, LOGO95: SFE_LOGO_NAME_FLAME.1_INCH; SFE_LOGO_NAME_FLAME_.1
PS0, PS1, PS2, PS3, PS4, PS5, PS6, PS7, PS8, PS9, PS10, PS11, PS12, PS13, PS14, PS15, PS16, PS17, PS18, PS19, PS20, PS21, PS22, PS23, PS24, PS25, PS26, PS27, PS28, PS29, PS30, PS31, PS32, PS33, PS34, PS35, PS36, PS37, PS38, PS39, PS40, PS41, PS42, PS43, PS44, PS45, PS46, PS47: SMT-JUMPER_2_NO_SILK
PWR, PWR1, PWR2, PWR3, PWR4, PWR5, PWR6, PWR7, PWR8, PWR9, PWR10, PWR11, PWR12, PWR13, PWR14, PWR15, PWR16, PWR17, PWR18, PWR19, PWR20, PWR21, PWR22, PWR23: RED; LED-0603
R1, R3, R4, R5, R6, R7, R8, R11, R14, R15, R21, R22, R23, R24, R25, R31, R32, R33, R34, R35, R41, R42, R43, R44, R45, R51, R52, R53, R54, R55, R61, R62, R63, R64, R65, R71, R72, R73, R74, R75, R81, R82, R83, R84, R85, R91, R92, R93, R94, R95, R101, R102, R103, R104, R105, R111, R112, R113, R114, R115, R121, R122, R123, R124, R125, R131, R132, R133, R134, R135, R141, R142, R143, R144, R145, R151, R152, R153, R154, R155, R161, R162, R163, R164, R165, R171, R172, R173, R174, R175, R181, R182, R183, R184, R185, R191, R192, R193, R194, R195, R201, R202, R203, R204, R205, R211, R212, R213, R214, R215, R221, R222, R223, R224, R225, R231, R232, R233, R234, R235: 10k; 0603
R2, R9, R10, R16, R17, R20, R26, R27, R30, R36, R37, R40, R46, R47, R50, R56, R57, R60, R66, R67, R70, R76, R77, R80, R86, R87, R90, R96, R97, R100, R106, R107, R110, R116, R117, R120, R126, R127, R130, R136, R137, R140, R146, R147, R150, R156, R157, R160, R166, R167, R170, R176, R177, R180, R186, R187, R190, R196, R197, R200, R206, R207, R210, R216, R217, R220, R226, R227, R230, R236, R237, R240: 4.7k; 0603
R12, R13, R18, R19, R28, R29, R38, R39, R48, R49, R58, R59, R68, R69, R78, R79, R88, R89, R98, R99, R108, R109, R118, R119, R128, R129, R138, R139, R148, R149, R158, R159, R168, R169, R178, R179, R188, R189, R198, R199, R208, R209, R218, R219, R228, R229, R238, R239: 2.2k; 0603
U1, U2, U3, U4, U5, U6, U7, U8, U9, U10, U11, U12, U13, U14, U15, U16, U17, U18, U19, U20, U21, U22, U23, U24: BNO086; LGA-28
U$1, U$71, U$130, U$189, U$248, U$307, U$366, U$425, U$484, U$543, U$602, U$661, U$720, U$779, U$838, U$897, U$956, U$1015, U$1074, U$1133, U$1192, U$1251, U$1310, U$1369: #I2C#874
U$2, U$98, U$157, U$216, U$275, U$334, U$393, U$452, U$511, U$570, U$629, U$688, U$747, U$806, U$865, U$924, U$983, U$1042, U$1101, U$1160, U$1219, U$1278, U$1337, U$1396: BLK889
U$3, U$25, U$80, U$85, U$139, U$144, U$198, U$203, U$257, U$262, U$316, U$321, U$375, U$380, U$434, U$439, U$493, U$498, U$552, U$557, U$611, U$616, U$670, U$675, U$729, U$734, U$788, U$793, U$847, U$852, U$906, U$911, U$965, U$970, U$1024, U$1029, U$1083, U$1088, U$1142, U$1147, U$1201, U$1206, U$1260, U$1265, U$1319, U$1324, U$1378, U$1383: X878
U$4, U$113, U$172, U$231, U$290, U$349, U$408, U$467, U$526, U$585, U$644, U$703, U$762, U$821, U$880, U$939, U$998, U$1057, U$1116, U$1175, U$1234, U$1293, U$1352, U$1411: ##INT##6
U$5, U$112, U$171, U$230, U$289, U$348, U$407, U$466, U$525, U$584, U$643, U$702, U$761, U$820, U$879, U$938, U$997, U$1056, U$1115, U$1174, U$1233, U$1292, U$1351, U$1410: ##RST##5
U$6, U$10, U$81, U$83, U$140, U$142, U$199, U$201, U$258, U$260, U$317, U$319, U$376, U$378, U$435, U$437, U$494, U$496, U$553, U$555, U$612, U$614, U$671, U$673, U$730, U$732, U$789, U$791, U$848, U$850, U$907, U$909, U$966, U$968, U$1025, U$1027, U$1084, U$1086, U$1143, U$1145, U$1202, U$1204, U$1261, U$1263, U$1320, U$1322, U$1379, U$1381: Y879
U$7, U$15, U$82, U$84, U$141, U$143, U$200, U$202, U$259, U$261, U$318, U$320, U$377, U$379, U$436, U$438, U$495, U$497, U$554, U$556, U$613, U$615, U$672, U$674, U$731, U$733, U$790, U$792, U$849, U$851, U$908, U$910, U$967, U$969, U$1026, U$1028, U$1085, U$1087, U$1144, U$1146, U$1203, U$1205, U$1262, U$1264, U$1321, U$1323, U$1380, U$1382: Z880
U$8, U$111, U$170, U$229, U$288, U$347, U$406, U$465, U$524, U$583, U$642, U$701, U$760, U$819, U$878, U$937, U$996, U$1055, U$1114, U$1173, U$1232, U$1291, U$1350, U$1409: #SCL#4
U$9, U$16, U$109, U$114, U$168, U$173, U$227, U$232, U$286, U$291, U$345, U$350, U$404, U$409, U$463, U$468, U$522, U$527, U$581, U$586, U$640, U$645, U$699, U$704, U$758, U$763, U$817, U$822, U$876, U$881, U$935, U$940, U$994, U$999, U$1053, U$1058, U$1112, U$1117, U$1171, U$1176, U$1230, U$1235, U$1289, U$1294, U$1348, U$1353, U$1407, U$1412: #GND#2
U$11, U$91, U$150, U$209, U$268, U$327, U$386, U$445, U$504, U$563, U$622, U$681, U$740, U$799, U$858, U$917, U$976, U$1035, U$1094, U$1153, U$1212, U$1271, U$1330, U$1389: #SCK#882
U$12, U$65, U$124, U$183, U$242, U$301, U$360, U$419, U$478, U$537, U$596, U$655, U$714, U$773, U$832, U$891, U$950, U$1009, U$1068, U$1127, U$1186, U$1245, U$1304, U$1363: #SO#867
U$13, U$66, U$125, U$184, U$243, U$302, U$361, U$420, U$479, U$538, U$597, U$656, U$715, U$774, U$833, U$892, U$951, U$1010, U$1069, U$1128, U$1187, U$1246, U$1305, U$1364: #SI#868
U$14, U$110, U$169, U$228, U$287, U$346, U$405, U$464, U$523, U$582, U$641, U$700, U$759, U$818, U$877, U$936, U$995, U$1054, U$1113, U$1172, U$1231, U$1290, U$1349, U$1408: #SDA#3
U$17, U$67, U$126, U$185, U$244, U$303, U$362, U$421, U$480, U$539, U$598, U$657, U$716, U$775, U$834, U$893, U$952, U$1011, U$1070, U$1129, U$1188, U$1247, U$1306, U$1365: ##CS##870
U$18, U$94, U$153, U$212, U$271, U$330, U$389, U$448, U$507, U$566, U$625, U$684, U$743, U$802, U$861, U$920, U$979, U$1038, U$1097, U$1156, U$1215, U$1274, U$1333, U$1392: ##CS##885
U$19, U$69, U$128, U$187, U$246, U$305, U$364, U$423, U$482, U$541, U$600, U$659, U$718, U$777, U$836, U$895, U$954, U$1013, U$1072, U$1131, U$1190, U$1249, U$1308, U$1367: ##RST##872
U$20, U$96, U$155, U$214, U$273, U$332, U$391, U$450, U$509, U$568, U$627, U$686, U$745, U$804, U$863, U$922, U$981, U$1040, U$1099, U$1158, U$1217, U$1276, U$1335, U$1394: ##RST##887
U$21, U$101, U$160, U$219, U$278, U$337, U$396, U$455, U$514, U$573, U$632, U$691, U$750, U$809, U$868, U$927, U$986, U$1045, U$1104, U$1163, U$1222, U$1281, U$1340, U$1399: RXI891
U$22, U$102, U$161, U$220, U$279, U$338, U$397, U$456, U$515, U$574, U$633, U$692, U$751, U$810, U$869, U$928, U$987, U$1046, U$1105, U$1164, U$1223, U$1282, U$1341, U$1400: TXO892
U$23, U$72, U$131, U$190, U$249, U$308, U$367, U$426, U$485, U$544, U$603, U$662, U$721, U$780, U$839, U$898, U$957, U$1016, U$1075, U$1134, U$1193, U$1252, U$1311, U$1370: #PS0#874
U$24, U$59, U$119, U$178, U$237, U$296, U$355, U$414, U$473, U$532, U$591, U$650, U$709, U$768, U$827, U$886, U$945, U$1004, U$1063, U$1122, U$1181, U$1240, U$1299, U$1358: BNO0861
U$26, U$115, U$174, U$233, U$292, U$351, U$410, U$469, U$528, U$587, U$646, U$705, U$764, U$823, U$882, U$941, U$1000, U$1059, U$1118, U$1177, U$1236, U$1295, U$1354, U$1413: #LED#0
U$27, U$46, U$75, U$108, U$134, U$167, U$193, U$226, U$252, U$285, U$311, U$344, U$370, U$403, U$429, U$462, U$488, U$521, U$547, U$580, U$606, U$639, U$665, U$698, U$724, U$757, U$783, U$816, U$842, U$875, U$901, U$934, U$960, U$993, U$1019, U$1052, U$1078, U$1111, U$1137, U$1170, U$1196, U$1229, U$1255, U$1288, U$1314, U$1347, U$1373, U$1406: #3V3#874
U$28, U$116, U$175, U$234, U$293, U$352, U$411, U$470, U$529, U$588, U$647, U$706, U$765, U$824, U$883, U$942, U$1001, U$1060, U$1119, U$1178, U$1237, U$1296, U$1355, U$1414: OPEN#0X4B0
U$29, U$86, U$145, U$204, U$263, U$322, U$381, U$440, U$499, U$558, U$617, U$676, U$735, U$794, U$853, U$912, U$971, U$1030, U$1089, U$1148, U$1207, U$1266, U$1325, U$1384: QWIIC_4MM
U$30, U$103, U$162, U$221, U$280, U$339, U$398, U$457, U$516, U$575, U$634, U$693, U$752, U$811, U$870, U$929, U$988, U$1047, U$1106, U$1165, U$1224, U$1283, U$1342, U$1401: #ADR#894
U$31, U$60, U$120, U$179, U$238, U$297, U$356, U$415, U$474, U$533, U$592, U$651, U$710, U$769, U$828, U$887, U$946, U$1005, U$1064, U$1123, U$1182, U$1241, U$1300, U$1359: IMU862
U$32, U$45, U$62, U$74, U$121, U$133, U$180, U$192, U$239, U$251, U$298, U$310, U$357, U$369, U$416, U$428, U$475, U$487, U$534, U$546, U$593, U$605, U$652, U$664, U$711, U$723, U$770, U$782, U$829, U$841, U$888, U$900, U$947, U$959, U$1006, U$1018, U$1065, U$1077, U$1124, U$1136, U$1183, U$1195, U$1242, U$1254, U$1301, U$1313, U$1360, U$1372: #GND#864
U$33, U$106, U$165, U$224, U$283, U$342, U$401, U$460, U$519, U$578, U$637, U$696, U$755, U$814, U$873, U$932, U$991, U$1050, U$1109, U$1168, U$1227, U$1286, U$1345, U$1404: #PS1#1
U$34, U$107, U$166, U$225, U$284, U$343, U$402, U$461, U$520, U$579, U$638, U$697, U$756, U$815, U$874, U$933, U$992, U$1051, U$1110, U$1169, U$1228, U$1287, U$1346, U$1405: #PS0#2
U$35, U$104, U$163, U$222, U$281, U$340, U$399, U$458, U$517, U$576, U$635, U$694, U$753, U$812, U$871, U$930, U$989, U$1048, U$1107, U$1166, U$1225, U$1284, U$1343, U$1402: #PS1#895
U$36, U$63, U$122, U$181, U$240, U$299, U$358, U$417, U$476, U$535, U$594, U$653, U$712, U$771, U$830, U$889, U$948, U$1007, U$1066, U$1125, U$1184, U$1243, U$1302, U$1361: #3V3#865
U$37, U$64, U$123, U$182, U$241, U$300, U$359, U$418, U$477, U$536, U$595, U$654, U$713, U$772, U$831, U$890, U$949, U$1008, U$1067, U$1126, U$1185, U$1244, U$1303, U$1362: #SCK#866
U$38, U$68, U$127, U$186, U$245, U$304, U$363, U$422, U$481, U$540, U$599, U$658, U$717, U$776, U$835, U$894, U$953, U$1012, U$1071, U$1130, U$1189, U$1248, U$1307, U$1366: ##WAK##871
U$39, U$90, U$149, U$208, U$267, U$326, U$385, U$444, U$503, U$562, U$621, U$680, U$739, U$798, U$857, U$916, U$975, U$1034, U$1093, U$1152, U$1211, U$1270, U$1329, U$1388: #3V3#882
U$40, U$100, U$159, U$218, U$277, U$336, U$395, U$454, U$513, U$572, U$631, U$690, U$749, U$808, U$867, U$926, U$985, U$1044, U$1103, U$1162, U$1221, U$1280, U$1339, U$1398: 3V3891
U$41, U$99, U$158, U$217, U$276, U$335, U$394, U$453, U$512, U$571, U$630, U$689, U$748, U$807, U$866, U$925, U$984, U$1043, U$1102, U$1161, U$1220, U$1279, U$1338, U$1397: GRN890
U$42, U$70, U$129, U$188, U$247, U$306, U$365, U$424, U$483, U$542, U$601, U$660, U$719, U$778, U$837, U$896, U$955, U$1014, U$1073, U$1132, U$1191, U$1250, U$1309, U$1368: #PWR#873
U$43, U$73, U$132, U$191, U$250, U$309, U$368, U$427, U$486, U$545, U$604, U$663, U$722, U$781, U$840, U$899, U$958, U$1017, U$1076, U$1135, U$1194, U$1253, U$1312, U$1371: #PS1#874
U$44, U$89, U$148, U$207, U$266, U$325, U$384, U$443, U$502, U$561, U$620, U$679, U$738, U$797, U$856, U$915, U$974, U$1033, U$1092, U$1151, U$1210, U$1269, U$1328, U$1387: UART881
U$47, U$76, U$135, U$194, U$253, U$312, U$371, U$430, U$489, U$548, U$607, U$666, U$725, U$784, U$843, U$902, U$961, U$1020, U$1079, U$1138, U$1197, U$1256, U$1315, U$1374: #SDA#874
U$48, U$77, U$136, U$195, U$254, U$313, U$372, U$431, U$490, U$549, U$608, U$667, U$726, U$785, U$844, U$903, U$962, U$1021, U$1080, U$1139, U$1198, U$1257, U$1316, U$1375: #SCL#875
U$49, U$97, U$156, U$215, U$274, U$333, U$392, U$451, U$510, U$569, U$628, U$687, U$746, U$805, U$864, U$923, U$982, U$1041, U$1100, U$1159, U$1218, U$1277, U$1336, U$1395: #BOOT#888
U$50, U$78, U$137, U$196, U$255, U$314, U$373, U$432, U$491, U$550, U$609, U$668, U$727, U$786, U$845, U$904, U$963, U$1022, U$1081, U$1140, U$1199, U$1258, U$1317, U$1376: ##RST##876
U$51, U$79, U$138, U$197, U$256, U$315, U$374, U$433, U$492, U$551, U$610, U$669, U$728, U$787, U$846, U$905, U$964, U$1023, U$1082, U$1141, U$1200, U$1259, U$1318, U$1377: ##INT##877
U$52, U$87, U$146, U$205, U$264, U$323, U$382, U$441, U$500, U$559, U$618, U$677, U$736, U$795, U$854, U$913, U$972, U$1031, U$1090, U$1149, U$1208, U$1267, U$1326, U$1385: QWIIC_6MM
U$53, U$95, U$154, U$213, U$272, U$331, U$390, U$449, U$508, U$567, U$626, U$685, U$744, U$803, U$862, U$921, U$980, U$1039, U$1098, U$1157, U$1216, U$1275, U$1334, U$1393: ##WAK##886
U$54, U$88, U$147, U$206, U$265, U$324, U$383, U$442, U$501, U$560, U$619, U$678, U$737, U$796, U$855, U$914, U$973, U$1032, U$1091, U$1150, U$1209, U$1268, U$1327, U$1386: BNO086_IMU881
U$55, U$92, U$151, U$210, U$269, U$328, U$387, U$446, U$505, U$564, U$623, U$682, U$741, U$800, U$859, U$918, U$977, U$1036, U$1095, U$1154, U$1213, U$1272, U$1331, U$1390: #SO#883
U$56, U$93, U$152, U$211, U$270, U$329, U$388, U$447, U$506, U$565, U$624, U$683, U$742, U$801, U$860, U$919, U$978, U$1037, U$1096, U$1155, U$1214, U$1273, U$1332, U$1391: #SI#884
U$57, U$105, U$164, U$223, U$282, U$341, U$400, U$459, U$518, U$577, U$636, U$695, U$754, U$813, U$872, U$931, U$990, U$1049, U$1108, U$1167, U$1226, U$1285, U$1344, U$1403: #PS0#895
U$58, U$117, U$176, U$235, U$294, U$353, U$412, U$471, U$530, U$589, U$648, U$707, U$766, U$825, U$884, U$943, U$1002, U$1061, U$1120, U$1179, U$1238, U$1297, U$1356, U$1415: CLOSED#0X4A0
U$61, U$118, U$177, U$236, U$295, U$354, U$413, U$472, U$531, U$590, U$649, U$708, U$767, U$826, U$885, U$944, U$1003, U$1062, U$1121, U$1180, U$1239, U$1298, U$1357, U$1416: DEFAULT0
Y1, Y2, Y3, Y4, Y5, Y6, Y7, Y8, Y9, Y10, Y11, Y12, Y13, Y14, Y15, Y16, Y17, Y18, Y19, Y20, Y21, Y22, Y23, Y24: 32.768kHz; CRYSTAL-SMD-3.2X1.5MM

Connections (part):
3.3V: C2.1, C4.1, I2C.2, J1.3, J2.2, J3.2, J4.2, J6.2, LED.1, PS0.1, PS1.1, R1.2, R3.2, R6.2, R9.2, R10.2, U2.3, U2.28
3.3V1: C6.1, C8.1, I2C1.2, J9.2, J11.3, J14.2, J15.2, J16.2, LED1.1, PS2.1, PS3.1, R4.2, R5.2, R11.2, R16.2, R17.2, U1.3, U1.28
3.3V2: C11.1, C13.1, I2C2.2, J17.2, J19.3, J22.2, J23.2, J24.2, LED2.1, PS4.1, PS5.1, R21.2, R22.2, R23.2, R26.2, R27.2, U3.3, U3.28
3.3V3: C16.1, C18.1, I2C3.2, J25.2, J27.3, J30.2, J31.2, J32.2, LED3.1, PS6.1, PS7.1, R31.2, R32.2, R33.2, R36.2, R37.2, U4.3, U4.28
3.3V4: C21.1, C23.1, I2C4.2, J33.2, J35.3, J38.2, J39.2, J40.2, LED4.1, PS8.1, PS9.1, R41.2, R42.2, R43.2, R46.2, R47.2, U5.3, U5.28
3.3V5: C26.1, C28.1, I2C5.2, J41.2, J43.3, J46.2, J47.2, J48.2, LED5.1, PS10.1, PS11.1, R51.2, R52.2, R53.2, R56.2, R57.2, U6.3, U6.28
3.3V6: C31.1, C33.1, I2C6.2, J49.2, J51.3, J54.2, J55.2, J56.2, LED6.1, PS12.1, PS13.1, R61.2, R62.2, R63.2, R66.2, R67.2, U7.3, U7.28
3.3V7: C36.1, C38.1, I2C7.2, J57.2, J59.3, J62.2, J63.2, J64.2, LED7.1, PS14.1, PS15.1, R71.2, R72.2, R73.2, R76.2, R77.2, U8.3, U8.28
3.3V8: C41.1, C43.1, I2C8.2, J65.2, J67.3, J70.2, J71.2, J72.2, LED8.1, PS16.1, PS17.1, R81.2, R82.2, R83.2, R86.2, R87.2, U9.3, U9.28
3.3V9: C46.1, C48.1, I2C9.2, J73.2, J75.3, J78.2, J79.2, J80.2, LED9.1, PS18.1, PS19.1, R91.2, R92.2, R93.2, R96.2, R97.2, U10.3, U10.28
3.3V10: C51.1, C53.1, I2C10.2, J81.2, J83.3, J86.2, J87.2, J88.2, LED10.1, PS20.1, PS21.1, R101.2, R102.2, R103.2, R106.2, R107.2, U11.3, U11.28
3.3V11: C56.1, C58.1, I2C11.2, J89.2, J91.3, J94.2, J95.2, J96.2, LED11.1, PS22.1, PS23.1, R111.2, R112.2, R113.2, R116.2, R117.2, U12.3, U12.28
3.3V12: C61.1, C63.1, I2C12.2, J97.2, J99.3, J102.2, J103.2, J104.2, LED12.1, PS24.1, PS25.1, R121.2, R122.2, R123.2, R126.2, R127.2, U13.3, U13.28
3.3V13: C66.1, C68.1, I2C13.2, J105.2, J107.3, J110.2, J111.2, J112.2, LED13.1, PS26.1, PS27.1, R131.2, R132.2, R133.2, R136.2, R137.2, U14.3, U14.28
3.3V14: C71.1, C73.1, I2C14.2, J113.2, J115.3, J118.2, J119.2, J120.2, LED14.1, PS28.1, PS29.1, R141.2, R142.2, R143.2, R146.2, R147.2, U15.3, U15.28
3.3V15: C76.1, C78.1, I2C15.2, J121.2, J123.3, J126.2, J127.2, J128.2, LED15.1, PS30.1, PS31.1, R151.2, R152.2, R153.2, R156.2, R157.2, U16.3, U16.28
3.3V16: C81.1, C83.1, I2C16.2, J129.2, J131.3, J134.2, J135.2, J136.2, LED16.1, PS32.1, PS33.1, R161.2, R162.2, R163.2, R166.2, R167.2, U17.3, U17.28
3.3V17: C86.1, C88.1, I2C17.2, J137.2, J139.3, J142.2, J143.2, J144.2, LED17.1, PS34.1, PS35.1, R171.2, R172.2, R173.2, R176.2, R177.2, U18.3, U18.28
3.3V18: C91.1, C93.1, I2C18.2, J145.2, J147.3, J150.2, J151.2, J152.2, LED18.1, PS36.1, PS37.1, R181.2, R182.2, R183.2, R186.2, R187.2, U19.3, U19.28
3.3V19: C96.1, C98.1, I2C19.2, J153.2, J155.3, J158.2, J159.2, J160.2, LED19.1, PS38.1, PS39.1, R191.2, R192.2, R193.2, R196.2, R197.2, U20.3, U20.28
3.3V20: C101.1, C103.1, I2C20.2, J161.2, J163.3, J166.2, J167.2, J168.2, LED20.1, PS40.1, PS41.1, R201.2, R202.2, R203.2, R206.2, R207.2, U21.3, U21.28
3.3V21: C106.1, C108.1, I2C21.2, J169.2, J171.3, J174.2, J175.2, J176.2, LED21.1, PS42.1, PS43.1, R211.2, R212.2, R213.2, R216.2, R217.2, U22.3, U22.28
3.3V22: C111.1, C113.1, I2C22.2, J177.2, J179.3, J182.2, J183.2, J184.2, LED22.1, PS44.1, PS45.1, R221.2, R222.2, R223.2, R226.2, R227.2, U23.3, U23.28
3.3V23: C116.1, C118.1, I2C23.2, J185.2, J187.3, J190.2, J191.2, J192.2, LED23.1, PS46.1, PS47.1, R231.2, R232.2, R233.2, R236.2, R237.2, U24.3, U24.28
!BOOT: J5.1, R6.1, U2.4
!BOOT1: J12.1, R11.1, U1.4
!BOOT2: J20.1, R23.1, U3.4
!BOOT3: J28.1, R33.1, U4.4
!BOOT4: J36.1, R43.1, U5.4
!BOOT5: J44.1, R53.1, U6.4
!BOOT6: J52.1, R63.1, U7.4
!BOOT7: J60.1, R73.1, U8.4
!BOOT8: J68.1, R83.1, U9.4
!BOOT9: J76.1, R93.1, U10.4
!BOOT10: J84.1, R103.1, U11.4
!BOOT11: J92.1, R113.1, U12.4
!BOOT12: J100.1, R123.1, U13.4
!BOOT13: J108.1, R133.1, U14.4
!BOOT14: J116.1, R143.1, U15.4
!BOOT15: J124.1, R153.1, U16.4
!BOOT16: J132.1, R163.1, U17.4
!BOOT17: J140.1, R173.1, U18.4
!BOOT18: J148.1, R183.1, U19.4
!BOOT19: J156.1, R193.1, U20.4
!BOOT20: J164.1, R203.1, U21.4
!BOOT21: J172.1, R213.1, U22.4
!BOOT22: J180.1, R223.1, U23.4
!BOOT23: J188.1, R233.1, U24.4
!CS: J6.6, U2.18
!CS1: J9.6, U1.18
!CS2: J17.6, U3.18
!CS3: J25.6, U4.18
!CS4: J33.6, U5.18
!CS5: J41.6, U6.18
!CS6: J49.6, U7.18
!CS7: J57.6, U8.18
!CS8: J65.6, U9.18
!CS9: J73.6, U10.18
!CS10: J81.6, U11.18
!CS11: J89.6, U12.18
!CS12: J97.6, U13.18
!CS13: J105.6, U14.18
!CS14: J113.6, U15.18
!CS15: J121.6, U16.18
!CS16: J129.6, U17.18
!CS17: J137.6, U18.18
!CS18: J145.6, U19.18
!CS19: J153.6, U20.18
!CS20: J161.6, U21.18
!CS21: J169.6, U22.18
!CS22: J177.6, U23.18
!CS23: J185.6, U24.18
!INT: J7.2, U2.14
!INT1: J10.2, U1.14
!INT2: J18.2, U3.14
!INT3: J26.2, U4.14
!INT4: J34.2, U5.14
!INT5: J42.2, U6.14
!INT6: J50.2, U7.14
!INT7: J58.2, U8.14
!INT8: J66.2, U9.14
!INT9: J74.2, U10.14
!INT10: J82.2, U11.14
!INT11: J90.2, U12.14
!INT12: J98.2, U13.14
!INT13: J106.2, U14.14
!INT14: J114.2, U15.14
!INT15: J122.2, U16.14
!INT16: J130.2, U17.14
!INT17: J138.2, U18.14
!INT18: J146.2, U19.14
!INT19: J154.2, U20.14
!INT20: J162.2, U21.14
!INT21: J170.2, U22.14
!INT22: J178.2, U23.14
!INT23: J186.2, U24.14
!RST: J6.8, J7.1, R1.1, U2.11
!RST1: J9.8, J10.1, R4.1, U1.11
!RST2: J17.8, J18.1, R21.1, U3.11
!RST3: J25.8, J26.1, R31.1, U4.11
!RST4: J33.8, J34.1, R41.1, U5.11
!RST5: J41.8, J42.1, R51.1, U6.11
!RST6: J49.8, J50.1, R61.1, U7.11
!RST7: J57.8, J58.1, R71.1, U8.11
!RST8: J65.8, J66.1, R81.1, U9.11
!RST9: J73.8, J74.1, R91.1, U10.11
!RST10: J81.8, J82.1, R101.1, U11.11
!RST11: J89.8, J90.1, R111.1, U12.11
!RST12: J97.8, J98.1, R121.1, U13.11
!RST13: J105.8, J106.1, R131.1, U14.11
!RST14: J113.8, J114.1, R141.1, U15.11
!RST15: J121.8, J122.1, R151.1, U16.11
!RST16: J129.8, J130.1, R161.1, U17.11
!RST17: J137.8, J138.1, R171.1, U18.11
!RST18: J145.8, J146.1, R181.1, U19.11
!RST19: J153.8, J154.1, R191.1, U20.11
!RST20: J161.8, J162.1, R201.1, U21.11
!RST21: J169.8, J170.1, R211.1, U22.11
!RST22: J177.8, J178.1, R221.1, U23.11
!RST23: J185.8, J186.1, R231.1, U24.11
ADDR/MOSI: ADR.2, J6.5, R3.1, U2.17
ADDR/MOSI1: ADR1.2, J9.5, R5.1, U1.17
ADDR/MOSI2: ADR2.2, J17.5, R22.1, U3.17
ADDR/MOSI3: ADR3.2, J25.5, R32.1, U4.17
ADDR/MOSI4: ADR4.2, J33.5, R42.1, U5.17
ADDR/MOSI5: ADR5.2, J41.5, R52.1, U6.17
ADDR/MOSI6: ADR6.2, J49.5, R62.1, U7.17
ADDR/MOSI7: ADR7.2, J57.5, R72.1, U8.17
ADDR/MOSI8: ADR8.2, J65.5, R82.1, U9.17
ADDR/MOSI9: ADR9.2, J73.5, R92.1, U10.17
ADDR/MOSI10: ADR10.2, J81.5, R102.1, U11.17
ADDR/MOSI11: ADR11.2, J89.5, R112.1, U12.17
ADDR/MOSI12: ADR12.2, J97.5, R122.1, U13.17
ADDR/MOSI13: ADR13.2, J105.5, R132.1, U14.17
ADDR/MOSI14: ADR14.2, J113.5, R142.1, U15.17
ADDR/MOSI15: ADR15.2, J121.5, R152.1, U16.17
ADDR/MOSI16: ADR16.2, J129.5, R162.1, U17.17
ADDR/MOSI17: ADR17.2, J137.5, R172.1, U18.17
ADDR/MOSI18: ADR18.2, J145.5, R182.1, U19.17
ADDR/MOSI19: ADR19.2, J153.5, R192.1, U20.17
ADDR/MOSI20: ADR20.2, J161.5, R202.1, U21.17
ADDR/MOSI21: ADR21.2, J169.5, R212.1, U22.17
ADDR/MOSI22: ADR22.2, J177.5, R222.1, U23.17
ADDR/MOSI23: ADR23.2, J185.5, R232.1, U24.17
CAP: C1.1, U2.9
CAP1: C7.1, U1.9
CAP2: C12.1, U3.9
CAP3: C17.1, U4.9
CAP4: C22.1, U5.9
CAP5: C27.1, U6.9
CAP6: C32.1, U7.9
CAP7: C37.1, U8.9
CAP8: C42.1, U9.9
CAP9: C47.1, U10.9
CAP10: C52.1, U11.9
CAP11: C57.1, U12.9
CAP12: C62.1, U13.9
CAP13: C67.1, U14.9
CAP14: C72.1, U15.9
CAP15: C77.1, U16.9
CAP16: C82.1, U17.9
CAP17: C87.1, U18.9
CAP18: C92.1, U19.9
CAP19: C97.1, U20.9
CAP20: C102.1, U21.9
CAP21: C107.1, U22.9
CAP22: C112.1, U23.9
CAP23: C117.1, U24.9
GND: ADR.1, C1.2, C2.2, C3.2, C4.2, C5.2, J1.1, J2.1, J3.1, J4.1, J6.1, R2.1, R7.1, R8.1, U2.2, U2.10, U2.25
GND1: ADR1.1, C6.2, C7.2, C8.2, C9.2, C10.2, J9.1, J11.1, J14.1, J15.1, J16.1, R14.1, R15.1, R20.1, U1.2, U1.10, U1.25
GND2: ADR2.1, C11.2, C12.2, C13.2, C14.2, C15.2, J17.1, J19.1, J22.1, J23.1, J24.1, R24.1, R25.1, R30.1, U3.2, U3.10, U3.25
GND3: ADR3.1, C16.2, C17.2, C18.2, C19.2, C20.2, J25.1, J27.1, J30.1, J31.1, J32.1, R34.1, R35.1, R40.1, U4.2, U4.10, U4.25
GND4: ADR4.1, C21.2, C22.2, C23.2, C24.2, C25.2, J33.1, J35.1, J38.1, J39.1, J40.1, R44.1, R45.1, R50.1, U5.2, U5.10, U5.25
GND5: ADR5.1, C26.2, C27.2, C28.2, C29.2, C30.2, J41.1, J43.1, J46.1, J47.1, J48.1, R54.1, R55.1, R60.1, U6.2, U6.10, U6.25
GND6: ADR6.1, C31.2, C32.2, C33.2, C34.2, C35.2, J49.1, J51.1, J54.1, J55.1, J56.1, R64.1, R65.1, R70.1, U7.2, U7.10, U7.25
GND7: ADR7.1, C36.2, C37.2, C38.2, C39.2, C40.2, J57.1, J59.1, J62.1, J63.1, J64.1, R74.1, R75.1, R80.1, U8.2, U8.10, U8.25
GND8: ADR8.1, C41.2, C42.2, C43.2, C44.2, C45.2, J65.1, J67.1, J70.1, J71.1, J72.1, R84.1, R85.1, R90.1, U9.2, U9.10, U9.25
GND9: ADR9.1, C46.2, C47.2, C48.2, C49.2, C50.2, J73.1, J75.1, J78.1, J79.1, J80.1, R94.1, R95.1, R100.1, U10.2, U10.10, U10.25
GND10: ADR10.1, C51.2, C52.2, C53.2, C54.2, C55.2, J81.1, J83.1, J86.1, J87.1, J88.1, R104.1, R105.1, R110.1, U11.2, U11.10, U11.25
GND11: ADR11.1, C56.2, C57.2, C58.2, C59.2, C60.2, J89.1, J91.1, J94.1, J95.1, J96.1, R114.1, R115.1, R120.1, U12.2, U12.10, U12.25
GND12: ADR12.1, C61.2, C62.2, C63.2, C64.2, C65.2, J97.1, J99.1, J102.1, J103.1, J104.1, R124.1, R125.1, R130.1, U13.2, U13.10, U13.25
GND13: ADR13.1, C66.2, C67.2, C68.2, C69.2, C70.2, J105.1, J107.1, J110.1, J111.1, J112.1, R134.1, R135.1, R140.1, U14.2, U14.10, U14.25
GND14: ADR14.1, C71.2, C72.2, C73.2, C74.2, C75.2, J113.1, J115.1, J118.1, J119.1, J120.1, R144.1, R145.1, R150.1, U15.2, U15.10, U15.25
GND15: ADR15.1, C76.2, C77.2, C78.2, C79.2, C80.2, J121.1, J123.1, J126.1, J127.1, J128.1, R154.1, R155.1, R160.1, U16.2, U16.10, U16.25
GND16: ADR16.1, C81.2, C82.2, C83.2, C84.2, C85.2, J129.1, J131.1, J134.1, J135.1, J136.1, R164.1, R165.1, R170.1, U17.2, U17.10, U17.25
GND17: ADR17.1, C86.2, C87.2, C88.2, C89.2, C90.2, J137.1, J139.1, J142.1, J143.1, J144.1, R174.1, R175.1, R180.1, U18.2, U18.10, U18.25
GND18: ADR18.1, C91.2, C92.2, C93.2, C94.2, C95.2, J145.1, J147.1, J150.1, J151.1, J152.1, R184.1, R185.1, R190.1, U19.2, U19.10, U19.25
GND19: ADR19.1, C96.2, C97.2, C98.2, C99.2, C100.2, J153.1, J155.1, J158.1, J159.1, J160.1, R194.1, R195.1, R200.1, U20.2, U20.10, U20.25
GND20: ADR20.1, C101.2, C102.2, C103.2, C104.2, C105.2, J161.1, J163.1, J166.1, J167.1, J168.1, R204.1, R205.1, R210.1, U21.2, U21.10, U21.25
GND21: ADR21.1, C106.2, C107.2, C108.2, C109.2, C110.2, J169.1, J171.1, J174.1, J175.1, J176.1, R214.1, R215.1, R220.1, U22.2, U22.10, U22.25
GND22: ADR22.1, C111.2, C112.2, C113.2, C114.2, C115.2, J177.1, J179.1, J182.1, J183.1, J184.1, R224.1, R225.1, R230.1, U23.2, U23.10, U23.25
GND23: ADR23.1, C116.2, C117.2, C118.2, C119.2, C120.2, J185.1, J187.1, J190.1, J191.1, J192.1, R234.1, R235.1, R240.1, U24.2, U24.10, U24.25
unnamed: C5.1, U2.27, Y1.P$2
unnamed: C3.1, U2.26, Y1.P$1
unnamed: PWR.C, R2.2
unnamed: LED.2, PWR.A
unnamed: C10.1, U1.27, Y2.P$2
unnamed: C9.1, U1.26, Y2.P$1
unnamed: PWR1.C, R20.2
unnamed: LED1.2, PWR1.A
unnamed: C15.1, U3.27, Y3.P$2
unnamed: C14.1, U3.26, Y3.P$1
unnamed: PWR2.C, R30.2
unnamed: LED2.2, PWR2.A
unnamed: C20.1, U4.27, Y4.P$2
unnamed: C19.1, U4.26, Y4.P$1
unnamed: PWR3.C, R40.2
unnamed: LED3.2, PWR3.A
unnamed: C25.1, U5.27, Y5.P$2
unnamed: C24.1, U5.26, Y5.P$1
unnamed: PWR4.C, R50.2
unnamed: LED4.2, PWR4.A
unnamed: C30.1, U6.27, Y6.P$2
unnamed: C29.1, U6.26, Y6.P$1
unnamed: PWR5.C, R60.2
unnamed: LED5.2, PWR5.A
unnamed: C35.1, U7.27, Y7.P$2
unnamed: C34.1, U7.26, Y7.P$1
unnamed: PWR6.C, R70.2
unnamed: LED6.2, PWR6.A
unnamed: C40.1, U8.27, Y8.P$2
unnamed: C39.1, U8.26, Y8.P$1
unnamed: PWR7.C, R80.2
unnamed: LED7.2, PWR7.A
unnamed: C45.1, U9.27, Y9.P$2
unnamed: C44.1, U9.26, Y9.P$1
unnamed: PWR8.C, R90.2
unnamed: LED8.2, PWR8.A
unnamed: C50.1, U10.27, Y10.P$2
unnamed: C49.1, U10.26, Y10.P$1
unnamed: PWR9.C, R100.2
unnamed: LED9.2, PWR9.A
unnamed: C55.1, U11.27, Y11.P$2
unnamed: C54.1, U11.26, Y11.P$1
unnamed: PWR10.C, R110.2
unnamed: LED10.2, PWR10.A
unnamed: C60.1, U12.27, Y12.P$2
unnamed: C59.1, U12.26, Y12.P$1
unnamed: PWR11.C, R120.2
unnamed: LED11.2, PWR11.A
unnamed: C65.1, U13.27, Y13.P$2
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

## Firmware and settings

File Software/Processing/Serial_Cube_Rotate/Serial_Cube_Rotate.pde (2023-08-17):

/**
 * <p>The ToxiclibsSupport class of the toxi.processing package provides various
 * shortcuts to directly use toxiclibs geometry datatypes with Processing style
 * drawing operations. Most of these are demonstrated in this example.</p>
 *
 * <p>UPDATES:
 * <ul>
 * <li>2010-12-30: added sphere/cylinder resolution modulation</li>
 * </ul></p>
 */
 
/* 
 * Copyright (c) 2010 Karsten Schmidt
 * 
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
 * http://creativecommons.org/licenses/LGPL/2.1/
 * 
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
 * You should have received a copy of the GNU Lesser General Public
 * License along with this library; if not, write to the Free Software
 * Foundation, Inc., 51 Franklin St, Fifth Floor, Boston, MA  02110-1301  USA
 */

//Download and manually install "toxiclibs-complete-0021.zip" => https://github.com/postspectacular/toxiclibs/releases/tag/0021
//Make sure to install in the correct path using Processing 3 => https://github.com/processing/processing/wiki/How-to-Install-a-Contributed-Library#manual-install
import toxi.geom.*;
import toxi.geom.mesh.*;
import toxi.math.waves.*;
import toxi.processing.*;
import processing.serial.*;

String myString = null;
Serial myPort;  // The serial port

ToxiclibsSupport gfx;

boolean waitFlag = true;

void setup() {
  size(600,600,P3D);
  gfx=new ToxiclibsSupport(this);
  
  background(255);
  noStroke();
  fill(200,200,200);
  
  // Print a list of connected serial devices in the console
  printArray(Serial.list());
  // Depending on where your BNO086 falls on this list, you
  // may need to change Serial.list()[0] to a different number
  myPort = new Serial(this, Serial.list()[0], 9600); //115200 baud seems to be too much for Processing?... 9600 baud seems better
  delay(50); //small delay as we wait for the ESP32 to initialize since it outputs serial on boot, this seems to help
  
  myPort.clear();
  // Throw out the first chunk in case we caught it in the 
  // middle of a frame
  myString = myPort.readStringUntil(13);
  myString = null;  
}

void draw() {
  
  Quaternion RotQ = new Quaternion(1,0,0,0);
  float qMatrix[] = {0,0,0,0,0,0,0,0,0,0,0,0,0,0,0,0};
  PMatrix M1 = getMatrix();
  
  // When there is a sizeable amount of data on the serial port
  // read everything up to the first linefeed
  if(myPort.available() > 30){
    myString = myPort.readStringUntil(13);

    // generate an array of strings that contains each of the commas
    // separated values
    String inQuat[] = splitTokens(myString, ",");  
    
    // make sure that inQuat has a length of 4 before proceeding
    if (inQuat.length == 4){
      // build a Quaternion from inQuat[] array
      RotQ = new Quaternion(float(inQuat[0]), float(inQuat[1]), float(inQuat[2]),float(inQuat[3]));

      RotQ.toMatrix4x4().toFloatArray(qMatrix);

      M1.set(
      qMatrix[0], 
      qMatrix[1], 
      qMatrix[2], 
      qMatrix[3], 
      qMatrix[4], 
      qMatrix[5], 
      qMatrix[6], 
      qMatrix[7], 
      qMatrix[8], 
      qMatrix[9], 
      qMatrix[10], 
      qMatrix[11], 
      qMatrix[12], 
      qMatrix[13], 
      qMatrix[14], 
      qMatrix[15]
      );

      AABB cube;

      background(255);

      // Set some mood lighting
      ambientLight(128, 128, 128);
      directionalLight(128, 128, 128, 0, 0, 1);
      lightFalloff(1, 0, 0);
      lightSpecular(0, 0, 0);

      // Get to the middle of the screen
      translate(width/2,height/2,0);

      // Do some rotates to get oriented "behind" the device
      rotateX(-PI/2);

      // Apply the Matrix that we generated from our IMU Quaternion
      applyMatrix(M1);

      // Draw the Cube from a 3D Bounding Box
      cube=new AABB(new Vec3D(0,0,0),new Vec3D(100,100,100));
      gfx.box(cube);
    }
  }else{
    if(waitFlag){
    textSize(32);
    text("Waiting for quaternions to chew on...", 10, 30); 
    waitFlag = false;}
  }
}

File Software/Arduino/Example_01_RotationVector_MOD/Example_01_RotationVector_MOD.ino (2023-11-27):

/*
  Using the BNO08x IMU

  This example shows how to output the i/j/k/real parts of the rotation vector.
  https://en.wikipedia.org/wiki/Quaternions_and_spatial_rotation

  Note that this is a modified example which comments out unnecessary Serial Prints
  so that we can simply output the comma separated values of the rotation vector
  for the Processing demo "Serial_Cube_Rotate.pde".
  
  By: Nathan Seidle
  SparkFun Electronics
  Date: December 21st, 2017
  SparkFun code, firmware, and software is released under the MIT License.
	Please see LICENSE.md for further details.

  Originally written by Nathan Seidle @ SparkFun Electronics, December 28th, 2017

  Adjusted by Pete Lewis @ SparkFun Electronics, June 2023 to incorporate the
  CEVA Sensor Hub Driver, found here:
  https://github.com/ceva-dsp/sh2

  Also, utilizing code from the Adafruit BNO08x Arduino Library by Bryan Siepert
  for Adafruit Industries. Found here:
  https://github.com/adafruit/Adafruit_BNO08x

  Also, utilizing I2C and SPI read/write functions and code from the Adafruit
  BusIO library found here:
  https://github.com/adafruit/Adafruit_BusIO

  Hardware Connections:
  IoT RedBoard --> BNO08x
  QWIIC --> QWIIC
  A4  --> INT
  A5  --> RST

  BNO08x "mode" jumpers set for I2C (default):
  PSO: OPEN
  PS1: OPEN

  Serial.print it out at 115200 baud to serial monitor.

  Feel like supporting our work? Buy a board from SparkFun!
  https://www.sparkfun.com/products/22857
*/

#include <Wire.h>

#include "SparkFun_BNO08x_Arduino_Library.h"  // CTRL+Click here to get the library: http://librarymanager/All#SparkFun_BNO08x
BNO08x myIMU;

// For the most reliable interaction with the SHTP bus, we need
// to use hardware reset control, and to monitor the H_INT pin.
// The H_INT pin will go low when its okay to talk on the SHTP bus.
// Note, these can be other GPIO if you like.
// Define as -1 to disable these features.
#define BNO08X_INT  A4
//#define BNO08X_INT  -1
#define BNO08X_RST  A5
//#define BNO08X_RST  -1

#define BNO08X_ADDR 0x4B  // SparkFun BNO08x Breakout (Qwiic) defaults to 0x4B
//#define BNO08X_ADDR 0x4A // Alternate address if ADR jumper is closed

void setup() {
  Serial.begin(9600); //115200 baud seems to be too much for Processing?... 9600 baud seems better
  
  //while(!Serial) delay(10); // Wait for Serial to become available.
  // Necessary for boards with native USB (like the SAMD51 Thing+).
  // For a final version of a project that does not need serial debug (or a USB cable plugged in),
  // Comment out this while loop, or it will prevent the remaining code from running.
  
  //Serial.println();
  //Serial.println("BNO08x Read Example");

  Wire.begin();

  //if (myIMU.begin() == false) {  // Setup without INT/RST control (Not Recommended)
  if (myIMU.begin(BNO08X_ADDR, Wire, BNO08X_INT, BNO08X_RST) == false) {
    Serial.println("BNO08x not detected at default I2C address. Check your jumpers and the hookup guide. Freezing...");
    while (1)
      ;
  }
  Serial.println("BNO08x found!");

  // Wire.setClock(400000); //Increase I2C data rate to 400kHz

  setReports();

  Serial.println("Reading events");
  delay(100);
}

// Here is where you define the sensor outputs you want to receive
void setReports(void) {
  Serial.println("Setting desired reports");
  if (myIMU.enableRotationVector() == true) {
    //Serial.println(F("Rotation vector enabled"));
    //Serial.println(F("Output in form real, i, j, k, accuracy"));
  } else {
    //Serial.println("Could not enable rotation vector");
  }
}

void loop() {
  delay(10);

  if (myIMU.wasReset()) {
    //Serial.print("sensor was reset ");
    setReports();
  }

  // Has a new event come in on the Sensor Hub Bus?
  if (myIMU.getSensorEvent() == true) {

    // is it the correct sensor data we want?
    if (myIMU.getSensorEventID() == SENSOR_REPORTID_ROTATION_VECTOR) {

      float quatI = myIMU.getQuatI();
      float quatJ = myIMU.getQuatJ();
      float quatK = myIMU.getQuatK();
      float quatReal = myIMU.getQuatReal();
      float quatRadianAccuracy = myIMU.getQuatRadianAccuracy();

      Serial.print(quatReal, 2); //<==move these two lines of code
      Serial.print(F(","));      //   for Processing
      Serial.print(quatI, 2);
      Serial.print(F(","));
      Serial.print(quatJ, 2);
      Serial.print(F(","));
      Serial.print(quatK, 2);
      //Serial.print(F(","));
      //Serial.print(quatRadianAccuracy, 2);

      Serial.println();
    }
  }
}

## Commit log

2023-06-28 Starting from v10 version of BNO080
    [Qwiic_IMU_Bonobo.brd, Qwiic_IMU_Bonobo.sch]
2023-06-28 Silk updated to BNO086 and vectors
    -Product name silk updated to BNO086
    -all silk updated to vector buzzard style
    -Jumpers updated to newest packages
    [Qwiic_IMU_Bonobo.brd, Qwiic_IMU_Bonobo.sch]
2023-06-28 Ordering instructions added
    [Qwiic_IMU_Bonobo.brd]
2023-06-28 minor stuff - measures, library work
    -added measures and units
    -replaced some connectors, fids, standoffs, GND symbols to newer libraries.
    -renamed jumpers (in SCH) to match silk names (on board).
    -Red LED to new King Bright version, also updated resistor value to 4.7K
    -some minor schematic cleanup
    [Qwiic_IMU_Bonobo.brd, Qwiic_IMU_Bonobo.sch]
2023-06-28 update file name to match product
    [SparkFun_VR_IMU_Breakout_BNO086_QWIIC.brd, SparkFun_VR_IMU_Breakout_BNO086_QWIIC.sch]
2023-06-28 some more final changes
    -added name to revisioner on sch and brd
    -moved sch section names to symbol layer, added IMU name
    -fixed two DRC errors (angle and stub)
    -added more GND vias
    -Axis labels - break linear line to show rotation line going over
    -Larger SFE flame logo
    [SparkFun_VR_IMU_Breakout_BNO086_QWIIC.brd, SparkFun_VR_IMU_Breakout_BNO086_QWIIC.sch]
2023-06-29 3V3 net to thicker trace and more
    -upped 3v3 trace to 20mil
    -nudges some vias/traces for better GND flow
    -added more gnd vias
    -reduced GND pour isolates from 12 to 10
    -I2C pullup jumper changes to NC trace
    -updated IC to 086, in temp library for now
    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
    [SparkFun_VR_IMU_Breakout_BNO086_QWIIC.brd, SparkFun_VR_IMU_Breakout_BNO086_QWIIC.sch]
2023-06-29 line in sch to dash, address options in silk
    -corrected a line in SCH to match others as dashed
    -Added bottom silk to show address options
    [SparkFun_VR_IMU_Breakout_BNO086_QWIIC.brd, SparkFun_VR_IMU_Breakout_BNO086_QWIIC.sch]
2023-06-30 production panel and gerbers v10
    [SparkFun_VR_IMU_Breakout_BNO086_QWIIC-Panel.GBL, SparkFun_VR_IMU_Breakout_BNO086_QWIIC-Panel.GBP, SparkFun_VR_IMU_Breakout_BNO086_QWIIC-Panel.GBS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]
2023-10-17 Add Circuit Diagrams for UART and SPI, link Fritzing Part
2023-11-14 Remove "Hide" from Style
    - Remove the "hide" from the style to ensure that the images/tutorials show up when printing
2023-11-17 Update Tutorial to Reflect Changes for BNO086's Arduino Library v1.0.3
2023-11-30 Adding Hillscrest's Self Calibration document
    Added calibration pdf to resources

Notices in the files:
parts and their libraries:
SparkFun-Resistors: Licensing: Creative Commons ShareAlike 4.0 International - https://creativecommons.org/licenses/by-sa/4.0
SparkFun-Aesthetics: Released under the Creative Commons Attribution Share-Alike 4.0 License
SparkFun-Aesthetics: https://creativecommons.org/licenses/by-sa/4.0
